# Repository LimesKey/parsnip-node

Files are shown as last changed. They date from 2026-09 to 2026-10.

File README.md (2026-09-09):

# parsnip-node
A battery-powered, portable Meshtastic/Meshcore node built around the ESP32-S3, an Ebyte E22P-915M30S LoRa front end, and a u-blox NEO-M9N GNSS receiver. Designed in KiCad, it targets 915 MHz operation in Canada under ISED RSS-247.

## Overview

The goal is a self-contained LoRa node that pairs one of the longest range, best value LoRa modules, with an accurate GNSS reciever, running off two 21700 cells in series, to connect to other people on the LoRa mesh network community.

### Schematic - v2

<table>
  <tr>
    <td align="center" width="33%">
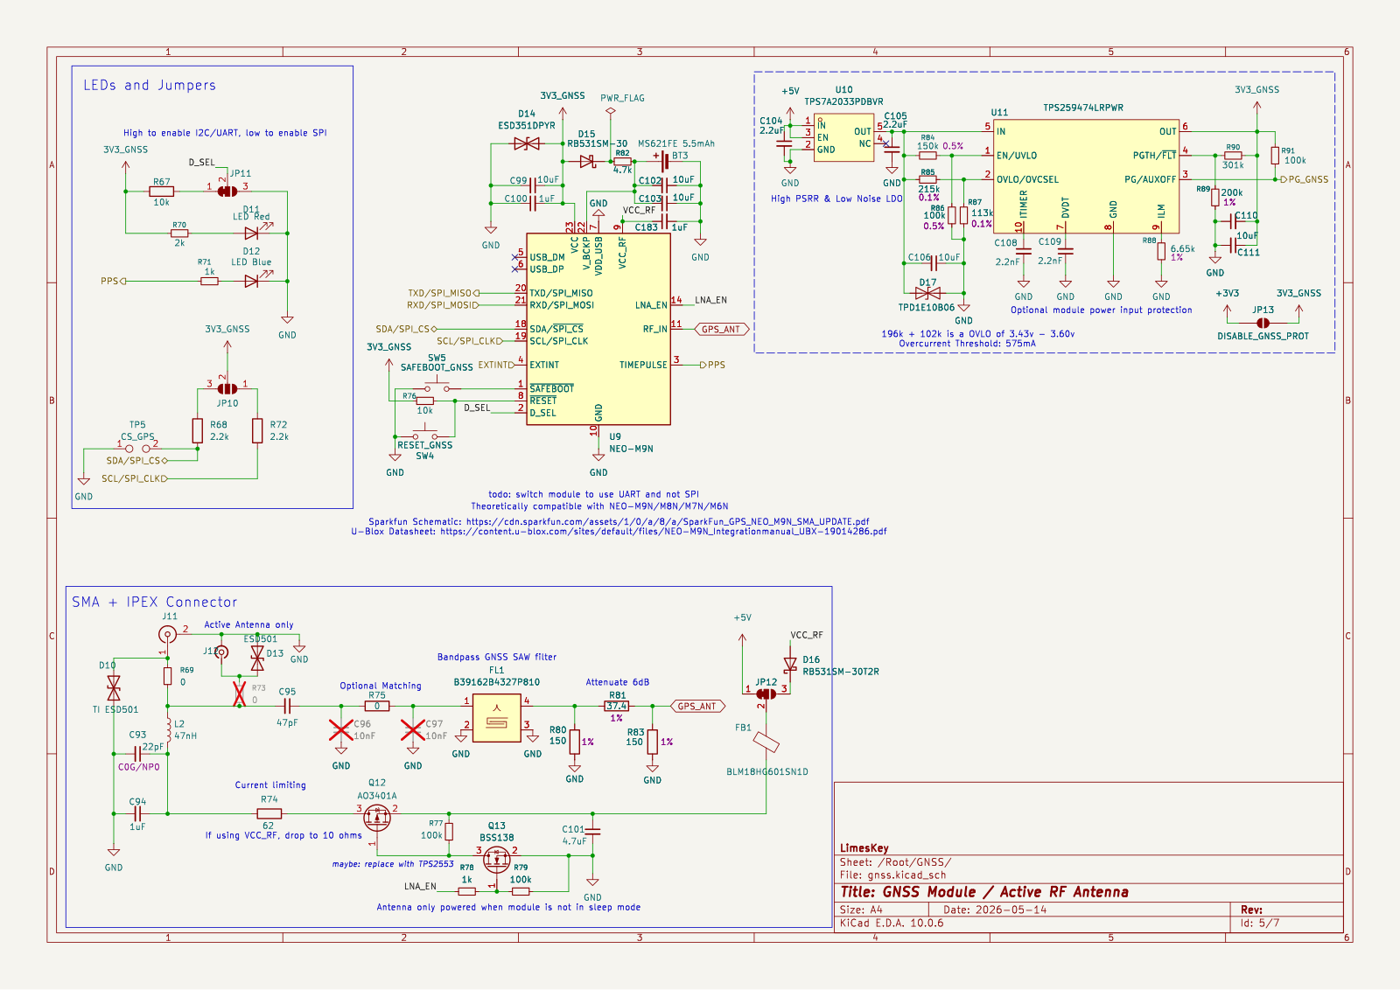
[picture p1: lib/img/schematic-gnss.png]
GNSS / active antenna schematic
      
      <br><sub><b>GNSS / active antenna</b></sub>
    </td>
    <td align="center" width="33%">
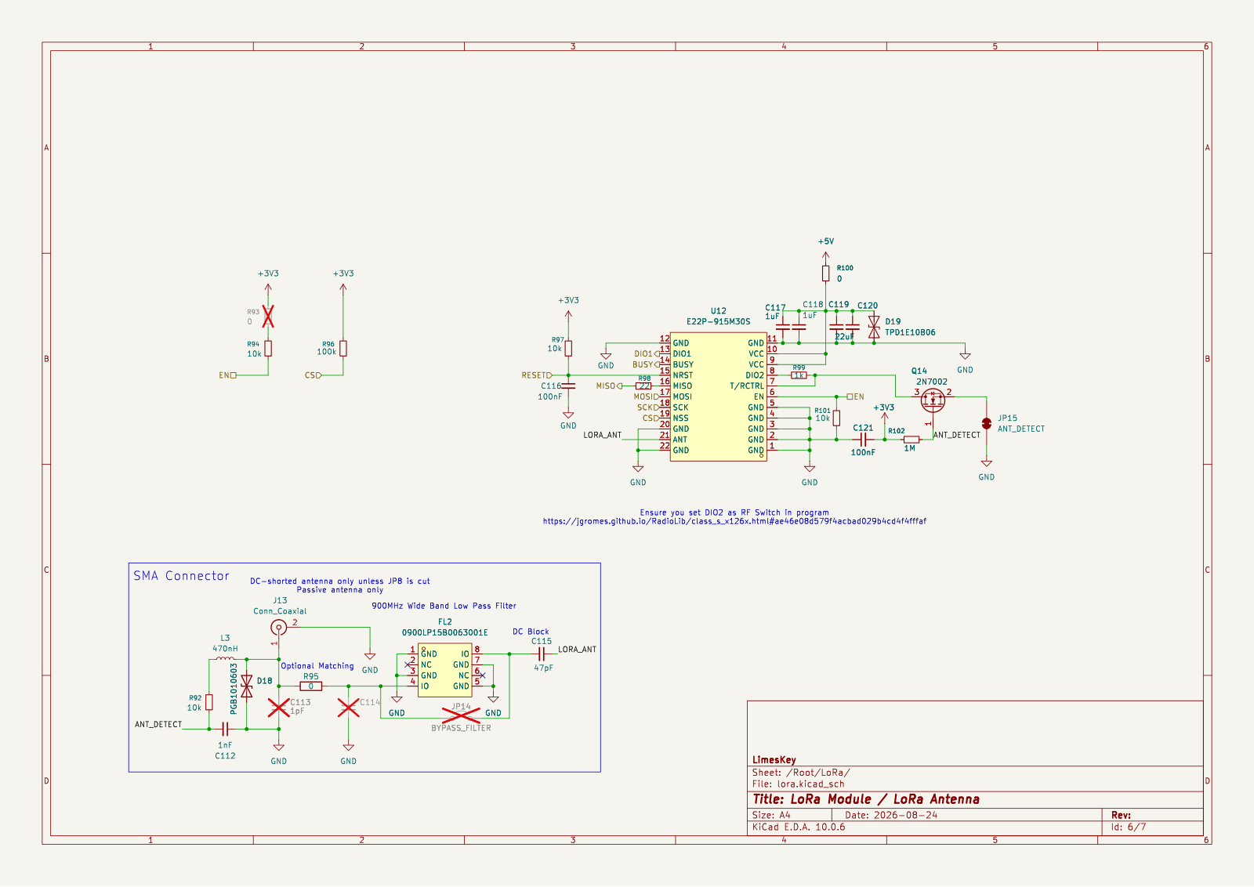
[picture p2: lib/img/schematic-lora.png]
LoRa front end schematic
      
      <br><sub><b>LoRa front end</b></sub>
    </td>
    <td align="center" width="33%">
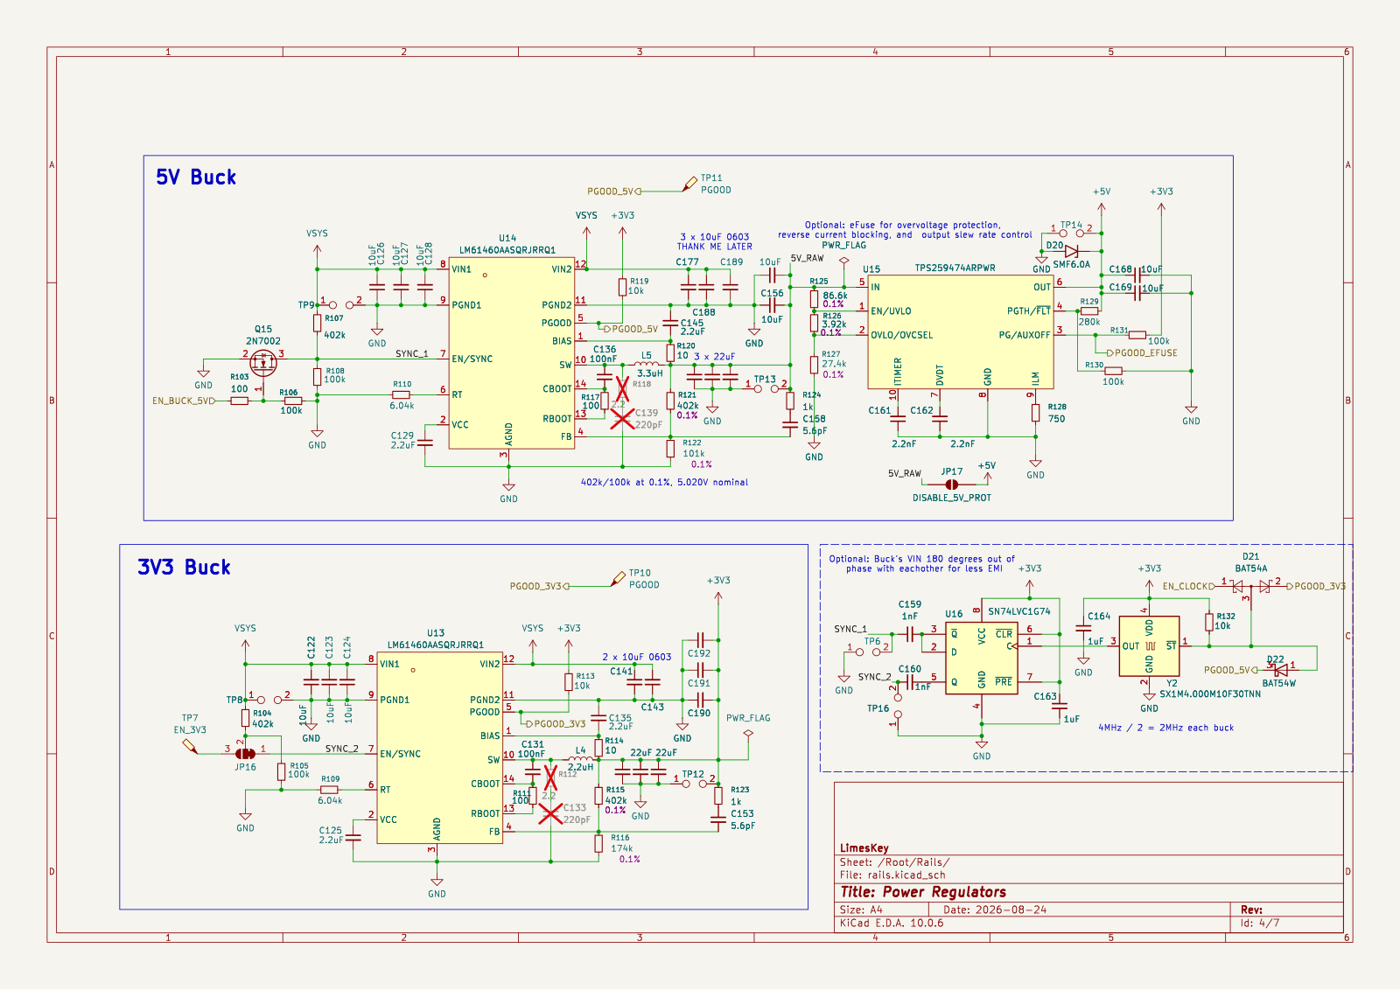
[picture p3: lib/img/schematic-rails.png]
Power rails schematic
      
      <br><sub><b>Power rails</b></sub>
    </td>
  </tr>
  <tr>
    <td align="center" width="33%">
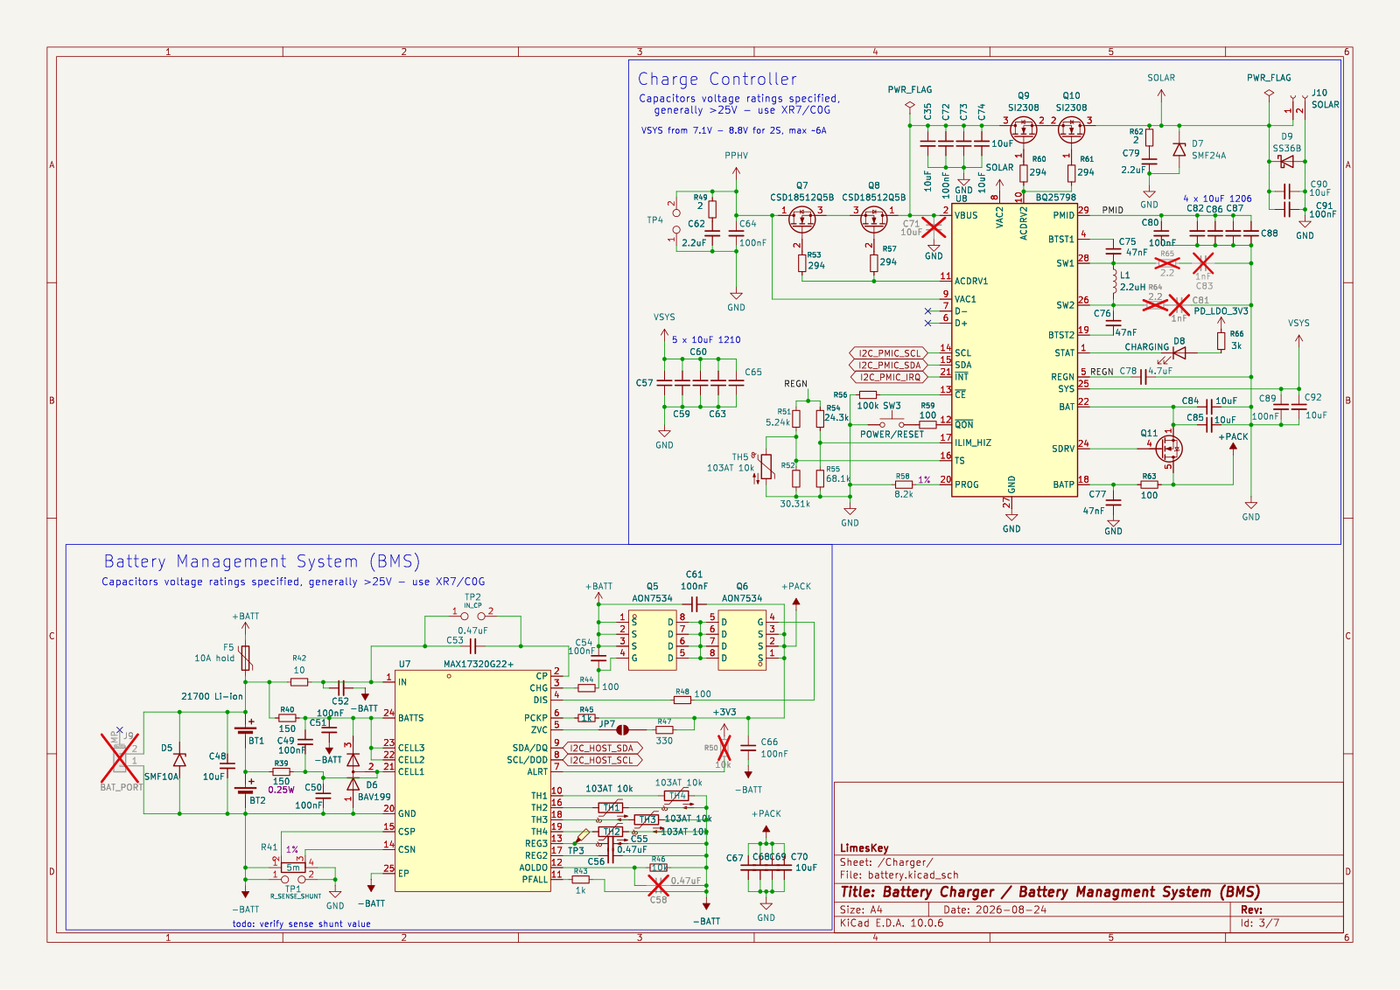
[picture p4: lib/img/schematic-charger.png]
Charger and BMS schematic
      
      <br><sub><b>Charger / BMS</b></sub>
    </td>
    <td align="center" width="33%">
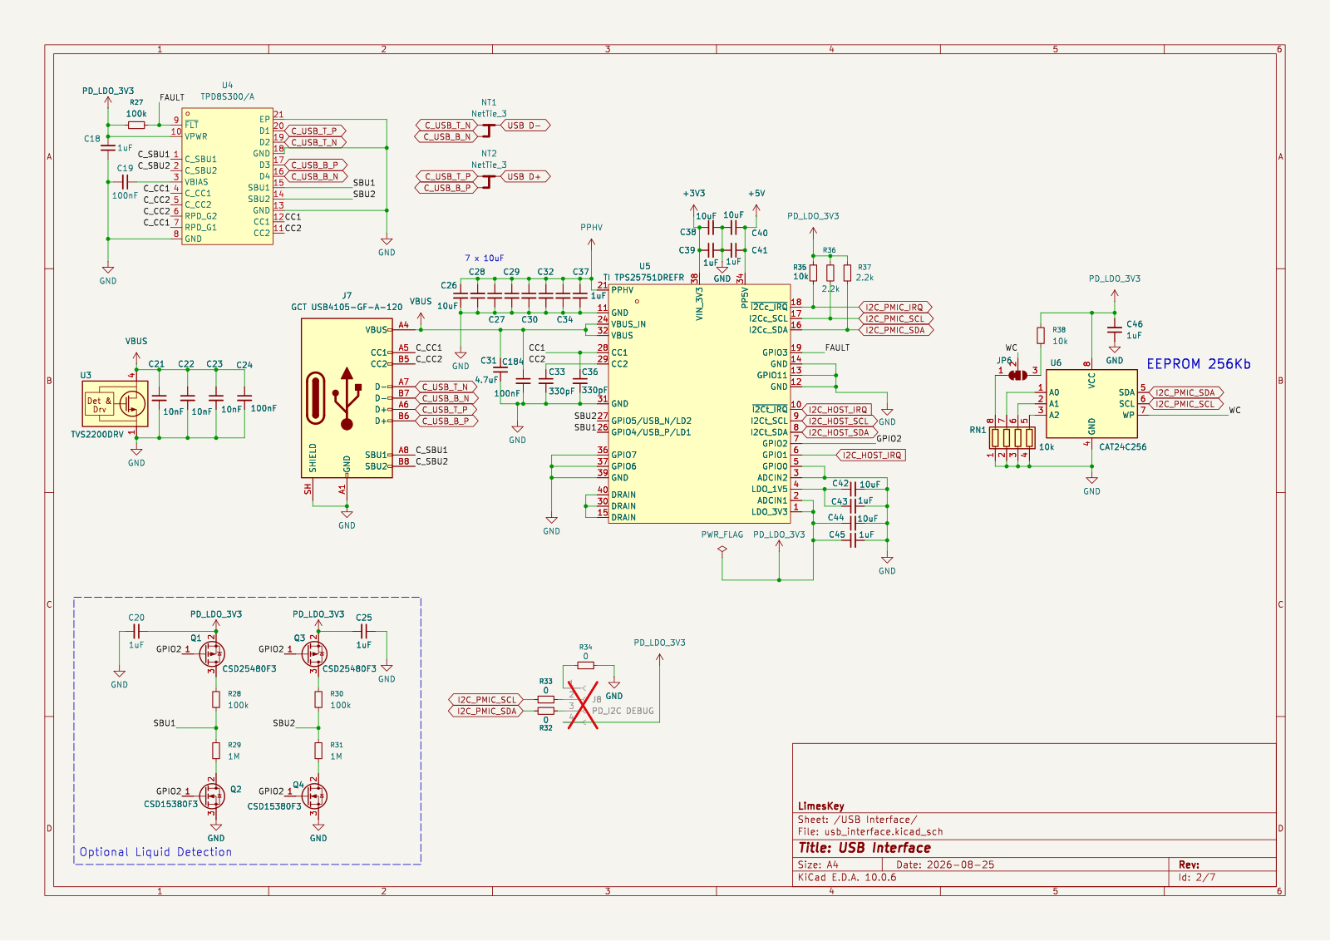
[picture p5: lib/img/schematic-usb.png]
USB-C / PD schematic
      
      <br><sub><b>USB-C / PD</b></sub>
    </td>
    <td align="center" width="33%">
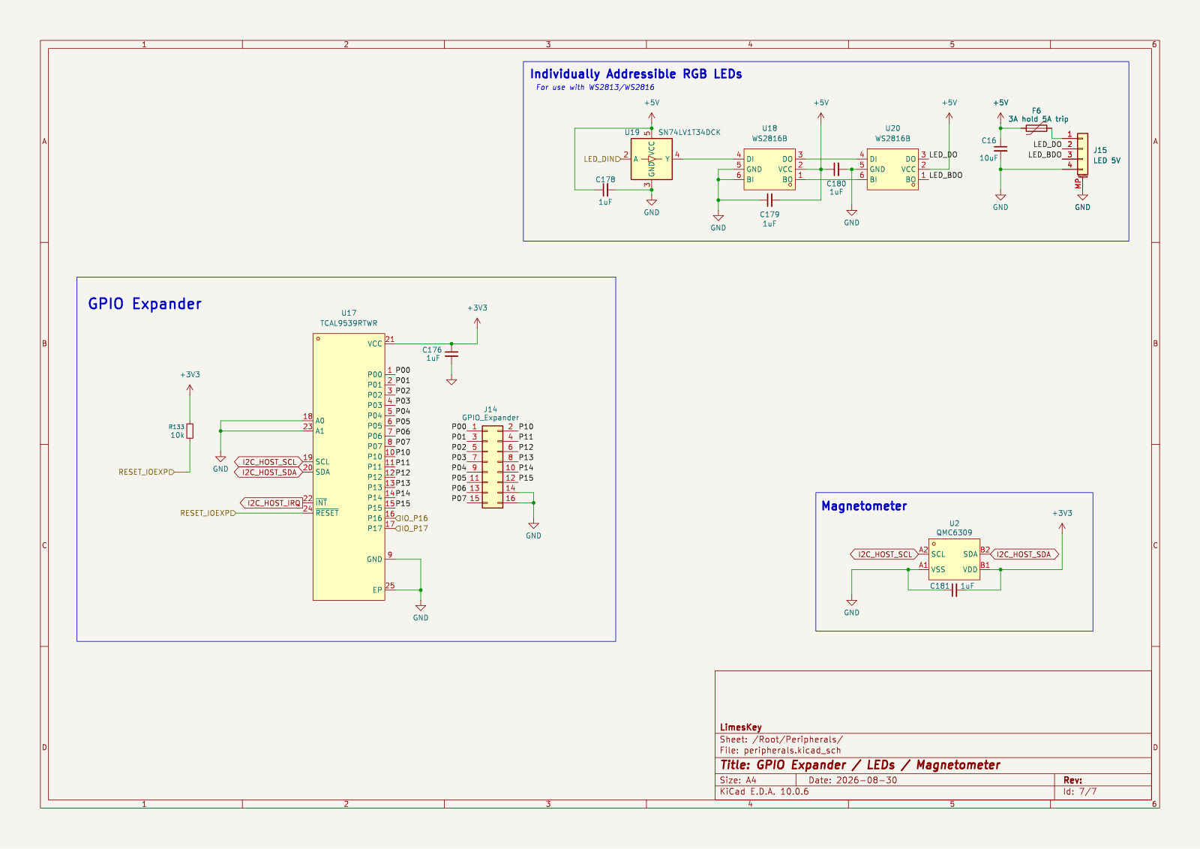
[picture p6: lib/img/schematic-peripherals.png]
Peripherals schematic
      
      <br><sub><b>Peripherals</b></sub>
    </td>
  </tr>
</table>

### PCB - v2

<p align="center">
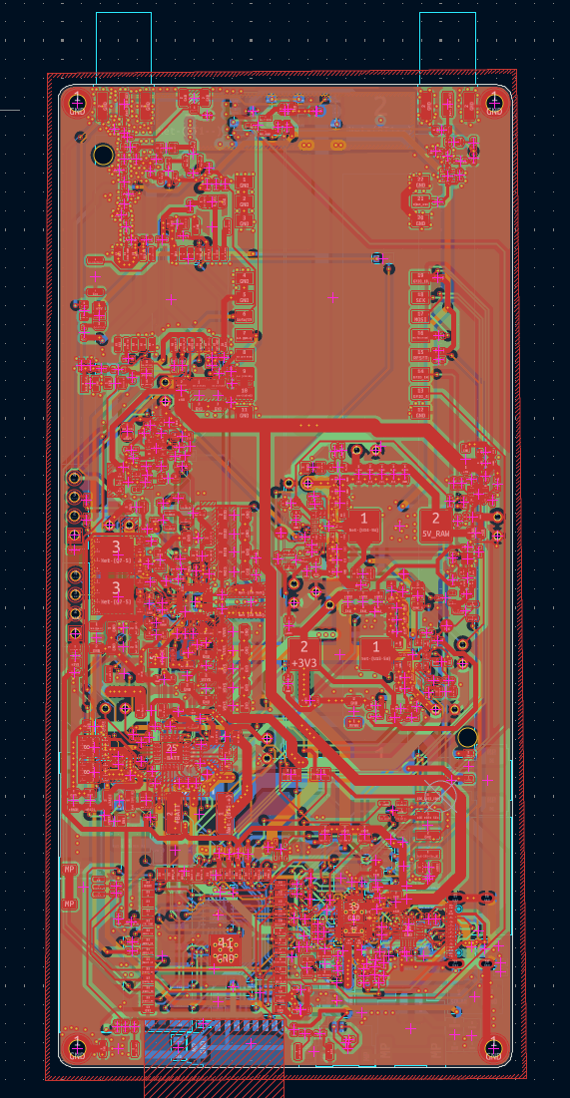
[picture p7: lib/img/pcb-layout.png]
parsnip-node PCB layout, all layers
  
</p>

### 3D Render - v2

<p align="center">
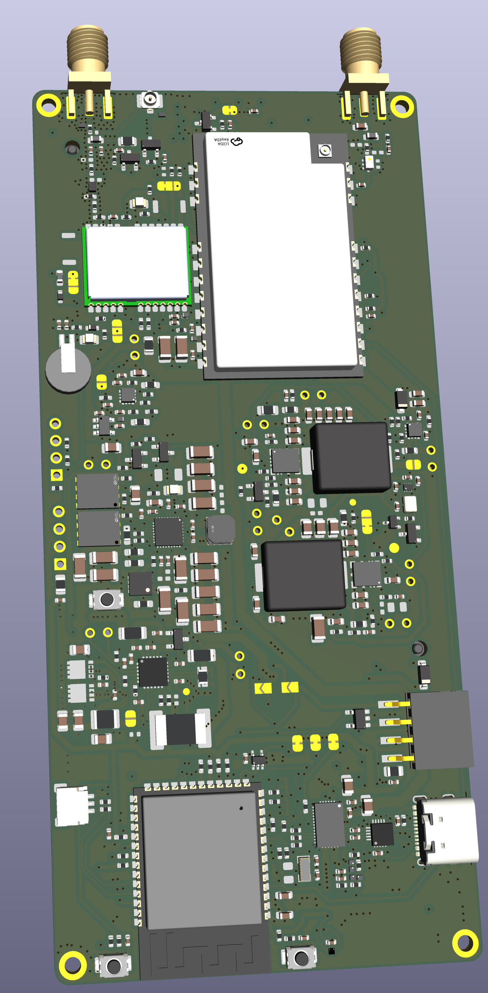
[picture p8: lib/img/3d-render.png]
parsnip-node board 3D render, front
  
</p>

### In the field - v1

<table>
  <tr>
    <td align="center" width="33%">
      Assembled parsnip-node board on the bench
      <br><sub><b>Assembled board</b></sub>
    </td>
    <td align="center" width="33%">
      parsnip-node during outdoor testing, front
      <br><sub><b>Outdoor testing</b></sub>
    </td>
    <td align="center" width="33%">
      parsnip-node during outdoor testing, back
      <br><sub><b>Outdoor testing, back</b></sub>
    </td>
  </tr>
</table>

## Hardware
 
| Part | Price |
| --- | --- |
| JLCPCB PCB w/ Assembly (to-be changed [BOM](production/bom.csv)) | $1098.04 CAD (est) |
| 21700 Cells [18650batterystore.com](https://www.18650batterystore.com/products/samsung-58e-21700-battery)| $40 CAD  |
| 3.7" E-Ink [AliExpress](https://www.aliexpress.com/item/1005009712001279.html?mp=1)| 24$ CAD |
 
### Board
 
- 4-layer with ENIG, 60 x 130 mm
- JLCPCB `JLC04161H-7628` stackup, 2 oz copper outer, 2 oz copper inner
- L1-L2 prepreg 0.2104 mm, Dk 4.4
- RF: 0.36mm trace width for ~50 Ω CPWG on this stackup, ground rails stitched with 0.3 mm / 0.6 mm vias at roughly 1.5 to 2 mm pitch
  
### ESP32-S3 GPIO pin map

Host: ESP32-S3-WROOM-1-N16R8 (U1). GPIO numbers are ESP32-S3 GPIO, not module pins.

#### LoRa - E22P-915M30S (U12)

| Signal | GPIO |
| --- | --- |
| NSS | 10 |
| SCK | 12 |
| MOSI | 11 |
| MISO | 13 |
| BUSY | 14 |
| DIO1 | 4 |
| NRST | 40 |
| EN | 41 |

#### GNSS - NEO-M9N (U9)

| Signal | GPIO |
| --- | --- |
| TXD | 1 |
| RXD | 2 |
| TIMEPULSE | 3 |
| EXTINT | 48 |
| SDA | 8 |
| SCL | 9 |

#### Other peripherals

| Function | GPIO |
| --- | --- |
| I2C SDA | 8 |
| I2C SCL | 9 |
| I2C IRQ | 7 |
| E-Ink BUSY | 5 |
| E-Ink RESET | 6 |
| E-Ink D/C | 18 |
| E-Ink CS | 17 |
| Bus CS | 38 |
| USB D- / D+ | 19 / 20 |
| UART0 TX / RX | 43 / 44 |
| RTC 32 kHz xtal | 15 / 16 |
| BOOT | 0 |
| eFuse PG | 39 / 42 |
| EMI osc gate | 47 |
| Level shifter | 46 |
| Load switch | 21 |
| PSRAM (reserved) | 35 / 36 / 37 |
| VDD_SPI (reserved) | 45 |
 
## Firmware
 
Firmware is a Meshtastic fork tracked as the `firmware` submodule ([LimesKey/firmware](https://github.com/LimesKey/firmware)). Development uses VS Code with the pioarduino extension, which Meshtastic pins for ESP32-C6 / Arduino-ESP32 3.x support. A device variant declares the pin map above and the PA control lines so TX actually keys up. Unfortunately there are some extensive changes to the Meshtastic firmware in order to incorporate a SPI GNSS module, as this is not natively supported by Meshtastic.
 
```bash
git clone --recurse-submodules https://github.com/LimesKey/parsnip-node.git
```

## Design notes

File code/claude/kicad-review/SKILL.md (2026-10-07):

---
name: kicad-review
description: >-
  Query and review KiCad netlists (.net), schematics (.kicad_sch), board placement (.kicad_pcb) and datasheets, and draw schematics: knet.py, kpcb.py, ksheet.py, ksch.py, kdoc.py. Use for any question touching a KiCad schematic, netlist, ERC, BOM, footprint, pin, net, connectivity, decoupling or power rail ("what does U2 pin 9 connect to"), and for board layout, placement, floorplan, footprint position, courtyard, edge clearance, mounting hole or keepout ("is U8 too close to the antenna"), and schematic-sheet geometry or readability ("where is U7 on the sheet", "is this drawing misleading", "show me that part of the schematic"). `kpcb.py FILE ic U13` also RECOMMENDS where a regulator's caps, inductor and feedback divider go, with a diagram: use it for "where do these go", "lay out this buck/LDO", "minimise the switching loop". Never answer connectivity or geometry from memory or by eyeballing a schematic or board image; exports go stale within a session. Use it too for ANY request to draw or show a circuit, even one not on the board yet: ksch.py draws real symbols from a text spec and hand-written SVG is never right.
---

# KiCad netlist review, placement review and schematic drawing

Stdlib-only tools in this skill's `scripts/`. Nothing to install (`view` uses
`rsvg-convert` when present).

```bash
K=<skill>/scripts/knet.py   P=<skill>/scripts/kpcb.py   H=<skill>/scripts/ksheet.py
D=<skill>/scripts/kdoc.py   S=<skill>/scripts/ksch.py
```

| question | file | tool | reference |
| --- | --- | --- | --- |
| what is wired to what, values, BOM | `.net` | `knet.py` | [knet](references/knet.md) |
| where is it, does it fit, does it clash, where do the passives go | `.kicad_pcb` | `kpcb.py` | [kpcb](references/kpcb.md) |
| does it pass DRC/ERC, real clearance/rule violations | `.kicad_pcb` + roots | `kdrc.py` | [kdrc](references/kdrc.md) |
| what does the part's datasheet say | PDFs | `kdoc.py` | [kdoc](references/kdoc.md) |
| where is it on the schematic sheet, is the drawing readable, show me that region | `.kicad_sch` + `.net` | `ksheet.py` | [ksheet](references/ksheet.md) |
| show me the circuit | - | `ksch.py` | [ksch](references/ksch.md) |
| rename / reorder / renumber / add a sheet, prove nothing else changed, keep the cover / block diagram / power tree true | `.kicad_pro` + sheets | `kproj.py`, `kverify.py`, `kfront.py` | [kproj](references/kproj.md) |

`knet check` and `kpcb check` are heuristics on the netlist and placement;
`kdrc.py` runs **KiCad's own** DRC (honouring `parsnip.kicad_dru`) and ERC, the
authoritative rules check. `kpcb.py FILE zones` reports pour-fill coverage.

All the tools share `kcommon.py` (the S-expr parser, the value/ref helpers, the
footprint-library resolver, the `Netlist` + `SchInfo` model and the finding
formatter). It has no CLI of its own - edit it once and every tool sees it; the
dependency only points tools -> kcommon. Parsed files over 100 kB are cached in
`~/.cache/kicad-review` (marshal, keyed on path + size + mtime; one snapshot per
file; the oldest entries go once it passes 512 MB), and zone fills are parsed only
by the commands that read them, so most kpcb calls on the 12 MB board take ~0.3 s. `kzo.py`
(trace impedance, the CPWG field solver) is kpcb's only other import.
`kpcb.py` needs `kcommon.py` beside it but does **not** need the
`.net` - pads carry their own net names and pin functions. Find the `.net` first:
usually beside the board, else `/mnt/project/*.net` or `/mnt/user-data/uploads/*.net`.
If `*.kicad_sch` files sit beside the `.net`, knet parses them as a sidecar
(no_connect flags, text notes, symbol positions). A sheet saved after the `.net`
makes every loader re-run kmerge first (~3 s, `KREVIEW_NO_REGEN=1` opts out), and a
`.net` lacking a top-level sheet the `.kicad_pro` lists is warned about.

**KiCad stable and nightly both work.** kpcb reads 10.0 `(at X Y R)` and 10.99
`(transform (translate) (rotate))` placement. Tools that shell out (`kdrc`, `kmerge`,
`kpcb height`) pick `kicad-cli-nightly` for a file saved by 10.99 (`generator_version
"10.99"`), else `kicad-cli`; `$KICAD_CLI` overrides. For a multi-root project,
`kmerge.py OUT.net ROOT.kicad_sch` builds the whole-board netlist (other top-level
sheets come from the `.kicad_pro`; a nightly export that already has them passes
through verbatim).

## Order of operations

1. **Connectivity, values, footprints, part numbers -> `knet.py`.** The netlist is
   the only authoritative record of what is wired to what.
2. **Position, clearance, floorplan -> `kpcb.py`.** The board file is the only
   record of where anything actually is. Never infer geometry from a screenshot.
3. **Design rules, absolute maximums, recommended values -> `kdoc.py grep`.**
4. **Page image -> only when the drawing itself must be read.** `kdoc.py page DOC N`
   prints a path, then `view` it.

Never derive connectivity from a schematic plot: extracted text is spatially
scrambled. The plot only tells you which sheet a symbol lives on.

## Start here - the highest-value call per tool

| you want | one call |
| --- | --- |
| fresh session on a board | `kpcb.py FILE review` - sync + summary + check + span, then names the next calls to make |
| is the board the circuit I drew | `kpcb.py FILE sync` - **run before quoting any placement finding**; two lines when clean |
| where does X connect / is X right | `knet.py FILE around X` - pins, types, nets, position, every part one hop away |
| where is X, is there room | `kpcb.py FILE where REF` or `where 130,60 -r 10` (`--origin grid` = the numbers KiCad's Properties dialog shows) |
| where do these caps/inductor go | `kpcb.py FILE ic U13` - positions, rotations, the rule behind each, and a picture |
| does the board pass real DRC + ERC | `kdrc.py FILE.kicad_pcb` - KiCad's own checks, every root, folded like `check`; flags a STALE saved zone fill (what gerbers export) |
| which PWR_FLAGs are needed / redundant | `kdrc.py FILE.kicad_pcb flags` - each flag's net, and whether ERC fails without it |
| does the SMA/USB-C sit on the edge its footprint expects / how far is a side-entry housing set back | `kpcb.py FILE check --only EDGEREF` |
| is the ground pour filled / covering | `kpcb.py FILE zones` - fill coverage per copper layer |
| can a net carry its current / is the trace too thin | `kpcb.py FILE ampacity NET --amps X` - IPC-2221 vs the routed copper + vias |
| does the power path between two pads carry X A | `kpcb.py FILE ampacity --from Q16.1 --to R41.1 --amps 6` - current split by conductance, pours as conductors, hottest tracks/vias |
| is the net's copper one piece | `kpcb.py FILE net NET` - ends with `copper one piece` or the pads cut off |
| pour islands KiCad removed / where a stitching via rescues one | `kpcb.py FILE zones --voids` |
| where is U7 on its sheet, what is near it, with nets | `ksheet.py FILE.net sch U7` |
| is the schematic drawing misleading (wire through a body, bypass-looking gaps) | `ksheet.py FILE.net lint [--around REF]` |
| picture of a schematic region | `ksheet.py FILE.net view REF` -> PNG path |
| can I nudge X here / where along this line is clear / can this via move | `kpcb.py FILE movecheck REF X Y [ROT]`, `REF --scan x=X y=A..B`, `via X,Y NX,NY` - new hits only, read-only |
| what is almost-but-not-quite aligned (tidy placement pass) | `kpcb.py FILE tidy` - REF now -> new, each pre-checked with movecheck; the whole pass is a recipe in [recipes](references/recipes.md) |
| where does a W x H logo/label fit on the silk | `kpcb.py FILE freebox f 8 4` - best centre per free region |
| are the logos visible / what hides them / do they run over pads | `kpcb.py FILE silk` |
| picture of a board region (chosen layers) | `kpcb.py FILE view REF [-r 5] [--layers B.Cu,B.SilkS]` -> PNG path |
| where is this PAD / how far apart are two pads | `kpcb.py FILE where F5.1 BT1.1` |
| everything on one net, with coordinates | `kpcb.py FILE net NET` - pads (absolute xy), copper per layer, vias, zones |
| is this 50-ohm trace right | `kpcb.py FILE rf [NET]` - width necks, microstrip Zo, GND gap + field-solved CPWG Zo, reference plane, via fence |
| what width/gap gives 50 ohm (not routed yet) | `kzo.py W S H ER [T] --mask TM ERM` - the same 2D field solver, one number |
| how thick is the assembled board / what sticks up | `kpcb.py FILE height` - 3D-model heights + the Z stack at each cell |
| vias in pads worth a fab note | `kpcb.py FILE viapad --signal` (or `--min 4` for thermal arrays) |
| what does a backwards cell or pack do | `knet.py FILE revpol` - junctions that conduct (fused?), FETs the cells switch, ICs that lose ground, IC pins pushed below GND with their ESD current |
| what voltage does this divider set | `knet.py FILE divider U5.OVLO` - nominal + worst case from real resistor values |
| what feeds what, every rail, each buck's Vout and eFuse ILIM | `knet.py FILE powertree` - sources -> FETs/regulators -> rails -> loads |
| which I2C address is each part, any duplicates | `knet.py FILE i2c` - per bus: controller, targets, addresses resolved from strap pins |
| via sizes, drills, aspect ratio | `kpcb.py FILE vias` |
| rename/reorder/renumber sheets, then prove the circuit did not change | `kproj.py DIR ...`, then `kverify.py DIR` - one PASS/FAIL line per check |
| do the cover, block diagram, power tree still match the board | `kfront.py FILE.net check` and `pages` |
| why won't the file open / which KiCad opens it / is KiCad holding the project | `kdrc.py FILE.kicad_pcb doctor` |
| unfamiliar board, what is on it | `knet.py FILE summary` then `check` |
| draw a circuit that exists | `knet.py FILE draw U8 -d 2 -o out.svg` |
| draw a circuit that does not exist yet | write a ksch spec, `ksch.py render` - see [ksch](references/ksch.md) |
| what does the datasheet say | `kdoc.py grep 'Y' --count` to pick the page, then grep with context |

More in [references/recipes.md](references/recipes.md), including the self-test to
run after editing any tool, and the 5-line import for an ad-hoc query (Board,
Netlist, load_sexp) - never re-implement paren matching in an inline script.

## Hard rules

- **Re-run the tool every time.** The `.net` and the board are re-exported
  constantly. Never trust a value, ref, net name or coordinate quoted earlier in
  the conversation, in a summary, or in a CLAUDE.md.
- **Never hand-regex a netlist or board file.** It bleeds nodes across net
  boundaries and produces confidently wrong counts.
- **Never hand-write SVG for a circuit.** `ksch.py` draws real symbols.
- **`check` findings are heuristics.** Confirm against the datasheet
  (`kdoc.py grep`) before calling anything a bug.
- **Output is capped on purpose.** Findings fold into `tail [N]: refs` lines and
  each rule stops after `--max`. The counts in the tails stay accurate even when
  not every item is printed: `+90 more OVERLAP line(s) (102 total)` means 102 real
  findings. Widen deliberately with `--only RULE` or `--max`, never by default.
- **Mid-placement, most of the BOM is parked beside the board.** Every kpcb check
  ignores anything outside the outline. `placed 135 of 439` is progress, not an
  error, and a part "not found" by `where` may not exist on the board yet.

Common traps that produce wrong answers - DNP as open circuit, ref-prefix
matching, rails being terminal, `unconnected-*` pseudo-nets, KiCad's `{slash}`
escaping, board y growing downward - are in
[references/gotchas.md](references/gotchas.md). Read it once per session before
any traversal or coordinate work.

Exit codes (both tools): 0 clean, 1 not found, 2 a check found an ERROR, 3 bad file.

Project config: `knet.json` / `kpcb.json` beside the file persist board defaults
and a `suppress` list for confirmed non-bugs. Precedence: defaults < json < CLI.
See the per-tool references.

# Related

Part sourcing (LCSC/DigiKey pricing, stock, verified datasheet URLs) is the
separate `part-search` skill. `part.py bom board.net` reuses this skill's parser.
Capacitor questions mid-review - "higher voltage rating or higher nominal
capacitance", DC-bias derating, effective uF in a footprint, voltage-stress life -
go to that skill's `kcap.py`, not to hand-computed derating curves.

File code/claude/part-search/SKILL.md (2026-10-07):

---
name: part-search
description: Look up and choose electronic components on LCSC, JLCPCB and DigiKey with part.py. Does parametric selection (e.g. a ceramic cap 4.7uF-100uF rated >=25V, cheapest first), finds cheaper drop-in alternates for a part on the board, reports JLCPCB Basic vs Extended and $3/line assembly fees, runs one-shot board sourcing triage, and returns pricing ladders, stock, MOQ and a verified datasheet URL. Use this whenever the user asks about a specific component, an LCSC C-number, an MPN, a distributor price, whether something is in stock, what a part costs at some quantity, what the datasheet link is, asks to compare two parts, asks to pick or find a part meeting electrical constraints, asks for the best or best-value part for an application (lowest Iq, RDS(on), noise), asks whether a part is JLC Basic, or asks to price or source a whole board. Use it instead of web search for anything part-shaped, and never hand-write a scraping script for LCSC - the working endpoints are already recorded here and the obvious ones are blocked.
---

# Distributor part search and selection

`scripts/part.py` is stdlib-only Python 3. No install, no API key needed for LCSC or JLC.

Code map (to patch one command, open only its module): `part.py` is the CLI plus
`search`/`show`/`ds`/`compare`/`selftest`; HTTP, cache, FX and the LCSC/DigiKey/JLC/
Mouser clients are `part_core.py`; value parsing and the constraint grammar `part_value.py`;
`pick`/`alt` `part_pick.py`; `bom`/`jlc`/`check` `part_bom.py`; `fpcheck` `part_fpcheck.py`.

```bash
P=<this-skill>/scripts/part.py
python3 $P selftest
python3 $P pick MLCC --cap 4.7u..100u --volt '>=25' --pkg 0805 --diel X7R,X5R
```

## Pick the command by what is being asked

| the question | command |
| --- | --- |
| "find me a cap 4.7-100 uF, >=25 V, cheapest" | `pick` - see [pick](references/pick.md) |
| "the BEST LDO / FET / TVS for <application>", "lowest Iq", "best value" | read [best](references/best.md): limits from the board, `pick --sort ATTR` / `--pareto ATTR` `--xcheck`, verify the top 3 in the datasheet. The tool gathers specs; you judge |
| "something like TPS2553 but lower RDS(on)" | `pick --like C55266 --rdson '<=50m'` (category + package from the part, limits from you) |
| "find a TVS / LDO / I/O expander / test point that ..." | `pick TVS --pkg ... --vrwm ...` (the part-type word selects the JLC category; `--cat` to force one) |
| "is there something cheaper than C45783" / "C45783 is out of stock" | `alt C45783` (nothing? it lists near misses that fail one limit) |
| "is brand X (CCTC, Chinocera, ...) any good" | read [brands](references/brands.md) - no search needed |
| "what does C18164413 cost / is it stocked" | `show` |
| "is this part JLC Basic", "what are my assembly fees" | `jlc` - see [endpoints](references/endpoints.md) |
| "datasheet link for X" | `ds` |
| "get the datasheet so I can grep it" | `ds C... --save` |
| "X vs Y" | `compare` (LCSC, JLC and DigiKey rows in one table: `compare C.. MPN --provider digikey`) |
| "what does this whole board cost" | `bom` |
| "source this board" / "what's blocking assembly" | `check` - `bom` + `jlc` + missing-code triage in one call |
| "do my footprints/values match the parts" / "any wrong packages or values" | `fpcheck` - KiCad footprint + value vs the LCSC part, per part |
| bare MPN, no constraints, just find it | `search` |
| "higher voltage rating or more nominal uF?" / DC-bias derating | `kcap.py` - see [kcap](references/kcap.md) |

`search` is keyword-only: LCSC rows rank on MPN text, so `search '22uF 25V X7R 1206'`
returns electrolytics and tantalums, and category words ('test point') return junk;
the JLC rows it adds match category words better. **For anything with electrical
constraints, use `pick`, not `search`.**

## Choosing a part, end to end

1. `pick <part type> --pkg ... --<limits>` - the cheapest in-stock (>=100, not EOL)
   parts that meet every limit; with a category the limits filter JLC server-side,
   so the pool is exact. Unsure what the attributes are called? `--fields`. A name
   the category lacks gets a `did you mean` line, and a `coverage:` line says when an
   attribute is listed on only part of the category. `clone? of` marks a row whose
   MPN copies an earlier maker's.
2. `compare C.. C.. C..` on the shortlist - only the parameters that differ
   (`--attrs` for all). Rows merge across catalog spellings, values in SI units.
3. `ds C.. --save`, then `kdoc.py grep 'Absolute Maximum' -d <MPN>` (kicad-review) for
   what LCSC's parameters do not carry: abs max, recommended operating range,
   derating, pinout, land pattern. A dimension off a drawing: `kdoc.py page`.
4. MLCC at a real DC bias: `kcap.py compare` (effective uF, not nominal).

## Commands

| command | use |
| --- | --- |
| `pick 'MLCC' --cap 4.7u..100u --volt '>=25'` | parametric selection, sorted, filtered |
| `alt C45783` | drop-ins for a part already on the board: same JLC category and package, equal-or-better on every rated parameter (voltage/current up, RDS(on)/Vf/leakage/clamp down, type/polarity equal); prints the holds as `--w` flags to loosen |
| `jlc board.net` | Basic vs Extended per part + total $3/line assembly fees |
| `show C18164413` | ladder, stock, MOQ, multiple, params, category, verified datasheet |
| `ds C42409135` | datasheet URL only, with pass/fail per candidate |
| `ds C42409135 --save [--dir D] [--name N]` | ...then download the verified PDF to `docs/datasheets/<PART>.pdf` (the base part number, uppercase: a ti.com link names it, `BQ25798RQMR` -> `BQ25798`; else the MPN cut at `,` `(` `+` `#`; vendor variant codes like `NEO-F10N-00B` need `--name NEO-F10N`; companion docs `--name <PART>_<DocType>`), or `docs/datasheets/<sheet>/` when that folder is split per sheet (sheet from the netlist; refuses and asks for `--dir` when it can't tell) (checks the `%PDF` header, keeps an existing file unless `--fresh`) and `kdoc.py index` it (with `--ocr` when any page is image-only, like Sunlord's catalogs), so `kdoc.py grep -d <MPN>` works next |
| `compare C1525 C60474` | side-by-side, differing parameters only |
| `search 'TPS61033'` | keyword search, LCSC rows then JLC rows (JLC catalog price, spec string as desc). Add `--instock`. |
| `bom board.net --qty 5` | prices a whole KiCad netlist by its LCSC Part property |
| `check board.net --qty 5` | one-shot sourcing triage: `bom` pricing + `jlc` Basic/Extended, one table, one pass over the netlist |
| `fpcheck board.net` | each symbol's KiCad footprint AND value vs the assigned LCSC part. Footprint: flags size/family mismatches and one LCSC code reused across different bodies (chip sizes and MPN-named footprints auto-clear; divergent nomenclature -> a small REVIEW bucket). Value: R/C/L symbol value vs LCSC's resistance/capacitance/inductance param (catches a right-footprint, wrong-value part, e.g. a 36R part on a 37.4R symbol). MPN: the symbol's `MPN` field vs the code's part (a swapped `LCSC Part` or a stale MPN) is a MISMATCH. The header counts rows: a code on two footprints or values is two. Body sizes stated in both names (`DFN-8(3x3)` vs `_2x2mm`) must agree. Leadless parts (DFN/QFN/SON/LGA/PicoStar) also get a **land check**: the board footprint's copper extent and largest pad vs the EasyEDA footprint LCSC links to the code (the one JLC assembles on); a >25% pad / >20% extent difference goes to REVIEW even if `fpcheck.json` confirmed the names (only a `--datasheet` land confirmation clears it); a custom pad counts its primitives, not just its anchor. Board = the one `.kicad_pcb` beside the netlist or `--pcb`; `--no-land` skips it (EasyEDA 403s after ~150 quick calls; results cache 30 days). Also lists any assigned part LCSC marks EOL/NRND. `--show-ok`, `--json`; no `.net` runs the offline self-test. |
| `selftest` | which providers and the FX rate source work right now |

`show`, `ds`, `compare` and `alt` accept a C-code, a bare MPN, or a pasted LCSC URL.
A JLC-assembly-only code (not sold retail on LCSC, e.g. C408408, C51912672) falls back
to JLC's record, labelled `[JLC ...]` with JLC catalog prices; `bom`/`check` list those
separately and never add them to the LCSC total, and `fpcheck` checks them.
`show` with several SKUs prints one verbose block per part by default; `--table`
switches to one compact row per part, `--json` for machine-readable output.
Exit codes: 0 ok, 1 nothing found.

## fpcheck: the REVIEW bucket and confirming equivalences

`fpcheck` sorts every part into MISMATCH (footprint size/family or value
disagrees - real, fix it), REVIEW (the LCSC package string and the KiCad
footprint name read differently and the matcher can't tell if the body is the
same), and OK. REVIEW is a "look at these", not a bug list. Work it once:

- **Same body, different wording** -> record it so it never comes back.
  `part.py fpcheck board.net --confirm C22445413 C233771 --note "why"` writes the
  (package, footprint) pair to `fpcheck.json` beside the board; future runs
  auto-clear it as "confirmed equivalent". The objective test for "same body" is
  **dimensions + pin count**: LCSC `WQFN-24-EP(4x4)` vs KiCad `TQFN-24_L4.0-W4.0...EP`
  is the same land, just different names. easyeda2kicad-generated footprints
  (`..._L#-W#-P#`, `Texas_*`, vendor-named) are the part's own land pattern, so a
  name-only difference there is safe to confirm.
- **Genuinely a different part** -> do NOT confirm. This is a footprint borrowed
  from another vendor's similarly sized part, or the pad count differs from the
  part's lead count (e.g. a 4-pin switch on a 2-pad footprint). Verify the land
  pattern against the datasheet and fix the footprint if wrong. A false confirm
  hides a real footprint bug, so when unsure, leave it in REVIEW.

`fpcheck.json` is board data like `knet.json`/`kpcb.json` - **commit it** so the
confirmations persist across sessions. `--confirm` never clears a MISMATCH or the
"same code on two bodies" flag. A confirmation is keyed on the package WORDING, so
it covers every part LCSC files under that string; the land check is what catches a
same-wording part of another size (CSD25480F3 -> CSD25481F4 both read `PicoStar-3`).

A **"land differs"** row needs the datasheet: EasyEDA's land is sometimes the
wrong one (D17/D19: TI's DPY0002A is 2x 0.3x0.5, EasyEDA has 0.6x0.6). Compare
the board pads with the datasheet's recommended land (`kdoc.py grep 'EXAMPLE BOARD
LAYOUT' -d DOC`), and if the board matches, `--confirm C48260 --datasheet
'TPD1E10B06 p20' --note ...`. Without `--datasheet` it refuses (exit 1). The entry
stores the diff text, so it re-flags as soon as the board pads or EasyEDA's land
change.

## Run selftest first in a new session

(`selftest --offline` is the no-network logic check to run after editing part.py;
`selftest --golden DIR board.net` records 18 real outputs on its first run and diffs
them after, with every cached reply frozen - a refactor must leave them unchanged.)

LCSC has no public API. `part.py` uses undocumented endpoints that can start
returning 403/404 without notice. `selftest` reports in one line which providers are
alive, so you never debug endpoints by hand or rebuild a scraper.

If a provider shows DEAD, the endpoint moved. **The constants are at the top of
`part_core.py`. Do not write a replacement script; fix the constant.** The full probed
endpoint table, and the exhaustive list of LCSC filter/sort parameters that were
tested and do not work, are in [references/endpoints.md](references/endpoints.md).
That file exists so nobody re-probes them. Read it before touching the HTTP layer,
not before a normal query.

## Hard rules

- **Two catalogs, never add them together.** `show`, `compare`, `bom`, `pick` and
  `alt` report **LCSC retail** prices (`pick` pools from JLC's index, then re-prices
  the shown rows from LCSC; a row it could not is labelled `JLC price`). `jlc`,
  `pick --basic` and the JLC rows of `search` report **JLCPCB assembly-catalog**
  prices. They agree within ~1% but are different numbers. Say which one you quote.
- **A trailing `!` on a price means FX was unreachable** and the native currency is
  shown unconverted. Never add a `!` price to a converted one. Default currency is
  CAD; LCSC arrives in USD, converted at a daily cached rate with the native figure
  in parentheses. `--currency USD` switches everything.
- **`bom` totals exclude shipping, tax, PCB fabrication and assembly.** Say so when
  quoting a per-board cost. Extended line fees are `jlc`'s job, not `bom`'s.
- **Never regex a netlist for `C\d+`** to find LCSC codes - that matches capacitor
  refdes like `C108`. `jlc`/`bom` parse the `LCSC Part` property via kicad-review's
  `knet.py`.
- **Do not infer Basic/Extended from a JLC keyword search** - its relevance ranking
  drops parts that do exist in the library, showing as a false `-`. Use `--basic` or
  the `jlc` command.
- **Check the `resolved:` line** that `pick` prints when a shorthand mapped to a
  differently-named LCSC attribute. If it resolved wrong, use `--w` with the verbatim
  name.
- **Datasheet links are verified, not returned on faith** (HTTP status, content type,
  `%PDF` magic). A BROKEN report is real - do not paste the URL anyway.

## What the tool does that a hand-rolled script will not

- Verified datasheet links, falling through to the next candidate then the product
  page. Manufacturer links with expiring `?ts=` tokens are exactly what this catches.
- Quantity pricing respects MOQ and order multiple, and says when it rounded up.
- Numeric comparison is numeric - value normalisation drops the decimal point, so a
  text match would treat `2.2uF` and `22uF` as identical.
- Disk cache, 24 h TTL, `~/.cache/partsearch`. A warm `pick` is ~1 s against a ~10-30 s
  cold one. `--fresh` when stock matters.
- `bom` honours DNP and `exclude_from_bom`, and separately lists placed parts with no
  LCSC number at all - the ones actually blocking assembly.

- `pick`/`alt` drop parts under `--minstock` (default 100, LCSC stock) and parts LCSC
  marks EOL/NRND, and say how many in the header.

Stock is authoritative from the detail endpoint; a 0 in search results is a real 0.
`pick` shows `unit@N` and `ext` (= unit x the actual buy quantity after MOQ rounding).

DigiKey is optional: `search`/`show`/`compare`, and `pick --source digikey` (its own
parametric search, DigiKey prices) or `pick --xcheck` (both catalogs, one spec
table). Mouser (`--provider mouser`, needs a free key) serves `search`/`show` only: no
parametric filter. Setup in [references/endpoints.md](references/endpoints.md).

## Related

`kicad-review` provides `knet.py`, whose netlist parser `bom` and `jlc` import when
both skills are installed. Without it, `bom` falls back to regex and `jlc` refuses
`.net` input rather than risk matching refdes.

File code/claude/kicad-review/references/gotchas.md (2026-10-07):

# Facts that are easy to get wrong

Read this once per session before any traversal or coordinate work.

## Netlist

- **The `.net` is re-exported constantly.** Re-run the tool. Do not trust a value,
  ref or net name quoted earlier in the conversation or in a summary.
- **DNP parts are open circuits by default.** A DNP 0 R in series means the path
  does not exist on the built board; `walk`/`path`/`draw` stop there. `--as-drawn`
  restores schematic-as-drawn traversal; DNP parts still render, dashed.
- **Ref prefix matching must use the full alphabetic prefix.** `JP` is not `J`.
- **Rails are terminal in traversal.** A path through GND or +3V3 is not a path.
  Treat nets over ~8 nodes as rails.
- **Floating pins rarely show as "absent from all nets".** KiCad emits pseudo-nets
  named `unconnected-(REF-PIN-PadN)`. A **named** single-node net is usually a real
  bug (a label going nowhere); `unconnected-*` is an intentional NC or a forgotten
  pin - the sidecar NC annotation tells you which.
- **A part is pass-through if it has exactly two connected pins**, rails included.
  Series resistors bridge two nets: trace both ends.
- **KiCad escapes text**: `{slash}` is `/`, `~{FLT}` is an overbar. Drawings decode
  both; netlist queries use the raw escaped name.
- **Label *shape* is cosmetic; only the *name* connects.**
- **Pin NAMES on stock diode symbols lie.** `Diode:BAV99` K/A/K contradicts its own
  graphics, `Diode:BAT54A` has none, and unidirectional `Diode:SMF*A` names its
  pins A1/A2 (pin 1 is the cathode). Use the generic symbol's name suffix or the
  datasheet, never the pin name. `check`'s PINOUT rule encodes this.
- **Stable vs nightly exports differ.** Stable `kicad-cli` (10.0.x) exports ONE root
  and names it `/`; nightly (10.99) exports every top-level sheet and names the
  root after the `.kicad_pro` (`/Root/`). Stable cannot open a file nightly saved.
  kmerge and kdrc pick the CLI per file; a netlist without a `.kicad_pro` top-level
  sheet gets a WARNING on load.
- **An open eeschema writes `_autosave-*.kicad_sch` files.** Every tool ignores them.

## Multi-top-level projects (KiCad 10.99)

- **The project manager tree lists only the .kicad_sch named after the project.**
  Other top-level sheets show up there only when KiCad's git integration attaches
  (`project_tree_pane.cpp` `showAllSchematics`). Membership is the `.kicad_pro`
  `schematic.top_level_sheets` list plus sheet symbols, not that tree.
- **Navigator order = `top_level_sheets` order** (loaded verbatim); **plot/PDF order
  = page numbers.** A top-level page number lives in its own file's
  `(sheet_instances (path "/" (page N)))`, a subsheet's in the parent's sheet symbol
  `(instances ... (page N))`. `ksheet lint` flags PAGEORDER/NAVORDER.
- **"Root" is KiCad's placeholder name** for a converted single-root project.
  Renaming a top-level sheet renames every local net under it (`/Root/Rails/5V_RAW`)
  and any netclass pattern that uses the path.
- **Stable 10.0 cannot open 10.99 files**, and a double-click may launch stable.
  `kdrc.py FILE doctor` shows which app opens each type.

## Board

- **Mid-placement, most of the BOM is parked in a pile beside the board.** Every
  kpcb check ignores anything whose centre is outside the outline, or the pile would
  drown the findings. `placed 135 of 439` in a header is progress, not an error. A
  part "not found" by `where` may simply not exist on the board yet.
- **`.kicad_pcb` y grows downward** and rotation is counter-clockwise on screen, so
  a footprint's child geometry transforms as `x + lx*cos - ...`, not the textbook
  rotation. `where` already prints board coordinates; do not re-derive them from
  `(at ...)` by hand.
- **A `.kicad_pcb` pad carries its own net name and pin function**, so kpcb needs no
  `.net` export. That also means the board can be out of date with the schematic: if
  kpcb and knet disagree about a net, the board has not been re-synced. Run
  `kpcb.py FILE sync` before quoting any placement finding.
- **Ref designators move during layout.** Do not cache them across sessions.
- **Nightly writes placement as `(transform (translate X Y) (rotate R) (scale 1 1))`**,
  not `(at X Y R)`. Pad `(at)` is unchanged and its angle is still ABSOLUTE. A
  reader that only knows `(at)` parks every footprint at 0,0.
- **Teardrops are zones** (`(attr (teardrop ...))`). Leave them out of any pour sum.
- **The zone fill on disk can be stale** (teardrops or tracks moved after the last
  fill). kicad-cli's DRC with `--refill-zones` hides that; `export gerbers` does
  not refill. `kdrc.py` reports it as DRC:STALE_FILL.

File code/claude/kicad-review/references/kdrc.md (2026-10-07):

# kdrc.py - real DRC + ERC via kicad-cli

The authoritative rules check. `kpcb.py check` and `knet.py check` are heuristics
on geometry and the netlist; `kdrc.py` runs KiCad's **own** Design Rules Check
(which applies `parsnip.kicad_dru` automatically) and Electrical Rules Check, and
folds the results into the same finding format as the other tools.

```bash
D=<skill>/scripts/kdrc.py
python3 $D parsnip.kicad_pcb            # DRC + ERC
python3 $D parsnip.kicad_pcb drc        # DRC only
python3 $D parsnip.kicad_pcb erc        # ERC only, every root schematic
python3 $D parsnip.kicad_pcb flags      # PWR_FLAG audit (~9 s)
python3 $D parsnip.kicad_pcb doctor     # install + project sanity, exit 2 on a WARN
```

`doctor` prints each kicad-cli's version, the project's newest file format, what
a double-click opens for .kicad_sch/.kicad_pcb/.kicad_pro (`xdg-mime`; WARN when a
stable app would get a 10.99 file, with the `xdg-mime default` fix) and whether
KiCad holds the project (`kcommon.kicad_running`: exact process names, `~*.lck`
locks, `_autosave-*`). Any tool that writes project files refuses while that list
is non-empty.

## What it does

- **The CLI is picked per file**: a board/sheet saved by 10.99 nightly gets
  `kicad-cli-nightly` (stable `kicad-cli` fails "Failed to load" on it), else
  `kicad-cli`; `$KICAD_CLI` overrides.
- **DRC** runs on the board with `--refill-zones` so results reflect current
  pours. It never passes `--save-board`: the refill is in memory, the on-disk
  `.kicad_pcb` is not modified.
- **Stale-fill check**: a second DRC pass runs on the fill AS SAVED, which is what
  `export gerbers` writes. Any violation only that pass finds is reported as
  `DRC:STALE_FILL` (ERROR if the underlying one is) with a `!! SAVED ZONE FILL IS
  STALE` banner: refill (B) and save before exporting. Found on parsnip 2026-09-22:
  two teardrop-vs-track clearance violations that exist only in the saved fill.
  `--no-stale-check` skips the pass (~5 s).
- **ERC** runs per **root**: the `.kicad_pro`'s `top_level_sheets` (primary first),
  else every `*.kicad_sch` that no other schematic pulls in as a sub-sheet. A root
  already covered by an earlier report is skipped. kicad-cli-nightly's ERC of the
  primary root covers every top-level sheet (parsnip: all 7 sheets in one report,
  header says `one report covers every top-level sheet`); stable kicad-cli covers
  only the root it is given.
- `DRC:SHORTING_ITEMS` and a `DRC:CLEARANCE` at actual 0.0 mm are never suppressed.
  Clearance/width messages lead with the number: `actual 0.1 < 0.127 mm (rule)`.
- Output: findings grouped by rule, capped per rule with a `+N more` tail,
  suppressible via `kdrc.json`, exit 0/2/3 like `kpcb`.

## `flags` - which PWR_FLAGs ERC actually needs

The netlist drops `#FLG` symbols, so knet cannot say where a flag sits. `flags`
copies the sheets to a temp dir with every PWR_FLAG made an ordinary part with a
passive pin (`#FLG` -> `FLG`), kmerges that copy to read each flag's net, and runs
whole-project ERC on the original and on the copy. A `power_pin_not_driven` only
the copy has marks a net that needs its flag:

- `LOAD-BEARING` - that net goes undriven without it (names the pin, usually a `#PWR`).
- `DUPLICATE` - a second flag on a net that needs one.
- `REDUNDANT` - ERC passes without it (names a `power_out` driver if the net has one),
  or it is connected to nothing.

Parsnip 2026-09-24: 13 flags, all load-bearing. Sheets must sit in the project
dir (a sub-sheet in a subfolder is not copied). `--json` for rows.

## The one caveat that matters

**Per-root (stable) ERC cannot see cross-root nets.** A pin powered or driven
through a global label whose driver is on another root (`I2C_HOST_*`, `USB D+/-`,
the shared rails) reads as `power_pin_not_driven` or `pin_to_pin` there. Those are
multi-root false positives. When the header does NOT say one report covers every
top-level sheet, confirm each against the merged netlist before believing it:

```bash
python3 <skill>/scripts/knet.py parsnip-merged.net around REF
```

DRC has no such blind spot - it is one board file.

## Demoted rules

The header lists what the `.kicad_pro` demoted, since kicad-cli leaves an
`ignore` rule out of its report entirely: `DRC demoted in parsnip.kicad_pro:
IGNORED pth_inside_courtyard, silk_over_copper, silk_overlap; warning-only fab
limits connection_width, copper_sliver, holes_co_located, starved_thermal`, and the
same for ERC. "Fab limits" are the manufacturability rules (clearance, drill,
annular ring, courtyard, hole-to-hole...) where a warning still means a board the
fab may reject. `--all` checks them at full severity.

## Flags

| flag | effect |
| --- | --- |
| `--max N` | cap lines per rule (default 25, or `max` in kdrc.json) |
| `--only R1,R2` / `--skip R` | keep or drop rules by name (e.g. `DRC:CLEARANCE`) |
| `--unconnected` | include the DRC `unconnected_items` (unrouted nets; hidden by default because mid-layout there are hundreds) |
| `--parity` | add DRC schematic-parity. Noisy: it uses the single project root, so it will flag all of /Charger/ and /USB Interface/. |
| `--all` | pass `--severity-all` to kicad-cli: every rule at full severity. kicad-cli HONOURS the `.kicad_pro` severities (an `ignore` rule is absent from its report), so without this a demoted rule is silent; the header names them. |
| `--no-suppress` | ignore kdrc.json |
| `--rules` | print the rule legend |
| `--json` | machine-readable findings |
| `--selftest` | run the offline suppression-logic self-test and exit (no board or kicad-cli needed) |
| `--no-stale-check` | skip the saved-fill DRC pass |

## kdrc.json (beside the board)

Same shape and precedence as `kpcb.json`. A bare `PREFIX:RULE` mutes the whole
rule; `PREFIX:RULE:TOKEN` mutes only findings whose refs or message contain
TOKEN. Rule names are the kicad-cli `type`, upper-cased, prefixed `DRC:`/`ERC:`.

```json
{"max": 25,
 "suppress": ["ERC:LIB_SYMBOL_MISMATCH", "ERC:FOUR_WAY_JUNCTION"]}
```

Pre-muted classes and why: `LIB_SYMBOL_MISMATCH` = the 16 deliberately edited
symbols (CLAUDE.md); `FOUR_WAY_JUNCTION` = drawing style. `SINGLE_GLOBAL_LABEL` /
`ISOLATED_PIN_LABEL` were muted while ERC ran per root (labels joining across roots
looked single-use); removed 2026-09-22 because the whole-project nightly report has
zero of them, so a new one is a real dangling label. Re-add only if you go back to
per-root stable ERC. `pin_to_pin`, `power_pin_not_driven` and
`footprint_filter` are left visible on purpose - triage them, then add the
confirmed-benign ones here.

A `DRC:CLEARANCE` finding at an actual **0.0 mm** (copper touching, a real
short) is never suppressed no matter what matches it here - it always shows,
tagged `0.0mm ACTUAL!` at the front of the line so 70-char truncation can't
hide the number. If a suppress rule would otherwise have caught it, the run
prints how many were forced visible this way.

## Notes

- ERC item positions are sheet-local coordinates, not board mm; the ref is the
  locator. DRC item positions are board mm and are kept in the message.
- kdrc shells `kicad-cli` / `kicad-cli-nightly` (KiCad 8-10.99). If it is not on
  PATH, kdrc exits 3.
- Mid-layout, DRC `unconnected_items` (unrouted) dominate. Route first, then care
  about them; until then `--unconnected` is opt-in.

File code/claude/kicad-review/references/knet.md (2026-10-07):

# knet.py - netlist connectivity, values, ERC, BOM

`knet.py FILE <cmd>` - file first, then subcommand.

| command | use |
| --- | --- |
| `summary` | comps, sheets, rails, DNP list, largest nets. Run first on an unfamiliar board. |
| `around REF...` | **highest value per call.** Pins, types, nets, position, every part one hop away. Use instead of `comp` + several `pin` calls. |
| `check` | 17 rule-based findings, grouped ERROR/WARN/INFO. Exit 2 if any ERROR. Three or more findings sharing a message fold into one line, `tail [N]: refs` - `[49]` means 49 separate findings, not one. |
| `check --since old.net` | only findings NEW vs an older export, plus a fixed/unchanged tally. |
| `draw REF\|NET [-d N] [-o x.svg] [--spec]` | KiCad-style schematic from the netlist; `--spec` gives the editable ksch source. The focal part keeps its real pin sides and order (from the sheet's lib symbol), GND/rail pins get their glyph where they sit (`gnd PIN -BATT` for a non-GND return), a big or global net ends in a `glabel`, and a global net's other ICs are named on a note line of their own above the net name (`+ U1 U5`), not drawn as stubs. A part already drawn is a stub on its row ending in `to R1.2
(drawn above)`, and a net drawn twice (a pin back on a net an earlier branch drew) is
one such row naming every part, not a row each. A left-side net note ends at its
pin, so a long name never runs into the IC's pin number. Dual diodes (BAT54S/A/C, BAV99/70, BAW56) and `Device:R_Shunt` draw as ksch's `d2s/d2a/d2c`/`rsense`, over as many rows as their side pins and labels need; every part is oriented by where ksch puts its pins (a `Device:D` is 1=K, so pin 1 is not the symbol's start). |
| `notes` | schematic text notes and text boxes by sheet, each with its font size (`SMALL` under 1.27 mm, totals per sheet) - designer intent that exists nowhere in the netlist. |
| `rails` | each power net: what feeds it (from `powertree`), total decoupling, loads. Power nets = name-derived rails + power netclasses (`PWR_HIGH`) + nets a `power_out` pin drives (switch nodes excluded); `? V` when no name or knet.json gives a voltage. |
| `i2c` | each bus (SDA net + what 0 R links and closed jumpers join, paired with its SCL): pull-ups and their rail, the controller (an MCU GPIO or an `I2Cc` pin), each target's 7-bit address resolved from its strap pins (GND / rail / R to X / divider ratio), connectors. Two targets on one address = ERROR, exit 2. Built-in table: BQ25798, MAX17320, QMC6309, TCAL9539, LSM6DSV16X, M24512, TPS25751 (ADCIN1/2 per its tables 8-2/8-6); others via knet.json `"i2c": {"PART": {"base": "0x48", "straps": ["A0", "A1"]}}` or `{"addr": ["0x42"]}`. |
| `powertree` | sources (top of each cell stack, then connector pins named VBUS/SOLAR/VIN/BAT) -> links (L, FB, F, R <= 10 R, closed jumpers), FET channels and regulators -> rails -> loads, as an indented tree. Each buck's Vout from its FB divider, an eFuse ILIM from a table (knet.json `vref`/`ilim`); a second way in prints as `also fed from`. The input a power-tree page needs. |
| `divider REF.PIN\|NET` | resistor-divider trip voltage from netlist resistor values, worst case from tolerance if stated. See below. |
| `diff old.net` | what changed vs an earlier export (rename-safe: compares neighbour sets). |
| `comp REF...` | pin table with net, node count, supply rail. |
| `net PATTERN` | exact name, then sheet-local name, then regex. |
| `pin U2.9` | net at a pin plus everything else on it. |
| `find PATTERN` | searches refs, values, footprints, properties, pin functions, net names. |
| `walk REF[.PIN] -d N` | expand outward through 2-pin passives. |
| `path A B` | shortest electrical path between two parts. |
| `bom [--sheet PATH]` | grouped, DNP separated, flags parts with no LCSC number. `--sheet /Root/Rails/` scopes to one hierarchical sheet and everything nested under it. |
| `unconnected` | floating pins, `[NC flag]` vs `[NO NC flag]` with the sidecar, plus single-node nets. |
| `sheets` | components per hierarchical sheet. |
| `revpol [--stack BT1,BT2 \| --pair P,N --volts V]` | reverse-polarity what-if. See below. |

**A stale netlist regenerates itself.** When a `.kicad_sch` beside the `.net` was
saved after it (KiCad `_autosave-*` ignored), every loader (knet, `kpcb sync`,
ksheet, part.py) re-runs `kmerge.py` first (~3 s, then quiet until the next save)
and says so on stderr. `KREVIEW_NO_REGEN=1` opts out; the selftest sets it. If the
regeneration fails, or is off, a `WARNING:` names the lag and the exact `kmerge.py`
command, as it does when the `.kicad_pro` lists a top-level sheet the netlist lacks
(a single-root export).

## Reading `around`

The header names the symbol (`sym Device:D_Dual_Series_ACK`): a generic
variant symbol carrying a specific part number is where pinout bugs hide.
One line per pin, then its peers indented under it. An `unconnected-*` pin reads
`NC (flagged)` when the schematic has a no_connect marker on it (directly, or at
the end of a wire stub from the pin), else `floating  <-- no NC flag`. The pin-type column is omitted
when the symbol types every pin `unspecified` (easyeda2kicad does), so a missing
type means unknown, never `passive`. A net already shown on an earlier pin of the
same part prints bare, or `(peers listed at pin N)` - that is two pins on one net,
not a different net.

## `divider`

`REF.PIN` accepts the pin's declared NAME (`U5.OVLO`, or the raw KiCad-escaped
`U14.EN{slash}UVLO`) as well as its number. Handles a plain 2-resistor divider
automatically. For TI's 3-resistor UVLO/OVLO string
(`IN->R1->EN/UVLO->R2->OVLO->R3->GND`, every TPS2594x/hot-swap part) it auto-detects
the shape and reports VIN_UV/VIN_OV once given `--vth <threshold from the
datasheet>`; add `--vth-tol <%>`, since the IC's own threshold accuracy usually
dominates the resistor tolerance. Use it for any FB/OVLO/UVLO/ADC-sense divider
instead of tracing it by hand across several `pin`/`net` calls.

Legs to the same top net combine in parallel, and a top net with no known voltage
still gives the tap as a fraction of it (`58.94% of /Charger/REGN`; `--rail
REGN=5` for volts). Thermistors (`TH*`/`RT*`/`NTC*` or a Thermistor symbol) are
legs at their 25 C value, flagged as such, and when Value/Description carries a B
constant (`B25/50 3380K`) it prints the tap from -20 to 60 C - a TS pin reads
straight against the charger's TS thresholds (`divider U8.TS`: 73.6% of REGN at
0 C).

## Flags

`--through R,L,FB,F,FL,JP` (pass-through prefixes; add `C`/`D` to trace through caps
or diodes), `--fanout N` (nets above N nodes are rails, default 8), `--as-drawn`
(traverse DNP parts too; **default treats DNP as open circuits**),
`--rail '+5V=5,VCC_RF=3.3'`, `--peer-max N`, `-o FILE`, `--spec`, `--theme`,
`--json`, `--only`/`--skip RULE,RULE`, `--rules` for the rule legend,
`--no-suppress` (for `check`), `--sheet PATH` (for `bom`), `--vth V` /
`--vth-tol PCT` (for a 3-resistor `divider`).

`walk` caps a rail's load list at 10 with a `+N more (rail net, N total)` tail once
a net is a named rail or above `--fanout`. The count in the tail stays accurate even
when not every load is printed.

## Project config

`knet.json` next to the netlist persists board defaults:

```json
{"rails": {"+BATT": 8.4}, "fanout": 8, "suppress": ["RFSTUB:GPS_ANT", "OCNOPULL:U9"],
 "vref": {"LM61460": 1.0},
 "ilim": {"TPS25947": {"549": "5.400/6.068/6.600 A", "6.65k": "0.425/0.500/0.575 A"}}}
```

`vref` (feedback reference, V) and `ilim` (resistor value -> the datasheet's
min/typ/max row) are keyed by a substring of the part value, read from the
datasheet, never guessed; `powertree` prints `Vout = 3.310 x VFB` without them.

Precedence: defaults < knet.json < CLI.

`suppress` mutes `check` findings already confirmed not to be bugs, so they stop
costing tokens on every future review instead of restating "don't re-flag this"
each session. An entry is `"RULE"` (mute the whole rule) or `"RULE:TOKEN"` (mute
only findings naming that ref or net - a confirmed false positive on one net must
not hide a real one elsewhere). `check` reports how many it muted; verify the count
looks right, and use `--no-suppress` after a big rewire to see everything again.

## check rules

`FLOATPWR NCDRIVEN SOLO CONTEND DOMAIN DECOUPLE OCNOPULL I2CPULL PASSONLY RFSTUB
DNPPATH CAPRATING NOVALUE GNDISLAND CLAMPRATING PARPIN PINOUT FPPAD`. `--rules` for one-line
descriptions. With the sidecar, FLOATPWR downgrades to WARN when the schematic
carries an explicit NC flag.

- **`DOMAIN`** is the useful one: it infers each net's pulled-to voltage from series
  resistors and ferrites to named rails and compares against each IC's supply rail,
  catching pull-ups to 5 V on 3.3 V logic.
- **`SOLO`** (a named net with one node) names the other half when the same short
  name lives on another sheet (`/Root/CS_DISPLAY` alone, `/Root/Connectors/CS_DISPLAY`
  with J5.4 ...): a local label on a parent and on its subsheet never connect; fix with
  a hierarchical label + sheet pin, or a global label.
- **`PARPIN`** catches a paralleled pad left floating: two or more pins on the same
  part sharing the same declared pin NAME (e.g. multiple BAT pins on a charger IC)
  where one is wired to a real net and a sibling is not. Matches on pin name rather
  than pin type, so it still fires when the symbol types the dangling pin `passive`
  rather than `power_in` - the case that let a real floating BAT pin slip past
  FLOATPWR. A dangling pin whose number the footprint has NO pad for is fused into
  a sibling's pad (TPS25751 `REF0038A`: pad 20 spans pins 20-22) and reads INFO
  `fused into pad N - the copper is right`, not ERROR.
- **`FPPAD`** diffs each part's symbol pin numbers against its footprint's pad
  numbers, read from the `.kicad_mod` the footprint field names (resolved through
  the project `fp-lib-table`, then the user's global one, with `${VARS}` from the
  environment and `kicad_common.json`). A pad with no pin imports with NO net
  (WARN: an exposed pad or FET tab left floating, e.g. a DFN EEPROM's EP on a
  generic 8-pin symbol); a wired pin with no pad loses that connection on the board
  (ERROR). `MP` mounting pads are exempt. Works before the part is on the board,
  which KiCad's own parity check cannot. No reachable library = one INFO line.
- **`RFSTUB`** counts the parts in series on an RF-netclass net. Not counted: DNP
  parts, a 2-pin R/C/L/D/FB whose other end is GND (a shunt at the node: pad shunt,
  ESD diode, matching element), and an RF choke (an L whose far end is bypassed by
  a capacitor, or only feeds resistors >= 1k: a bias tee, an antenna-detect line).
  Net names (`ANT`, `_RF`) count as RF only in a project with no RF netclass.
- **Rails** come from names: a whole-name voltage (`+3V3`, `12V`), `KNOWN_RAILS`,
  one voltage token inside a longer name (`PD_LDO_3V3`, `3V3_GNSS`, `5V_RAW`) unless
  another token is a signal word (`5V_EN`, `PG_3V3`), and `--rail`/knet.json.
  OCNOPULL also accepts an LED + resistor to a rail (a status pin sinking an LED);
  I2CPULL reads a dual I2C/SPI name (`SCL/SPI_CLK`) with no pull-up as INFO.
- **`CLAMPRATING`** parses a TVS's standoff voltage from a recognised part-number
  series (SMF/SMAJ/SMBJ/SMCJ/SM6T/SM8S/P6KE/1.5KE/P4KE) and flags it against the
  named rail it sits on between rail and GND - narrow by design (only those series,
  no margin math beyond "not below") to avoid a confidently wrong number. The rail
  figure is name-derived or `--rail`/knet.json, not the regulator's true analog
  output, so a finding here can understate the real gap; it will not overstate it.
- **`PINOUT`** compares a 3-pin SOT-23/323 part's real pinout (a small curated
  table in knet.py: BAV99/BAV199/BAT54S series `AKC`, BAT54A `KKA`, BAT54C `AAK`,
  2N7002/SI2308/AO3400/AO3401/BSS138/BSS84 `GSD`) against the symbol's pin order,
  read from a generic symbol's name suffix (`D_Dual_Series_ACK`, `Q_NMOS_GSD`) or
  from G/S/D pin names. Stock DIODE pin names are never used: `Diode:BAV99`'s hidden
  names K/A/K contradict its graphics and `Diode:BAT54A` has none. Found D6 (BAV199
  on `D_Dual_Series_ACK`, should be `_AKC`). Extend the table for a new part; do not
  loosen the match. Power FETs: a generic `Q_[NP]MOS_xyz` symbol on a footprint that
  numbers its pads by function (KiCad's VSONP/TDSON/VSON NexFET family: pad 1 = 3
  copper pieces, pins 1-3, S; pad 2 = the gate; pad 3 = >= 4 pieces with the EP, D,
  read from the `.kicad_mod`) must read `SGD`; anything else is an ERROR naming the
  right symbol. FPPAD cannot see it because the pad numbers match. Found Q7/Q8
  (CSD18512Q5B on `Q_NMOS_DGS`, D and S swapped).
- **`GNDISLAND`** catches a different shape of bug than FLOATPWR: pins named like
  ground (GND, AGND, VSS, ...) that ARE wired to each other but never reach the
  board's real GND net - a merge that silently didn't happen. `is_gnd()` recognises
  these by pin name even on an auto-generated net (`Net-(U7-GND-Pad1)`), so DECOUPLE
  no longer misfires on them as "missing a bypass cap".

**These are heuristics. Confirm against the datasheet before calling anything a
bug.** Worked example: `U7.5 (FB)` on a TPS61033 sat on the same net as `VIN` -
looks like a broken feedback loop, but the datasheet says that is the documented
fixed-5.0 V configuration. The correct move was `kdoc.py grep 'FB' -d tps` first.

## `revpol` - what a backwards cell or pack does

Cells come from `--stack` (default: every `BT*`, chained by their `+`/`-` nets) or a
`--pair P,N --volts V`. Cases: whole pack reversed, then each single cell reversed,
each compared against normal operation so only CHANGES print:

- **conducting between two cell-driven nodes** - a loop only the cells limit, with
  `fuse in loop: F5` or `NO FUSE in this loop`;
- **conducting through a series resistor** - limited, names the R;
- **conducting into another node** - a junction now feeding an undriven node;
- **IC pins pushed outside their normal range** - volts vs that IC's own GND pin,
  the series R back to the cell, the current that R lets into the pin's ESD diode
  (`~350mA into its ESD diode` - injection limits are ~10 mA), a pin driven above
  its own supply pin (back-powering it), and the `kdoc.py grep` for its abs-max;
- **FET channels vs normal** - a FET whose gate the cells drive past 2 V conducts
  (source-drain joined), re-solved until stable: a low-side reverse-polarity NMOS
  (Q16) is ON in normal operation and OFF reversed;
- **ICs that lose their ground** - isolated (no two pins cell-driven > 0.7 V apart),
  or ground floating while pins still sit on cell taps at different voltages (the
  IC's internal/ESD network conducts between them: the BMS on its cell-sense pins).

A normal-operation section first lists junctions ALREADY conducting between two
driven nodes (LEDs excluded) - how a wrong-pinout diode shows up (D6).

Model: cells ideal; F/FB/L, R <= 1 ohm (incl. 4-pin Kelvin shunts), `Bridged`
solder jumpers and ON FET channels are wires; other resistors pass their node's
voltage one hop (a sense line at open circuit); every forward junction is 0.7 V.
Diode orientation follows the REAL part (PINOUT table by pad number), then the
symbol suffix, then A/K pin names, then KiCad's pad-1-is-cathode convention for a
2-pin diode (true for `Diode:SMF*A` despite its pin NAMES being A1/A2). A zener
(voltage from `BZX..-C15` / `5V1`) or unidirectional TVS (~1.1x the standoff in its
part number) also conducts backwards at breakdown; a bidirectional TVS (`CA`
suffix, `bidirectional` in its description, or A1/A2 pins without `unidirectional`)
both ways at breakdown, or is listed not-modelled when the part number gives no
standoff. An ESD array with a GND pin gets GND->I/O diodes (and I/O->supply when it
has a supply pin); a BJT (NPN/PNP in its symbol or description) both base
junctions; FET polarity comes from any text field (`N-CH`, `PMOS`, symbol name)
before the small value tables. Only forward junctions whose anode is not ground
DRIVE an undriven node: breakdown paths and GND-to-signal clamps conduct but power
nothing. ICs are open circuits whose ESD diodes only clamp. A what-if to aim
datasheet checks, not a simulation.

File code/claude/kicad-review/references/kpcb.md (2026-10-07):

# kpcb.py - placement review

Placement review from the `.kicad_pcb` alone. No DRC (that is `kdrc.py`) - the
placement checks work the moment a footprint is dropped; `ampacity`, `rf` and
`zones` read the routed copper once it exists, and `height` reads the 3D models.
Reads KiCad 10.0 `(at X Y R)` and 10.99 nightly `(transform (translate) (rotate))`
footprint placement (validated against `pcb export pos` 443/443 and IPC-2581 pad
centres 1329/1329).

Code map (to patch one command, open only its module): `kpcb.py` is the CLI plus
summary/where/map/sheet/unplaced/span/net/sync/review; the Board model, part
classification regexes and geometry are `kpcb_board.py`; `check` rules are
`kpcb_check.py`; `ic`, `zones`, `ampacity`, `viapad`, `rf`, `height` are
`kpcb_<ic|zones|amp|viapad|rf|height>.py`. `kpcb_copper.py` is one net's copper as
a graph (pads, tracks split at tees, via barrels, fill fragments as conductors):
`net` counts its pieces and `ampacity --from/--to` solves current through it.

Every `(footprint` block is one Board entry. KiCad allows a repeated ref (logos are
all `REF**`): the second and later copies read `REF**~dup2`, `REF**~dup3`, ... A
padless footprint's side is where its art is, not its `(layer)` (a B.Cu logo can
carry F.SilkS art), so `summary`, `map` and `where` count it on the art's side.

| command | use |
| --- | --- |
| `summary` | outline size, stackup, zones, how much of each sheet is placed, biggest parts. Run first. |
| `check` | 10 rule-based findings, grouped ERROR/WARN/INFO. Exit 2 if any ERROR. |
| `where REF...` | **highest value per call.** Position, rotation, courtyard, Fab-only body (the housing a connector setback is measured from), edge distance, class, nets, and every neighbour within `-r`. Footprint `(scale)` is applied. `--origin grid\|aux` quotes KiCad's dialog coordinates. Use instead of eyeballing coordinates. |
| `where X,Y -r N` | same, around a bare coordinate - "is there room here". |
| `map [--side f\|b] [--cols N]` | ASCII occupancy map, one letter per schematic sheet. Shows the floorplan and the free space in ~50 lines. |
| `sheet [PATH]` | per-sheet placed/left counts, bounding box, spread, and parts that drifted from their block. |
| `unplaced` | what is still parked off the outline, ref-ranged by sheet, biggest first. |
| `ic REF` | **where the passives should go**, not just what is wrong. See below. `ic` alone lists the parts worth asking about. |
| `span` | nets ranked by how far apart their placed pads sit. The one routing-quality number that exists before routing does. |
| `sync [board.net]` | **run this first.** Board vs netlist: same parts, footprints, values, DNP flags and net on every pad. Finds a `.net` beside the board automatically. |
| `review [board.net]` | one call for a fresh session: sync, summary, check, longest nets, then the specific next calls worth making. |
| `ampacity [NET...]` | current a routed net can carry (IPC-2221): narrowest segment per layer, via bound, length -> R/Vdrop. With `--amps X` or a kpcb.json budget it warns TRACE-THIN / VIA-FEW / LONG-DROP. See below. |
| `ampacity --from U8.1 --to C5.2 --amps X` | **the real power path**: a nodal solve between two pads (tracks + via barrels resistive, pours ideal), so current splits by conductance; lists the hottest tracks/vias at their share. Use it on a plane net, or when the budget runs between known pads. |
| `zones` | pour coverage per layer from the last saved fill: area%, island count, edge margins. |
| `zones REF...` | does a net's fill actually cover THIS footprint's courtyard - point-sampled, not just the fill's bounding box - and which foreign tracks SLOT that plane under it. Closes "is GND continuous under U9" without a KiCad render. See below. |
| `zones --voids [--area 2]` | copper-free regions in the plane pour (removed islands) and, for each, a via spot that clears everything and lands in the plane on another layer. See below. |
| `vias` | every via by size / drill / layer span (through or blind), the top nets on each, and the worst drill aspect ratio against the stackup thickness. |
| `viapad [--signal] [--min N]` | every component with a via centred inside one of its SMD pads (via-in-pad), each pad tagged GND/PWR/SIG. See below. |
| `where REF.PAD ...` | a pad's absolute centre, size, layer, net and nearest same-net pads. Two specs (pads, refs or x,y) also print the distance between them. |
| `net NET` | every pad on a net with absolute xy, copper per layer (segments, length, width range), vias, zones, extent, and whether the copper is **one piece** (else the pads in each cut-off piece) plus padless islands. Accepts the short name (`LORA_ANT`). |
| `rf [NET...]` | 50-ohm trace review. No net = every net whose netclass names RF/50. See below. |
| `height [REF...]` | 3D-model height of each part and the board's Z stack. Shells out to KiCad's GLB export (~15 s, then cached until the board, a `${KIPRJMOD}` model or kicad-cli changes). See below. |
| `movecheck REF X Y [ROT]` | what moving REF there would **newly** break: foreign pads/tracks/vias inside the clearance, copper to the edge, a same-side courtyard overlap. `REF --scan x=X y=A..B [--step 0.05]` slides it and prints the clear stretches; `via X,Y NX,NY` moves one via and says whether tracks are tied to it. Read-only. See below. |
| `tidy` | near-miss alignment, each fix pre-checked with `movecheck`: a row/column with one part 0.005-0.15 mm off, a row of >= 3 with an uneven pitch, mounting-hole insets that nearly agree, rotations off a multiple of 90, a small part a little off a big same-side part's long centre line (a thermistor under a cell holder). Prints `REF now -> new`; writes nothing. See below. |
| `freebox SIDE W H` | where a W x H mm silk box (a logo, a label) fits on side `f`/`b`: clear of that side's courtyards, every through-hole pad and that side's silk (logos, board art, refdes and other footprint text), >= 1 mm inside the edge. Best centre per free region, by margin. See below. |
| `silk` | every padless graphic footprint (logo, pasted art): the layers its art is really on (per item, not the footprint's `(layer)`), scaled extent, rotation, the same-side part body hiding it (HIDDEN >= 50% of its box), and the pads its art crosses. See below. |
| `view REF... [-r 5] [--layers L,L] [-o x.png]` | PNG of the board around parts (their courtyards + `-r`), an `X,Y`, or `--box X0,Y0,X1,Y1`, on the part's side layers (Cu, SilkS, Fab, CrtYd + Edge.Cuts) unless `--layers`. Use it to check by eye what a number says (a void, a logo under a module, a setback). See below. |

## Flags

`-r N` (neighbour radius, 5), `--max N` (cap per rule / per neighbour list, 12),
`--cols N` / `--side f|b` (for `map`), `--only`/`--skip RULE,RULE`, `--rules`,
`--json`, `--no-suppress`, and one threshold per rule: `--edge 0.5` `--hole 1.5`
`--conn 10` `--rf 8` `--therm 8` `--bypass 3` `--clear 0` `--fb 4` `--gap 0.25`
`--tol 1` `--span 0` (all mm; `--span 0` means half the board diagonal), plus
`--fanout 8`. For `ic`: `--anchor REF`, `--cin REF,REF`, `--cout REF,REF`,
`--ncin 3`, `--ncout 3`, `--assoc 6`. For `ampacity`: `--amps X` (required
current on the named net), `--net NAME` (repeatable), `--dt 10` (allowed temp rise, C), `--plating 20` (via barrel copper,
um), `--vdrop 0.25` (V-drop flag threshold), `--from REF.PIN --to REF.PIN` (path
solve). For `zones`: `--voids`, `--area 2` (smallest void core, mm2), `--net=NAME`
(the plane net, default the biggest pour). For `viapad`: `--signal`, `--min N`.
For `rf`: `--freq MHz`, `--fence 1.5` (mm from the trace edge that counts as fence).
For `where`: `--origin page|grid|aux` reads x,y arguments and prints coordinates
relative to the board's grid origin or aux (drill/place) origin, which is what KiCad's
Properties dialog shows when Display origin is set that way (Y still grows down;
an inverted-Y display is not modelled). `summary` prints both origins.

## Project config

`kpcb.json` next to the board, same shape and precedence as `knet.json`:

```json
{"edge": 0.3, "bypass": 4.0, "suppress": ["OVERLAP:BT1", "UNPLACED"],
 "current": {"VSYS": 2.7, "+5V": 3.0, "-BATT": 2.7},
 "height": {"BT1": 23.1, "BT2": 23.1}}
```

`height{}` is a measured part height (mm above its board face) that replaces the
3D model's figure in `height` - for a model known to be incomplete.

`current` is the per-net amp budget `ampacity` checks against when no `--amps`
is given (and in a bare `ampacity` scan). Fill it once with the real worst-case
current each power net carries; signal nets can be left out.

Use `suppress` for placements already confirmed deliberate (thermistors under a
cell, a module antenna overhanging the edge) so they stop costing tokens on every
review.

## `sync` - is the board even the circuit you drew

`kpcb.py board.kicad_pcb sync` (the `.net` beside the board is found on its own).
**Nothing else here means anything if this fails.** A board that was never
re-synced after a schematic change carries pad net names that look perfectly valid,
so neither the board file nor any check on it can tell you it is stale - only the
netlist can. Rules: `SYNCPART SYNCFP SYNCVAL SYNCDNP SYNCNET SYNCART`.

Clean output is two lines (`IN SYNC`), so it is cheap to run every time. A `SYNCNET`
error means re-run KiCad's *Update PCB from Schematic* before reading any other
finding. `SYNCVAL`/`SYNCDNP` alone are annotation drift: worth fixing, but the
connectivity is still right and placement findings still hold.

A footprint on the board only that has no pads and no sheet path (a logo, pasted
silk art, `REF**`) is `INFO SYNCART`, not a missing part: it never came from the
schematic, so it cannot make the board stale and the output stays `IN SYNC`.

`unconnected-*` pseudo-nets get a `_1` suffix on the board and not in the netlist;
that is normalised away rather than reported as 439 differences.

## `review` - the whole placement picture in one call

Runs sync, `summary`, `check` and the top of `span`, then prints a **next** block
naming the exact calls worth making on *this* board - `ic` on the unplaced
regulators, `where` on whichever refs appear in the most ERROR findings, `map` if
much is still unplaced. That last block is the point: it is the reasoning a session
would otherwise have to do itself from a summary it has not read yet. If the board
is out of sync it says STOP and explains that everything below is about a different
circuit.

## `ampacity` - can the copper carry the current

Works off the ROUTED tracks and vias, so it means nothing before routing and it
re-reads on every save. Three ways to call it:

- `ampacity VSYS --amps 2.7` - judge one net against a required current.
- `ampacity VSYS` - same, current taken from kpcb.json `current{}` if set there.
- `ampacity` - scan: verdict every budgeted net, then list the heaviest routed
  nets (most copper length) with their capacity so the power nets surface without
  a budget file.

A net name that starts with `-` works as typed: `ampacity -BATT --amps 2.7` and
`--net -BATT` (every tool reads a dash + uppercase token that is not one of its
options as a value; kcommon `parse_args`).

To make a finding fixable it prints, per net: a **`find it:`** line listing the
components on the net (ICs/connectors first) - click any in KiCad to highlight the
whole net - and, for the bottleneck, the **nearest pin** (`near U5.23 (2.8 mm
away)`, Ctrl+F the ref) plus the raw `cursor to X,Y` (KiCad shows the cursor in mm,
bottom-right). Highlight the net, go to that ref, scan for the skinny segment. It
also prints the **required width**; when that is impractically large (7-8 mm) the
bottleneck is a thin inner layer (0.0152 mm / ~0.43 oz here) and the real fix is to
route the net on an outer layer or a plane, not to draw an 8 mm inner trace.

**Pours are conductors, not a verdict.** A net with fill reads like any other: the
pours are ideal nodes in the copper graph, so a track a pour parallels is never a
bridge, and a `pours:` line lists each layer's fill area and fragment count with a
reminder that a pour's own neck is not measured. On a plane net (GND) every pad's
stub into the plane is a pendant bridge, so the bottleneck names the thinnest pad
stub, which only matters if that pad carries the budget: `--from PAD --to PAD`
answers the real source-to-load path. The R/Vdrop line still sums tracks only.
`--json` carries the `pour` block.

### How it reads the copper (the important part)

It does **not** just take the smallest `(width)` on the net. It builds the net's
**copper graph** with `kpcb_copper.Copper`, the same one `net` and `--from/--to`
use: a node is one piece of metal (a pad, a pour fragment, track ends joined at a
tee, a crossing, a via on a track's body), an edge is a track piece between those
joins or a via barrel half. The **bottleneck** is then the narrowest **bridge**
track piece - one whose removal would split the net, so all the current must
cross it. A segment sitting in a parallel loop is *not* a bridge, so a trace that
splits and reconverges is no longer mis-read as one thin strand. Each segment is
rated with IPC-2221 `I = k*dT^0.44*A^0.725` (k=0.048 outer copper, 0.024 inner).
Inner layers here are 0.0152 mm (~0.43 oz), so a 1 mm inner trace rates below a
0.2 mm outer one. Vias are a plated barrel (`width = pi*drill`, `--plating` thick),
summed as a parallel bound. Length feeds resistance and voltage drop. The output
prints the graph state (`N pad(s)`, island count) and, when they differ, both the
mandatory-bridge ampacity and the `narrowest single seg` value. `N pieces, not one
conductor` is a real split (the same pieces `net` lists), not a graph artefact.

A bridge whose only far-side pads are sense taps (a thermistor `TH*`, a test point
`TP*`, or a resistor >= 1k ohm - never a real power path) is never the bottleneck nor
the narrowest single seg; the graph line names them (`sense-tap legs skipped: TH1`).
When taps are the only bridges the net reads `meshed, no series bottleneck`.
A bridge with at most one part that can source or sink DC on one side (caps, test
points and taps don't count) and two or more on the other is a **pad stub**: it
carries only that part's current, so it is neither the bottleneck nor the narrowest
single seg. On a plane net every pad's stub is one, which used to name a 2-pin
connector's 0.2 mm stub as the GND bottleneck. A three-way tee makes every arm a
stub: without `--from/--to` the tool can't tell which part is the source.

Warnings (each fires only with a known current; exit 2 on TRACE-THIN or VIA-FEW):

- **TRACE-THIN** - narrowest-bridge ampacity below the required current. It names
  the bridge segment and the nearest pin. Widen it, or move it to an outer layer -
  when the bottleneck is an inner layer and the needed width exceeds 2 mm
  (impractical), the message also gives the width an outer layer would need instead.
- **VIA-FEW** - the net's vias can't carry the current even in parallel.
- **LONG-DROP** - series-bound voltage drop over `--vdrop` (0.25 V). Advisory.
- **PARALLEL-CHECK** (advisory) - a thinner segment exists but is paralleled, so
  it is not mandatory; fine only if its parallel group's widths sum to the current.
- **MESH-CHECK** (advisory) - the net is a full mesh with no single mandatory
  segment; confirm the parallel copper sums to the current. Not on a poured net
  (its loops close through the pour, which is not measured).
- **STUB-CHECK** (advisory) - pad stubs under the current, narrowest first, as
  `REF.PIN width amps` (narrowest per part). Only a part that sources or sinks the
  budget carries it: `--from` that pad `--to` the load to solve the real path.
- **PAD-NECK** (advisory) - the picked bottleneck is a short (< 2x its width), wide
  stub landing right on a pad. IPC-2221's long-trace formula overstates the risk
  here because the pad copper sinks heat locally; not a real limiter unless the
  copper stays that narrow past the pad.
- **SHORT-NECK** (advisory, not a failure) - IPC-2221 says the bottleneck is thin,
  but it is a short piece with both ends in big copper (a pad, a pour, or a
  junction with >= 3x its width of other track). A rod heated along its length
  with its ends held at ambient rises `dT = P*L/(8*k*A)`; when that is under
  `--dt` the long-trace fit is the wrong model. A TRACE-THIN on a sunk piece also
  prints this bound. (5V_RAW's 1.5 x 0.3 mm stub into U15.5 at 3 A: ~1.1 C.)

What it still can't see: a parallel group that individually passes but **sums
short** is left to you (PARALLEL-CHECK), a pour neck is ideal, and IPC-2221 internal
ampacity is conservative for a planed board (see the footer). `--from/--to`
answers the first and the last, below.

### `--from PAD --to PAD` - current along the real path

`ampacity --from Q16.1 --to R41.1 --amps 6` solves the copper between two pads of
one net as a resistor network (Jacobi-preconditioned CG, ~0.02 s): tracks and via
barrels are resistors (`rho*L/A`, barrel = two halves of the board thickness),
pads and zone fills are ideal nodes. The copper graph (`kpcb_copper.py`) joins
what KiCad joins: track ends on pads/vias, a track teeing into another's body, two
tracks crossing mid-span, a via or pad sitting on a track mid-span, overlapping
pads (fused leads), fills to
the pads/vias/tracks they touch and to other fills of the net on the same layer.
On parsnip it finds 0 split nets and 0 islands, matching KiCad's 0 unconnected / 0
isolated_copper. Output: R, Vdrop, P between the pads, the pours crossed, and the
hottest elements at THEIR share of the current (rise from IPC-2221, or the
end-sunk bound for a short piece between big copper, whichever is lower; vias
IPC-2221 barrel only). A sense tap (thermistor leg) carries nothing, so it can
never be named. Pours are ideal: a pour neck is invisible here, so check it in
KiCad. Exit 2 when an element exceeds `--dt`; not joined at all also exits 2.

## `zones REF...` - does the plane actually reach under this part

Teardrops are zones in KiCad (1410 of 1434 on parsnip); every pour figure here
and in `summary`/`ampacity` leaves them out, `summary` just counts them.

`zones` alone reports per-layer coverage for the WHOLE board (area%, islands,
edge margins) - useful for "is the pour fragmented", useless for "is GND solid
under this one RF part", since a dominant island and all-edges-reached can both
be true while the fill still has a hole right where it matters. `zones REF...`
answers that directly: an 11x11 grid of sample points inside the footprint's
courtyard, each tested against every net's fill that could plausibly reach
there (a bbox prefilter, then discarded if the net scores zero real hits - a
net's overall pour can be substantial elsewhere and still never actually touch
this courtyard, which the prefilter alone can't tell apart from touching).

Coverage is reported per (layer, net): **continuous** (100%), **has gaps**
(>=50% - normal, since every non-plane pad or via under the part carries its
own clearance moat, so this is not itself a finding), or **MOSTLY MISSING**
(<50%, or no net reaches the courtyard on that layer at all) - the last is the
one worth exit code 2 and a look, listing a few uncovered sample coordinates so
you know where to click. Only trust a MOSTLY MISSING verdict, or a large
contiguous run of misses inside a "has gaps" layer, as a real broken reference;
a handful of scattered misses next to signal pads is expected and not a defect.

**SLOT**: the samples can miss a thin cut that runs between grid columns, so for
each plane (GND/rail net) it also measures foreign-net tracks on that layer inside
the courtyard and prints `!! SLOT: +5V track(s) (1.80 mm) run 52.2 mm through the
GND plane under U12 (...)` for runs across >= half the courtyard's shorter side
(two per layer, then a count). The part's own nets on its own side are its fan-out,
not a slot. The coverage tag then reads `has gaps, and a SLOT cuts it`.

Edge-mount parts (SMA, USB-C) are judged on the ON-BOARD part of the courtyard only:
the grid covers the courtyard clipped to the outline, inset 0.5 mm on clipped sides
for the pour's edge pullback, and the header says what % hangs off. A net that is
neither GND-named nor a rail (a small signal pour) is listed without a verdict,
`local signal pour, not a reference plane`, and never fails the exit code.

## `zones --voids` - removed islands, and where one via rescues each

Rasterises every plane layer at 0.25 mm (layers where the plane net covers > 30%)
from the last saved fill, marks ALL copper (fills, tracks, pads, vias), and keeps
only board cells >= 0.5 mm from any copper and from the edge - a clearance moat
never reads as a void. Connected regions over `--area` mm2 are reported with their
extent; one mostly inside a no-pour keepout (U1's antenna) says `intended`.

For every other void it looks for a **rescue via** (the plane netclass's via,
0.6/0.3 here): a cell in the void where, on every layer, no foreign track, pad or
via is within via radius + clearance (netclass clearances raised by any
`.kicad_dru` rule naming the net pair with `A.NetName`/`B.NetName`, so the 0.4 mm
unfused-pack rule counts), no drill is within 0.25 mm hole-to-hole, no via keepout
covers it, and the plane net's fill is there on another layer. A spot clear of
foreign pours too is preferred; else it names the pours the via would punch (they
refill around it). No spot prints how many cells each constraint blocked.
Validated: on the board before 573c130 it proposes 113.72,155.13 and 108.97,150.38;
the two GND stitching vias placed by hand landed at 113.45,155.16 and 109.05,150.36.

## check rules

`OVERLAP EDGECLR EDGEREF HOLECLR CONNACC RFNOISE THERMAL BYPASS NETSPAN NOCRTYD UNPLACED`.
`--rules` for the legend.

- **`OVERLAP`** screens on courtyard bounding boxes, then confirms against the real
  CrtYd outlines (lines/arcs/rects/polys chained into rings): a cross- or L-shaped
  courtyard whose box overlaps but whose outline does not is dropped, as KiCad's
  DRC drops it (L4's 0603 neighbours clear by 0.02-0.06 mm). A part with no
  chainable CrtYd falls back to its box. `where`'s neighbour distances and OVERLAP
  flags use the same outline distance. Parts on opposite sides only collide where a
  drilled barrel actually lands in the other's area; a back-side battery holder
  sitting over front-side 0402s is not a finding.
- **`EDGECLR`** is an ERROR when the courtyard crosses the outline, a WARN when it
  is merely inside `--edge`. An edge-mount part (SMA, U.FL, USB-C, `EdgeMount` in
  the footprint name) crossing the edge downgrades to INFO - that is what it is for.
- **`EDGEREF`** reads the footprint's own idea of the edge. An edge-launch part (SMA,
  USB-C) whose footprint carries a Dwgs.User line plus a "PCB Edge" text: the line
  more than 0.05 mm off the outline is a WARN, with the move that puts it on the edge
  and where the nearest pad then lands vs the copper-to-edge clearance (the larger
  of `.kicad_pro` `min_copper_edge_clearance` and any `.kicad_dru` `edge_clearance`).
  A side-entry connector (`Horizontal` in the footprint name, MP pads, which sit on
  the mating side) within `--conn` of an edge is an INFO giving its Fab housing
  front's setback and how far it can come forward before a pad is inside that
  clearance; a WARN when a pad already is.
- **`HOLECLR`** keepout radius is the hole's own pad/drill radius plus `--hole`. It
  also catches a mounting hole placed outside the board entirely.
- **`CONNACC`** has two halves: a connector further than `--conn` from any edge, and
  a connector whose cable-exit corridor (its courtyard swept straight out to the
  nearest edge) is blocked by another part. The corridor is axis-aligned only - a
  diagonal exit is not modelled, and neither is component height.
- **`RFNOISE`** needs a switching node. Those are found by pin NAME (`SW`, `LX`,
  `PH`, ...) plus, as a fallback for a switcher whose pin is unnamed, the nets of a
  power inductor (>=1uH **and** >=6 mm2 of courtyard, which is what separates a buck
  inductor from a 470nH 0603 antenna match). Named power rails are excluded, or
  every load on +3V3 would look noisy.
- **`THERMAL`** pairs heat sources (power inductors, switching/charger/eFuse/LDO
  parts, RF PA modules >= 27 dBm such as the E22P) against heat-sensitive ones
  (crystals, oscillators, battery cells, the GPS module). A thermistor (TH/NTC/RT)
  near a heat source is reported separately as a **measurement bias**: it reads
  that part instead of what it is wired to watch (e.g. a charger TS thermistor
  meant for the cells). Suppress the intentional ones in kpcb.json
  (`"THERMAL:TH5"`). Cross-side pairs are reported and labelled: heat couples
  through the board.
- **`BYPASS`** measures each supply pin to the nearest **placed** cap on the same
  net. It stays quiet when no cap on that net is placed yet. Matched on pin NAME,
  never on `pintype`: easyeda2kicad types nearly every pin `passive`, so a
  type-based test would silently check nothing - the same trap `PARPIN` documents
  in knet.
- **`NETSPAN`** is the only rule that looks at wiring: a **fully placed** non-rail
  net whose pads sit further apart than `--span` (default half the board diagonal).
  Fully placed only, because a net still waiting on parts will move. Rails are
  excluded by node count **and** by name. `span` is the detailed view of the same
  data, ranked and capped.
- **`UNPLACED`** prints **one folded line per sheet**, never one per part.
- Two things that used to fire on a half-placed board and no longer do: a mounting
  hole sitting in the parked pile is INFO, not an ERROR about being off the board
  (an error still, if it is out there on its own); and an RF module whose antenna
  end overhangs the outline is INFO with a note to check the keepout, because that
  is how a WROOM or an E22 is meant to be placed.

**These are geometric heuristics.** They know nothing about component height, the
enclosure, keep-out zones you have not drawn, or your assembler's rules. Confirm
anything that matters against KiCad's own DRC and the mechanical drawing.

## `ic REF` - where the passives go

The only command here that answers "where should this go" instead of "what is
wrong". One call per regulator, ~35 lines, no reasoning required from the caller.
Run `ic` with no ref first to see which parts it can advise on.

Nothing is templated per part number: pins are classified by NAME (`VIN` `PGND`
`SW` `FB` `BOOT` `VCC/BIAS` `OUT`, with a blank pin sitting on GND counted as a
ground pin), and every position comes out of the real pad coordinates in the board
file. So a part it has never seen works, and a part whose pins are unnamed degrades
to "nothing positionable found" rather than to a confident wrong answer.

| role | where it is put | why |
| --- | --- | --- |
| input caps | straddling the **tightest VIN/PGND pad pair**, on the outside face of the package, smallest value innermost, extra caps stacked outward | that pad pair carries the high-di/dt loop; a cap across it *is* the small loop |
| inductor | hard against the SW pad(s), body pointing away from the package. Two switch nodes (a 4-switch buck-boost like the BQ25798) -> it bridges them instead | SW-pad-to-inductor is the other edge of the same loop, and the SW node is the antenna |
| output caps | a bank across the output node at the inductor's far pad, largest first | load current flows through them; a line of caps end to end would put the last one 25 mm downstream |
| feedback divider | out the far side of the package from SW, FB pad facing the IC | FB is the high-impedance node; it must not run past the SW pad or under the inductor |
| boot / bias caps | against the pins they serve | small loops of their own |
| a linear reg or load switch | no inductor, so the output cap straddles OUT/GND the same way the input cap straddles IN/GND | same rule, no switching node |
| a plain IC (no VIN pin) | supply pins found via the same name table `BYPASS` uses, caps straddling supply/GND | bypass placement is the loop rule at a smaller scale |

Rotations are snapped to 90 degrees. A pin pair on a diagonal would otherwise ask
for a 165.3-degree part, and the few degrees of loop cost nothing.

**`--anchor` is what makes it usable mid-placement.** The big parts land first, so
the inductor is usually down while the regulator is still in the parked pile. Given
that, "L4 is 90 mm from its slot" is true and useless - the inductor is not what
should move. So when the IC is unplaced and one of its passives is not, `ic` hangs
the whole layout off that part and reports **where the IC itself goes**.
`--anchor REF` picks a different one, `--anchor none` turns it off. Translation
only: if the anchor also needs turning, it says so and asks you to rotate the IC in
KiCad and re-run, because rotating it moves every pad.

The `now` column compares against what is already placed: `OK` (within `--tol`),
`4.8 mm / 90 deg off`, or `unplaced`. It also reports parts standing in a suggested
slot, feedback parts within `--fb` of a switching node, and the current input-loop
length against the suggested one.

**The honest limit is which caps belong to which regulator.** On a rail like `VSYS`
(20+ caps here) nothing in a `.kicad_pcb` says which cap the schematic drew next to
which pin. `ic` ranks by schematic sheet and by refdes proximity to the IC's own
private-net parts, prefers one cap of each distinct value so "smallest innermost"
means something, takes `--ncin`/`--ncout` of them, and **says in the output that it
guessed**. Two regulators on one rail can be offered the same cap. Check it against
the schematic and pass `--cin`/`--cout` once - that is the one number worth a
second call.

## `viapad` - which components have a via inside an SMD pad

`kpcb.py board.kicad_pcb viapad` lists every component where a via's centre lands
inside one of its SMD pads (via-in-pad). One line per pad, grouped by component:

```
via-in-pad: 106 via(s) in 58 SMD pad(s) across 49 component(s).
Same-net via-in-pad needs filled+capped (or type-VII) vias - flag it in the fab quote.

  U8     BQ25798                F.Cu
       pad EP   9 via(s)   OK same net (GND)
```

- **Same-net** (`OK same net (...)`) is intentional via-in-pad: the fab must fill
  and cap (or plate over) those via holes so the part still solders flat. It is a
  cost/process line item, not an error - exit 0.
- **Different-net** (`!! via net X != pad net Y - possible short`) means a via of a
  foreign net sits inside a pad. That is a short, not via-in-pad - exit 2. Confirm
  with `kdrc.py` (KiCad's own DRC is the authority on shorts).
- Only numbered SMD pads count; numberless paste/mechanical slivers are skipped.
- Only free board vias count. KiCad 10 cannot store a via inside a footprint (the
  grammar has no `via` under `footprint`), so every via is a board object anyway;
  the reader takes only top-level `(via)` and never a footprint child. There is no
  "manually placed vs auto" flag on a via in the file - a via is a via.
- The test is centre-in-pad, layer-aware (a blind/buried via that never reaches the
  pad's outer layer is not counted). Rect/roundrect/oval pads use the pad rectangle;
  a `custom`-shape pad is its anchor rectangle PLUS its `(primitives ...)` (gr_poly,
  gr_rect, gr_circle as a circumscribed 16-gon, gr_line as its stroke box). The
  anchor alone can be far smaller than the copper: BQ25798's pads are a 0.15 mm
  anchor with a 0.65 mm polygon.
- Roles: GND by name; PWR if a named rail, a net over `--fanout` nodes, a switching
  node, or a netclass matching PWR/POWER in the `.kicad_pro` (catches `Net-(BT1-+)`);
  else SIG. `--signal` shows only SIG pads, `--min N` only pads holding >= N vias.
  A different-net (possible short) row always prints, whatever the filter.

Back-side parts work without a mirror step: a `.kicad_pcb` stores each pad's `at`
**angle** as absolute (footprint rotation already baked in, unlike a `.kicad_mod`),
so the pad orientation is used directly. Validated against pcbnew's own `HitTest`
on the real board: 54/54 via-pad hits (5 on custom pads), zero false positives or
negatives, re-run 2026-09-22 after primitives parsing (validate with the pad's REAL
copper layer: `GetPrincipalLayer()` returns F.Cu for a back-side pad).

## `rf [NET...]` - a 50-ohm trace in one call

Per net: the routed widths by length (dominant width, and every NECK narrower than
95% of it, with location); microstrip Zo of the dominant width from the stackup
(Hammerstad + Wheeler thickness correction, uncoated, +/-1-2 ohm; solder mask pulls
it down ~1-2 ohm); the same-layer GND gap each side and, when it is close, the
field-solved CPWG Zo (below); what fills the reference layer
under the trace (`GND 100%`, else `BROKEN/NON-GND RETURN PATH`, exit 2); and the GND
via fence within `--fence` mm (1.5) of the trace edge: count per side and the widest
nearest-neighbour gap against lambda/20 in the medium (frequency from `--freq` MHz,
else inferred GNSS 1575.42 / LoRa 915 from the net or sheet name).

When a same-layer GND pour sits within 5h of the trace (median gap per side), the
line is **CPWG** and `rf` field-solves it: `Zo 51.6 ohm CPWG, field-solved with
F.Mask 15 um er 3.8 (52.8 uncoated)`, the mask read from the stackup. The closed
forms (Wadell/Ghione) are not used: they assume the backing plane is far vs the
slot, and on a 4-layer stackup (h 0.2 mm, w+2s ~1 mm) they read ABOVE microstrip,
which is physically backwards.

The solver is `scripts/kzo.py` (stdlib, also a CLI: `kzo.py W S H ER [T] [--mask TM
ERM]`): quasi-static finite-volume Laplace on a graded grid over half the cross-
section, solved directly (skyline Cholesky), capacitance from the field energy,
Zo = eta0 / sqrt(C C0). Unequal gaps solve each half with its own gap (within 0.1%
of a full solve). `kzo.py --selftest` holds it to exact stripline and CPW and to
Hammerstad microstrip, each within 2%; on a real 35 um trace it reads ~1% low.
Against JLC's own calculator (Polar SI9000, 2026-09-23, JLC04161H-7628 uncoated,
50 ohm widths for gaps 5/8/10 mil and microstrip) it reads 0.7-1.6% low, i.e.
JLC would put an `rf` line ~0.5-0.8 ohm higher. At a 16 mil gap JLC returns the
bare microstrip width (ignores the side ground); kzo does not, and reads 2.6% low there.
It models rectangular copper and the board file's stackup - the fab's trapezoid and
its own stackup numbers (check h and er in the `Zo ... microstrip` line against the
fab's) are the arbiter. ~0.1-0.2 s per solve, one call's solves in parallel, memoised
on disk (a re-run is instant until a gap, width or the stackup changes); gaps round to 0.01 mm.

## `movecheck` - try a nudge before making it

Read-only: it prints what a move would do and never writes the board. REF's pads
are re-placed at X,Y (and ROT, when given, turning them about the footprint origin)
as boxes, then measured against every foreign pad, track and via that shares a copper
layer (a through pad is on all of them), at the net-pair clearance `zones --voids`
uses (netclasses + `.kicad_dru` `NetName` pairs; same-net copper is never a hit),
plus copper to the edge (`Board.edge_clearance`) and a same-side courtyard overlap.
The same test runs at the current spot and only hits the new one adds print as
`NEW`, so a pre-existing violation is not blamed on the nudge. REF's own tracks
(ending on its pads) are left out: KiCad's Drag (D) brings them along, so re-check
those after the move. Zones are left out too: a refill flows around the part. Pads
are boxes, conservative for round pads on a diagonal. Exit 2 when something new hits.

`--scan x=113.3 y=81..87` slides REF's centre along a line (one axis fixed, one a
range, `--step` mm) and prints contiguous clear and blocked stretches with what
blocks each, so a centring move can pick its spot. `via X,Y NX,NY` takes the via
nearest X,Y (within 0.15 mm): `tied: nothing` means a bare stitching via that is free
to move (the pour reconnects it on refill); otherwise the tracks ending on it drag.

## `tidy` - near misses, with the fix already checked

Five passes over the placed parts (mounting holes only in the third):
- **near-miss**: same-side parts of one footprint within 6 mm (or siblings of a
  small family anywhere - <= 4 parts of that prefix and footprint, so SW1/SW2,
  J4/J8, BT1/BT2, never every 0402 cap) whose x or y agree within 0.15 mm; a part
  0.005-0.15 mm off the value most of the group shares (a tie: the lowest ref's)
  is moved onto it.
- **pitch**: a line of >= 3 same-footprint parts (one y, or one x) chained <= 6 mm
  apart whose pitches differ by 0.02 mm to 25% of the mean: the middle parts move
  to an even pitch between the two ends.
- **hole inset**: each mounting hole's x and y inset from the outline bbox; a hole
  0.005-0.5 mm off the common inset moves to it.
- **rotation**: a part whose rotation is not a multiple of 90 goes to the nearest.
- **centring**: a part whose centre sits inside a same-side part with >= 20x its
  courtyard area, 0.005-2 mm off that part's long centre line (Fab body, else
  courtyard), moves onto the line; the offset along the line is printed too.

Every suggestion runs through `movecheck` at its new spot (`clear`, or the first new
hit), so a fix that would break clearance says so before anyone drags the part.

## `freebox` - room for a silk box

A 0.25 mm raster of the side: blocked where outside the outline or within 1 mm of
it, under a placed same-side courtyard, under any through-hole pad (pad box, both
sides), or under that side's silk: padless art items, board-level `gr_*` silk, and
each footprint's visible silk text. Text boxes are estimated (0.9 x font width per
character, line height from the font, placed by `(justify)`, footprint text `(at)`
local with an absolute angle). Every centre whose W x H box is empty is a candidate;
4-connected candidates form a region, and each region reports the centre with the
largest margin (how far the box could grow on every side and stay clear; ties go to
the region's middle). Blocked cells are any cell an obstacle touches, so margins
err low by up to one cell. Tracks and pours are not obstacles: silk over masked
copper is fine. ~0.5 s.

## `silk` - where the logos really are

A footprint with no pads is art. Its side is where its items are (a B.Cu logo can
carry F.SilkS art), its extent is the union of its items' boxes with the footprint
`(scale)` applied (strokes not added), and it is HIDDEN when a placed same-side part's
body (Fab outline, else courtyard) covers >= 50% of that box: a module (U1, U12) or a
cell holder sits on it after assembly. `pads` counts same-side pads (and through
pads) whose copper box an art item's box touches; silk there is clipped at the mask
opening. Board-level silk (`gr_poly`/`gr_text` on *.SilkS) is not listed here; `freebox`
treats it as an obstacle.

## `view` - a picture of the board

`kicad-cli pcb export svg --layers .. --mode-single --exclude-drawing-sheet` (the right
CLI per file), cached under `~/.cache/kicad-review/pcbsvg/` per board save and layer
list. That SVG's viewBox is the page in mm with the board at its own coordinates, so
the crop is a viewBox rewrite (the ksheet `view` recipe), rasterised by `rsvg-convert`
at `--px 20` per mm on white; `-o x.svg` keeps the cropped SVG. Always seen from the
top: a B.* layer is not mirrored, so coordinates stay the board's. Zones show their
saved fill.

## `height [REF...]` - the Z budget

Runs `kicad-cli pcb export glb --no-board-body --no-dnp` (the right CLI per file),
so OCCT meshes the real STEP/WRL models as placed, then reads each part's node
bounds from the glTF (Y-up, metres; each node origin sits on its own board face).
Prints the tallest parts per side, then the Z stack at the tallest back-side parts:
`back part + board (between the model faces) + tallest front part whose courtyard
overlaps it`.

What it will not do is guess:
- a part with no loadable model is **UNKNOWN**, never 0 mm; one with several models
  where one file is missing is flagged PARTIAL;
- jumpers, net ties and test pads/holes with no model are "assumed flat copper",
  listed, with the note that a header pin in a TH test point adds height;
- a padless footprint with no model (a logo, pasted silk art) is not a part and is
  left out entirely, never UNKNOWN;
- a battery holder's model is flagged: it may omit the cell (the parsnip BT1/BT2
  model reads 15.8 mm; a 21700 is 21.7 mm across). Put the measured figure in
  kpcb.json `"height": {"BT1": 23.1}` - an override wins over the model and prints
  with `*`.
Enclosure, gasket, display and standoffs are not on the board and not counted.

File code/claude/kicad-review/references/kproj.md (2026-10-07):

# kproj / kverify / kfront - project structure, equivalence, front matter

Three tools for the edits that are not circuit edits: renaming or reordering
sheets, renumbering pages, adding a top-level sheet, then proving nothing about
the circuit moved, and keeping the cover / block diagram / power tree true.

## kproj.py - structure edits

```bash
kproj.py DIR rename OLD.kicad_sch NEW.kicad_sch
kproj.py DIR order NAME [NAME ...]          # navigator order of the top-level sheets
kproj.py DIR renumber                       # pages 1..N depth-first
kproj.py DIR add-sheet FILE NAME [--after NAME]
```

- `rename`: `git mv`; the `.kicad_pro` `top_level_sheets[].filename`, or each parent
  sheet symbol's `Sheetfile`; every `(sheetfile "OLD")` in the `.kicad_pcb` (metadata,
  so no Update PCB is needed, which would drag in unrelated pending edits); then
  lists every file in the repo that still names OLD (docs, CLAUDE.md, scripts).
- `order`: rewrites `schematic.top_level_sheets`, which the hierarchy navigator
  loads verbatim. Names not given keep their relative order after the named ones.
- `renumber`: top-level sheets in navigator order, each followed by its children in
  their current page order. A top-level page is its own file's
  `(sheet_instances (path "/" (page N)))`; a subsheet's is the parent's sheet symbol
  `(instances (project (path PARENT (page N))))`, edited inside that symbol only.
- `add-sheet`: creates FILE minimal (header copied from the first top-level sheet)
  if it does not exist, adds a fresh uuid to `top_level_sheets` and `sheets`, then
  renumbers.

Every command builds all edits in memory and asserts each replacement's exact
count; a mismatch writes nothing. The `.kicad_pro` must survive a JSON round trip
byte-for-byte (KiCad's own format does). It refuses while KiCad holds the project
(`kcommon.kicad_running`: a KiCad process, a `~*.lck` lock, an `_autosave-*` file);
`--force` overrides, `--dry-run` prints the edits. UUIDs and sheet names are never
touched, so instance paths and footprint links survive.

Tested on a copy of parsnip (2026-10-04): order Root first, renumber, rename
rails -> power_rails (1 Sheetfile + 96 board sheetfile entries), add a Notes sheet:
kicad-cli-nightly loads it, the PDF has 13 pages in order, `knet diff` is empty.

## kverify.py - did anything but the structure change?

```bash
kverify.py [DIR] [--ref HEAD] [--pages 6,7] [--no-erc] [--keep]
```

One PASS/FAIL line each, both trees frozen into a temp dir (KiCad may be saving):

| check | PASS means |
| --- | --- |
| netlist | `knet diff` of the two kmerge netlists: no part, field, connection or net name changed |
| ERC | violations keyed by type + item descriptions (no coordinates, no sheet names): none added or removed |
| sync | `kpcb sync` output identical, paths and dates stripped |
| pages | the working tree's PDF title-block Ids run 1..N in print order |
| sheets (INFO) | per changed sheet: `page 4 -> 6; 1119 coordinates moved, all by (-2.54,+0)` or `structure changed (N diff lines)` |
| render (`--pages`) | those pages vs the ref page with the same sheet path at 50 dpi, pixels differing > 40/255, bbox in mm |

~13 s with ERC. Exit 0 all PASS, 2 a FAIL, 3 a tool failed. Run it after any
`kproj` edit and after a GUI save that should only have moved things.
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

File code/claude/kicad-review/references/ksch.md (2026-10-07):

# ksch.py - drawing circuits

**Never hand-write SVG for a circuit, and never build one in the visualizer.**
Write a short spec, pipe it to `ksch.py`, `present_files` the `.svg`. A spec is ~20
short lines where hand-drawn SVG is hundreds, and the result looks like KiCad
instead of like boxes with text in them.

| situation | do this |
| --- | --- |
| the circuit is on the board | `knet.py FILE draw U8 -d 2 -o out.svg` - laid out from the netlist |
| ...and needs tidying | `knet.py FILE draw U8 --spec > x.ksch`, edit, `ksch.py render x.ksch -o out.svg` |
| the circuit is proposed / from a datasheet | write the spec by hand (below) |
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

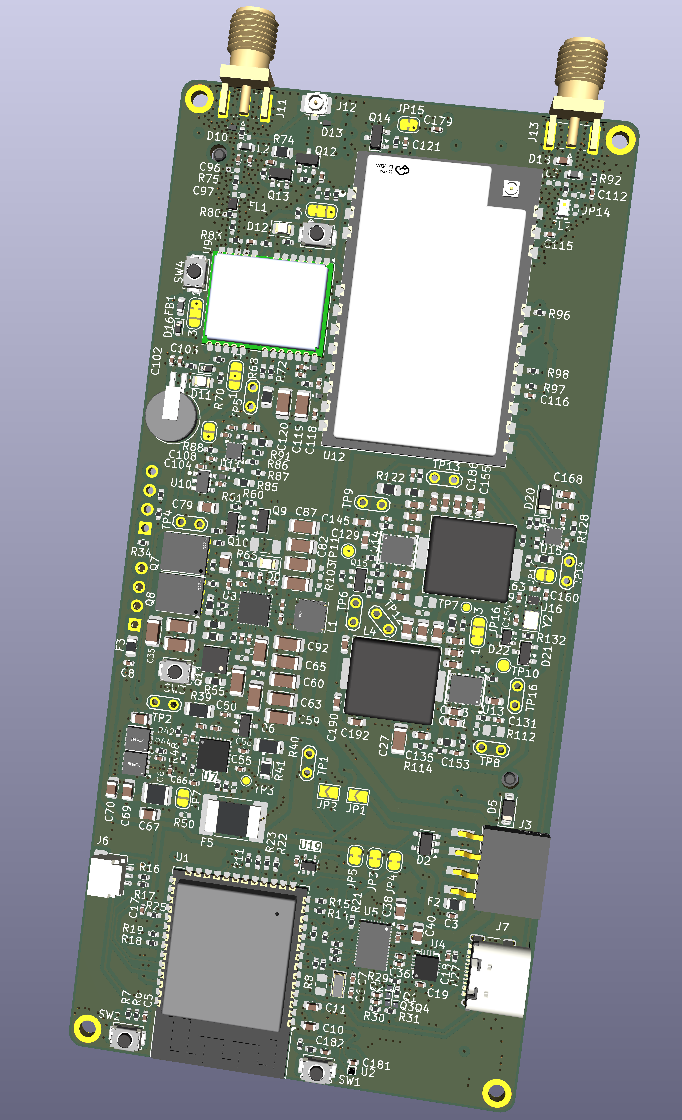
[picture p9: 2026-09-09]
parsnip.png

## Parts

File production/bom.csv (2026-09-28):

Reference | Qty | Value | Description | Manufacturer | MPN | LCSC Part | Footprint | DNP | Datasheet
R5,R6,R12,R13,R14,R15,R18,R19,R32,R33,R34,R69,R134 | 13 | 0 | RES 0Ω jumper 0402 | Vishay | CRCW04020000Z0EDHP | C844711 | Resistor_SMD:R_0402_1005Metric |  | https://datasheet.lcsc.com/datasheet/pdf/26cdfc55b8426b7658fe52a27bb4d16c.pdf?productCode=C844711
R75,R95 | 2 | 0 | RES 0Ω jumper 0402 | Vishay | CRCW04020000Z0EDHP | C844711 | Resistor_SMD:R_0402_1005Metric_Pad0.72x0.64mm_HandSolder |  | https://datasheet.lcsc.com/datasheet/pdf/26cdfc55b8426b7658fe52a27bb4d16c.pdf?productCode=C844711
R93 | 1 | 0 | RES 0Ω jumper 0402 | Vishay | CRCW04020000Z0EDHP | C844711 | Resistor_SMD:R_0402_1005Metric | DNP | https://datasheet.lcsc.com/datasheet/pdf/26cdfc55b8426b7658fe52a27bb4d16c.pdf?productCode=C844711
R100 | 1 | 0 | RES 0Ω jumper 0805 | UNI-ROYAL | 0805W8F0000T5E | C17477 | Resistor_SMD:R_0805_2012Metric |  | https://datasheet.lcsc.com/datasheet/pdf/0a975aaa49b7c97f38a963127be4a823.pdf?productCode=C17477
C153,C158 | 2 | 5.6pF | CAP MLCC 5.6pF 50V C0G 0402 | PSA (Prosperity Dielectrics) | FN15N5R6D500PNG | C525219 | Capacitor_SMD:C_0402_1005Metric_Pad0.74x0.62mm_HandSolder |  | https://datasheet.lcsc.com/datasheet/pdf/3d771c0c586676719f80e96a0f8d9dcd.pdf?productCode=C525219
C6,C7 | 2 | 7pF | CAP MLCC 7pF 50V C0G 0402 | PSA (Prosperity Dielectrics) | FN15N7R0D500PNG | C2929131 | Capacitor_SMD:C_0402_1005Metric |  | https://datasheet.lcsc.com/datasheet/pdf/2861834283c8f3616836bf6bb4d4e255.pdf?productCode=C2929131
C93 | 1 | 22pF | CAP MLCC 22pF ±5% 50V C0G 0402 | CCTC | TCC0402COG220J500AT | C696857 | Capacitor_SMD:C_0402_1005Metric |  | https://datasheet.lcsc.com/datasheet/pdf/960fc76f20dcdbc93ff4d1e2164767dc.pdf?productCode=C696857
C95,C115 | 2 | 47pF | CAP MLCC 47pF ±5% 50V C0G 0402 | HRE | CGA0402C0G470J500GT | C20069324 | Capacitor_SMD:C_0402_1005Metric |  | https://datasheet.lcsc.com/datasheet/pdf/dc7c513e4a82d65cc376cc0e5be62e16.pdf?productCode=C20069324
C33,C36 | 2 | 330pF | CAP MLCC 330pF ±1% 50V C0G 0402 | CCTC | TCC0402COG331F500AT | C53426851 | Capacitor_SMD:C_0402_1005Metric |  | https://datasheet.lcsc.com/datasheet/pdf/71a9f8eccc4da164324d4a716182c5e3.pdf?productCode=C53426851
C112,C159,C160 | 3 | 1nF | CAP MLCC 1nF ±5% 50V C0G 0402 | TORCH | CC0402CG50V102JN | C54916656 | Capacitor_SMD:C_0402_1005Metric |  | https://datasheet.lcsc.com/datasheet/pdf/49b70b003dccd16cc3fa313c34a02bab.pdf?productCode=C54916656
C108,C109,C161,C162 | 4 | 2.2nF | CAP MLCC 2.2nF ±2% 50V C0G 0402 | Murata | GRM1555C1H222GA01D | C2987940 | Capacitor_SMD:C_0402_1005Metric |  | https://datasheet.lcsc.com/datasheet/pdf/ae687d21155af07a1c72ad1115e7421f.pdf?productCode=C2987940
L6,L7 | 2 | 5.1nH | IND RF 5.1nH, 600mA, 130mΩ, multilayer, 0402 | TDK | MLG1005S5N1CTD25 | C404625 | Inductor_SMD:L_0402_1005Metric |  | https://datasheet.lcsc.com/datasheet/pdf/fe4699cfe0567e4501e6fca39e0f92ff.pdf?productCode=C404625
C21,C22,C23,C47,C98,C105,C132,C134 | 8 | 10nF | CAP MLCC 10nF ±20% 50V X7R 0402 | CCTC | TCC0402X7R103M500AT | C696856 | Capacitor_SMD:C_0402_1005Metric |  | https://datasheet.lcsc.com/datasheet/pdf/960fc76f20dcdbc93ff4d1e2164767dc.pdf?productCode=C696856
C96,C97 | 2 | 10nF | CAP MLCC 10nF ±20% 50V X7R 0402 | CCTC | TCC0402X7R103M500AT | C696856 | Capacitor_SMD:C_0402_1005Metric_Pad0.74x0.62mm_HandSolder | DNP | https://datasheet.lcsc.com/datasheet/pdf/960fc76f20dcdbc93ff4d1e2164767dc.pdf?productCode=C696856
C75,C76,C77 | 3 | 47nF | CAP MLCC 47nF ±10% 50V X7R 0402 | CCTC | TCC0402X7R473K500AT | C880605 | Capacitor_SMD:C_0402_1005Metric |  | https://datasheet.lcsc.com/datasheet/pdf/960fc76f20dcdbc93ff4d1e2164767dc.pdf?productCode=C880605
L2 | 1 | 47nH | IND RF 47nH ±2%, 380mA, 290mΩ, wirewound, 0603 | Murata | LQW18AN47NG00D | C98076 | Inductor_SMD:L_0603_1608Metric |  | https://datasheet.lcsc.com/datasheet/pdf/d18d069bcb310402631d9011b9a41597.pdf?productCode=C98076
C5,C19,C24,C49,C50,C51,C54,C61,C64,C66,C72,C80,C89,C91,C116,C121,C131,C136,C184 | 19 | 100nF | CAP MLCC 100nF ±5% 50V X7R 0402 | FH (Fenghua) | 0402B104J500NT | C5272680 | Capacitor_SMD:C_0402_1005Metric |  | https://datasheet.lcsc.com/datasheet/pdf/09fe2daf22580a99fa7fea93ccb20fb7.pdf?productCode=C5272680
C53,C55,C56 | 3 | 0.47uF | CAP MLCC 470nF ±10% 25V X5R 0402 | Chinocera | HGC0402R5474K250NTEJ | C49333230 | Capacitor_SMD:C_0402_1005Metric |  | https://datasheet.lcsc.com/datasheet/pdf/61633b63ed3f06bbdb19946a342cc748.pdf?productCode=C49333230
C58 | 1 | 0.47uF | CAP MLCC 470nF ±10% 25V X5R 0402 | Chinocera | HGC0402R5474K250NTEJ | C49333230 | Capacitor_SMD:C_0402_1005Metric | DNP | https://datasheet.lcsc.com/datasheet/pdf/61633b63ed3f06bbdb19946a342cc748.pdf?productCode=C49333230
L3 | 1 | 470nH | IND RF 470nH ±2%, 75mA, 7Ω, wirewound, 0603 | Murata | LQW18ANR47G00D | C113132 | Inductor_SMD:L_0603_1608Metric |  | https://datasheet.lcsc.com/datasheet/pdf/d18d069bcb310402631d9011b9a41597.pdf?productCode=C113132
C17,C18,C20,C25,C39,C41,C43,C45,C46,C94,C163,C164,C176,C178,C179,C180,C182 | 17 | 1uF | CAP MLCC 1uF ±10% 25V X7R 0402 | CCTC | TCC0402X7R105K250AT | C53426846 | Capacitor_SMD:C_0402_1005Metric |  | https://datasheet.lcsc.com/datasheet/pdf/71a9f8eccc4da164324d4a716182c5e3.pdf?productCode=C53426846
C37 | 1 | 1uF | CAP MLCC 1uF ±10% 50V X7R 0603 | Chinocera | HGC0603R7105K500NTHJ | C7432774 | Capacitor_SMD:C_0603_1608Metric |  | https://datasheet.lcsc.com/datasheet/pdf/3025399970486160f9625970e5fd5973.pdf?productCode=C7432774
C52,C117,C118 | 3 | 1uF | CAP MLCC 1uF ±10% 50V X5R 0402 | Chinocera | HGC0402R5105K500NTEJ | C7472948 | Capacitor_SMD:C_0402_1005Metric |  | https://datasheet.lcsc.com/datasheet/pdf/3025399970486160f9625970e5fd5973.pdf?productCode=C7472948
L1 | 1 | 2.2uH | IND POWER 2.2uH ±20%, Isat 5.6A, Irms 6.4A, 29mΩ, molded, 5.4x5.2mm | Sunlord | MWSA0503S-2R2MT | C408408 | Inductor_SMD:L_Sunlord_MWSA0503S |  | https://media.digikey.com/pdf/Data%20Sheets/Shenzhen%20Sunlord/MWSA-S_Series_DS.pdf
L4 | 1 | 2.2uH | IND POWER 2.2uH ±20%, Isat 18A, Irms 12A, 5.8mΩ, shielded, 10.8x10mm | Cybermax | CMLO1040H2R2MTT | C439019 | Inductor_SMD:L_APV_APH1040 |  | https://datasheet.lcsc.com/datasheet/pdf/7029bbea28904fe50f59ffe7f6ef38a1.pdf?productCode=C439019
C1,C2,C3,C8,C13,C104,C181 | 7 | 2.2uF | CAP MLCC 2.2uF ±10% 35V X5R 0402 | Chinocera | HGC0402R5225K350NTEJ | C33546001 | Capacitor_SMD:C_0402_1005Metric |  | https://datasheet.lcsc.com/datasheet/pdf/f608324e16dc58a8d3bf770f2f4184bc.pdf?productCode=C33546001
C62,C79 | 2 | 2.2uF | CAP MLCC 2.2uF ±10% 50V X7R 0805 | Samwha | CS2012X7R225K500NRE | C17702473 | Capacitor_SMD:C_0805_2012Metric |  | https://datasheet.lcsc.com/datasheet/pdf/de3131a7974cb4c72332356e43dd8fb0.pdf?productCode=C17702473
C125,C129,C135,C145 | 4 | 2.2uF | CAP MLCC 2.2uF ±10% 50V X5R 0603 | Chinocera | HGC0603R5225K500NTHJ | C7432769 | Capacitor_SMD:C_0603_1608Metric |  | https://datasheet.lcsc.com/datasheet/pdf/3025399970486160f9625970e5fd5973.pdf?productCode=C7432769
L5 | 1 | 3.3uH | IND POWER 3.3uH ±20%, Isat 16A, Irms 10A, 10mΩ, shielded, 10.8x10mm | Cybermax | CMLO1040H3R3MTT | C439020 | Inductor_SMD:L_APV_APH1040 |  | https://datasheet.lcsc.com/datasheet/pdf/7029bbea28904fe50f59ffe7f6ef38a1.pdf?productCode=C439020
C31 | 1 | 4.7uF | CAP MLCC 4.7uF ±10% 50V X7R 0805 | Chinocera | HGC0805R7475K500NSLJ | C7472970 | Capacitor_SMD:C_0805_2012Metric |  | https://datasheet.lcsc.com/datasheet/pdf/3025399970486160f9625970e5fd5973.pdf?productCode=C7472970
C78 | 1 | 4.7uF | CAP MLCC 4.7uF ±10% 35V X5R 0603 | Chinocera | HGC0603R5475K350NTHJ | C22367829 | Capacitor_SMD:C_0603_1608Metric |  | https://datasheet.lcsc.com/datasheet/pdf/c406d44fbf95883b4a8cac9a09b271ce.pdf?productCode=C22367829
C101 | 1 | 4.7uF | CAP MLCC 4.7uF ±20% 25V X5R 0402 | HRE | CGA0402X5R475M250GT | C6119795 | Capacitor_SMD:C_0402_1005Metric |  | https://datasheet.lcsc.com/datasheet/pdf/b1266b0c87197fb3f02855f4cd0e28e3.pdf?productCode=C6119795
C10,C11,C12,C16,C110,C122,C123,C124,C126,C127,C128,C137,C141,C143,C156,C168,C169,C177,C187,C188,C189,C190,C191,C192 | 24 | 10uF | CAP MLCC 10uF ±20% 35V X5R 0603 | CCTC | TCC0603X5R106M350CT | C22392391 | Capacitor_SMD:C_0603_1608Metric |  | https://datasheet.lcsc.com/datasheet/pdf/71a9f8eccc4da164324d4a716182c5e3.pdf?productCode=C22392391
C14,C38,C40,C42,C44,C48,C67,C68,C69,C70 | 10 | 10uF | CAP MLCC 10uF ±20% 50V X5R 0805 | HRE | CGA0805X5R106M500MT | C6119892 | Capacitor_SMD:C_0805_2012Metric |  | https://datasheet.lcsc.com/datasheet/pdf/84e3a6fd29786b629e1e2892084b001d.pdf?productCode=C6119892
C26,C27,C28,C29,C30,C32,C34,C35,C57,C59,C60,C63,C65,C73,C74,C82,C84,C85,C86,C87,C88,C90,C92 | 23 | 10uF | CAP MLCC 10uF ±10% 50V X7R 1206 | Chinocera | HGC1206R7106K500NSPJ | C33546013 | Capacitor_SMD:C_1206_3216Metric |  | https://datasheet.lcsc.com/datasheet/pdf/f608324e16dc58a8d3bf770f2f4184bc.pdf?productCode=C33546013
C71 | 1 | 10uF | CAP MLCC 10uF ±10% 50V X7R 1206 | Chinocera | HGC1206R7106K500NSPJ | C33546013 | Capacitor_SMD:C_1206_3216Metric | DNP | https://datasheet.lcsc.com/datasheet/pdf/f608324e16dc58a8d3bf770f2f4184bc.pdf?productCode=C33546013
C99,C100,C102,C103,C106,C107,C111,C130 | 8 | 10uF | CAP MLCC 10uF ±20% 10V X5R 0402 | HRE | CGA0402X5R106M100GT | C6119763 | Capacitor_SMD:C_0402_1005Metric |  | https://datasheet.lcsc.com/datasheet/pdf/f38cc67c7d42c83cd043a2a714280f66.pdf?productCode=C6119763
C119,C120 | 2 | 22uF | CAP MLCC 22uF ±10% 25V X5R 1206 | Samsung Electro-Mechanics | CL31A226KAHNNNE | C12891 | Capacitor_SMD:C_1206_3216Metric |  | https://datasheet.lcsc.com/datasheet/pdf/02336ea48ea44ca18c72517dd3cb7b47.pdf?productCode=C12891
C144,C147,C185 | 3 | 22uF | CAP MLCC 22uF ±20% 25V X5R 0805 | Samsung Electro-Mechanics | CL21A226MAYNNNE | C602037 | Capacitor_SMD:C_0805_2012Metric |  | https://datasheet.lcsc.com/datasheet/pdf/b322e2c5418a720f91470a94c6dd8af9.pdf?productCode=C602037
C155,C157,C165,C166,C167,C170,C171,C186 | 8 | 22uF | CAP MLCC 22uF ±20% 16V X5R 0603 | Chinocera | HGC0603R5226M160NTHJ | C22367828 | Capacitor_SMD:C_0603_1608Metric |  | https://datasheet.lcsc.com/datasheet/pdf/5a5c1da7b8866d662b18403c954de811.pdf?productCode=C22367828
R41 | 1 | 5m | RES current sense 5mΩ ±1% 500mW 0805 metal alloy | Yohey | YHR0805SE1DR005F5 | C42454064 | footprints:R_Shunt_0805_2012Metric_Kelvin |  | https://datasheet.lcsc.com/datasheet/pdf/0b4e40e8836ae059409dd4c822a860ed.pdf?productCode=C42454064
F1,F3 | 2 | 1A hold | FUSE PTC resettable 1A hold, 1.95A trip, 6V, 0805 | JDT | ASMD0805-100 | C135331 | Fuse:Fuse_0805_2012Metric |  | https://datasheet.lcsc.com/datasheet/pdf/54e07b777b7db1523783c1e8fbc2ace4.pdf?productCode=C135331
R49,R62 | 2 | 2 | RES 2Ω ±1% 62.5mW 0402 thick film | FOJAN | FRC0402F2R00TS | C2998051 | Resistor_SMD:R_0402_1005Metric |  | https://datasheet.lcsc.com/datasheet/pdf/106fb934f95f063b695dad1b31b1eab8.pdf?productCode=C2998051
F2 | 1 | 2A hold | FUSE PTC resettable 2A hold, 4A trip, 12V, 0805 | TECHFUSE | SL0805200-12V | C6851467 | Fuse:Fuse_0805_2012Metric |  | https://datasheet.lcsc.com/datasheet/pdf/e6a378b8a37019759bb545a349a60ab8.pdf?productCode=C6851467
F6 | 1 | 3A hold | FUSE PTC resettable 3A hold, 5A trip, 6V, 1812 | JKSEMI | JSMD1812-300 | C2972730 | Fuse:Fuse_1812_4532Metric |  | https://datasheet.lcsc.com/datasheet/pdf/82552fc8944c2b3427e6cd651b8d9c76.pdf?productCode=C2972730
R42,R120 | 2 | 10 | RES 10Ω ±1% 62.5mW 0402 thick film | SAE | 1RC0402F1009 | C54530672 | Resistor_SMD:R_0402_1005Metric |  | https://datasheet.lcsc.com/datasheet/pdf/dd253c5a1bb01d93e2ee5935d91e0850.pdf?productCode=C54530672
R114 | 1 | 10 | RES 10Ω ±1% 62.5mW 0402 thick film | SAE | 1RC0402F1009 | C54530672 | Resistor_SMD:R_0402_1005Metric_Pad0.72x0.64mm_HandSolder |  | https://datasheet.lcsc.com/datasheet/pdf/dd253c5a1bb01d93e2ee5935d91e0850.pdf?productCode=C54530672
F5 | 1 | 10A hold | FUSE PTC resettable 10A hold, 20A trip, 21V, 2920 | BHFUSE | BSMD2920L-1000-21V | C50338483 | Fuse:Fuse_2920_7451Metric |  | https://datasheet.lcsc.com/datasheet/pdf/14d81d7958d374dbae10273735207212.pdf?productCode=C50338483
R10,R11 | 2 | 22 | RES 22Ω ±0.5% 25ppm 62.5mW 0402 thin film | Viking Tech | ARG02DTC0220 | C2686485 | Resistor_SMD:R_0402_1005Metric_Pad0.72x0.64mm_HandSolder |  | https://datasheet.lcsc.com/datasheet/pdf/ec3e308e963624b453a77b63220f4bbf.pdf?productCode=C2686485
R16,R17,R98 | 3 | 22 | RES 22Ω ±0.5% 25ppm 62.5mW 0402 thin film | Viking Tech | ARG02DTC0220 | C2686485 | Resistor_SMD:R_0402_1005Metric |  | https://datasheet.lcsc.com/datasheet/pdf/ec3e308e963624b453a77b63220f4bbf.pdf?productCode=C2686485
R1,R2,R3,R4 | 4 | 33 | RES 33Ω ±1% 62.5mW 0402 thick film | SAE | 1RC0402F3309 | C54530835 | Resistor_SMD:R_0402_1005Metric_Pad0.72x0.64mm_HandSolder |  | https://datasheet.lcsc.com/datasheet/pdf/dd253c5a1bb01d93e2ee5935d91e0850.pdf?productCode=C54530835
R81 | 1 | 37.4 | RES 37.4Ω ±1% 100mW 0402 thick film | KOA Speer | RK73H1ETTP37R4F | C316909 | Resistor_SMD:R_0402_1005Metric_Pad0.72x0.64mm_HandSolder |  | https://datasheet.lcsc.com/datasheet/pdf/cf3f6680026d0b4e24a67f9c0020b354.pdf?productCode=C316909
R74 | 1 | 62 | RES 62Ω ±5% 500mW 0805 thick film | UNI-ROYAL | AS05W2J0620T5E | C560547 | Resistor_SMD:R_0805_2012Metric |  | https://datasheet.lcsc.com/datasheet/pdf/268cae34e8e40050f3b235878c2547d6.pdf?productCode=C560547
R44,R48,R59,R63,R103 | 5 | 100 | RES 100Ω ±0.5% 62.5mW 0402 thick film | FOJAN | FRH0402D1000TS | C55174701 | Resistor_SMD:R_0402_1005Metric |  | https://datasheet.lcsc.com/datasheet/pdf/504f856b50af18efa1efde88b61a976e.pdf?productCode=C55174701
R111,R117 | 2 | 100 | RES 100Ω ±0.5% 62.5mW 0402 thick film | FOJAN | FRH0402D1000TS | C55174701 | Resistor_SMD:R_0402_1005Metric_Pad0.72x0.64mm_HandSolder |  | https://datasheet.lcsc.com/datasheet/pdf/504f856b50af18efa1efde88b61a976e.pdf?productCode=C55174701
R39,R40 | 2 | 150 | RES 150Ω ±0.1% 25ppm 250mW 1206 thin film | YAGEO | RT1206BRD07150RL | C870430 | Resistor_SMD:R_1206_3216Metric |  | https://datasheet.lcsc.com/datasheet/pdf/46d7760c582640714d605308a25a220a.pdf?productCode=C870430
R80,R83 | 2 | 150 | RES 150Ω ±0.5% 25ppm 62.5mW 0402 thin film | Viking Tech | AR02DTC1500 | C319853 | Resistor_SMD:R_0402_1005Metric_Pad0.72x0.64mm_HandSolder |  | https://datasheet.lcsc.com/datasheet/pdf/1a751e5cacd14ca30f43df4722fba38e.pdf?productCode=C319853
R53,R57,R60,R61 | 4 | 294 | RES 294Ω ±0.1% 25ppm 62.5mW 0402 thin film | YAGEO | RT0402BRD07294RL | C852689 | Resistor_SMD:R_0402_1005Metric |  | https://datasheet.lcsc.com/datasheet/pdf/46d7760c582640714d605308a25a220a.pdf?productCode=C852689
R47 | 1 | 330 | RES 330Ω ±1% 750mW 1210 thick film | FOJAN | FRP1210F3300TS | C51048356 | Resistor_SMD:R_1210_3225Metric |  | https://datasheet.lcsc.com/datasheet/pdf/489c198fa8a2dcb8e174d477e7ad4924.pdf?productCode=C51048356
F4 | 1 | 350mA hold | FUSE PTC resettable 350mA hold, 750mA trip, 6V, 0805 | Brightking | SMD0805B035TF | C269103 | Fuse:Fuse_0805_2012Metric |  | https://datasheet.lcsc.com/datasheet/pdf/1f9f1003a75effea10bcf8c5507d7438.pdf?productCode=C269103
R128 | 1 | 549 | RES 549Ω ±1% 62.5mW 0402 thick film | Walsin | WR04X5490FTL | C172092 | Resistor_SMD:R_0402_1005Metric_Pad0.72x0.64mm_HandSolder |  | https://datasheet.lcsc.com/datasheet/pdf/b7fd8449de4a882cd112db0d86c915bb.pdf?productCode=C172092
R43,R45,R71,R78,R99 | 5 | 1k | RES 1kΩ ±0.1% 62.5mW 0402 thick film | FOJAN | FRH0402B1001TS | C48533754 | Resistor_SMD:R_0402_1005Metric |  | https://datasheet.lcsc.com/datasheet/pdf/dcb62c832dd79d37c154ec20e16fb58d.pdf?productCode=C48533754
R123,R124 | 2 | 1k | RES 1kΩ ±0.1% 62.5mW 0402 thick film | FOJAN | FRH0402B1001TS | C48533754 | Resistor_SMD:R_0402_1005Metric_Pad0.72x0.64mm_HandSolder |  | https://datasheet.lcsc.com/datasheet/pdf/dcb62c832dd79d37c154ec20e16fb58d.pdf?productCode=C48533754
R70 | 1 | 2k | RES 2kΩ ±0.1% 25ppm 62.5mW 0402 thin film | UNI-ROYAL | TC0225B2001TCC | C23539935 | Resistor_SMD:R_0402_1005Metric |  | https://datasheet.lcsc.com/datasheet/pdf/d0d02de47642fe4f4639912f1a5cccad.pdf?productCode=C23539935
R21,R22,R68,R72 | 4 | 2.2k | RES 2.2kΩ ±0.1% 25ppm 62.5mW 0402 thin film | UNI-ROYAL | TC0225B2201TCC | C23901508 | Resistor_SMD:R_0402_1005Metric_Pad0.72x0.64mm_HandSolder |  | https://datasheet.lcsc.com/datasheet/pdf/d0d02de47642fe4f4639912f1a5cccad.pdf?productCode=C23901508
R36,R37 | 2 | 2.2k | RES 2.2kΩ ±0.1% 25ppm 62.5mW 0402 thin film | UNI-ROYAL | TC0225B2201TCC | C23901508 | Resistor_SMD:R_0402_1005Metric |  | https://datasheet.lcsc.com/datasheet/pdf/d0d02de47642fe4f4639912f1a5cccad.pdf?productCode=C23901508
R66 | 1 | 3k | RES 3kΩ ±0.1% 25ppm 62.5mW 0402 thin film | UNI-ROYAL | TC0225B3001TCC | C29269950 | Resistor_SMD:R_0402_1005Metric_Pad0.72x0.64mm_HandSolder |  | https://datasheet.lcsc.com/datasheet/pdf/d0d02de47642fe4f4639912f1a5cccad.pdf?productCode=C29269950
R126 | 1 | 3.92k | RES 3.92kΩ ±0.1% 25ppm 60mW 0402 thin film | RESI | PTFR0402B3K92P9 | C2692963 | Resistor_SMD:R_0402_1005Metric |  | https://datasheet.lcsc.com/datasheet/pdf/19fb9d121ec124c867093c26b2505da9.pdf?productCode=C2692963
R82 | 1 | 4.7k | RES 4.7kΩ ±0.1% 25ppm 62.5mW 0402 thin film | Viking Tech | AR02BTC4701 | C317921 | Resistor_SMD:R_0402_1005Metric |  | https://datasheet.lcsc.com/datasheet/pdf/1a751e5cacd14ca30f43df4722fba38e.pdf?productCode=C317921
R51 | 1 | 5.23k | RES 5.23kΩ ±0.1% 25ppm 100mW 0603 thin film | YAGEO | RT0603BRD075K23L | C861485 | Resistor_SMD:R_0603_1608Metric_Pad0.98x0.95mm_HandSolder |  | https://datasheet.lcsc.com/datasheet/pdf/46d7760c582640714d605308a25a220a.pdf?productCode=C861485
R109,R110 | 2 | 6.04k | RES 6.04kΩ ±0.1% 25ppm 62.5mW 0402 thin film | YAGEO | RT0402BRD076K04L | C852895 | Resistor_SMD:R_0402_1005Metric_Pad0.72x0.64mm_HandSolder |  | https://datasheet.lcsc.com/datasheet/pdf/46d7760c582640714d605308a25a220a.pdf?productCode=C852895
R88 | 1 | 6.65k | RES 6.65kΩ ±1% 62.5mW 0402 thick film | GiantOhm | GR0402F6K65TAG00 | C49655648 | Resistor_SMD:R_0402_1005Metric_Pad0.72x0.64mm_HandSolder |  | https://datasheet.lcsc.com/datasheet/pdf/c3fe41080cc311a09e2390c2e42d8ed5.pdf?productCode=C49655648
R58 | 1 | 8.2k | RES 8.2kΩ ±0.1% 25ppm 62.5mW 0402 thin film | Viking Tech | ARG02BTC8201 | C2984429 | Resistor_SMD:R_0402_1005Metric_Pad0.72x0.64mm_HandSolder |  | https://datasheet.lcsc.com/datasheet/pdf/f4da32bad2b63678770dda69cfcd538f.pdf?productCode=C2984429
R7,R9,R35,R38,R46,R67,R76,R92,R94,R97,R101,R113,R119,R132,R135 | 15 | 10k | RES 10kΩ ±0.5% 62.5mW 0402 thick film | FOJAN | FRH0402D1002TS | C54951138 | Resistor_SMD:R_0402_1005Metric |  | https://datasheet.lcsc.com/datasheet/pdf/68379ec060dbf46ca58f0ea52f41dfcd.pdf?productCode=C54951138
R20,R24,R25,R26,R133 | 5 | 10k | RES 10kΩ ±0.5% 62.5mW 0402 thick film | FOJAN | FRH0402D1002TS | C54951138 | Resistor_SMD:R_0402_1005Metric_Pad0.72x0.64mm_HandSolder |  | https://datasheet.lcsc.com/datasheet/pdf/68379ec060dbf46ca58f0ea52f41dfcd.pdf?productCode=C54951138
RN1 | 1 | 10k | RES ARRAY 4x 10kΩ ±1% 62.5mW, isolated, 0402x4 | UNI-ROYAL | 4D02WGF1002TCE | C414600 | Resistor_SMD:R_Array_Concave_4x0402 |  | https://datasheet.lcsc.com/datasheet/pdf/a787d81013d5a35f6592045f155fa14b.pdf?productCode=C414600
TH1,TH2,TH3,TH4,TH5 | 5 | 10k | THERMISTOR NTC 10kΩ ±0.5%, B25/50 3380K, B25/85 3434K, 0603 | Murata | NCU18XH103D60RB | C3154661 | Resistor_SMD:R_0603_1608Metric |  | https://datasheet.lcsc.com/datasheet/pdf/96521737ad0f9ef1479d185ba532c802.pdf?productCode=C3154661
BT1,BT2 | 2 | 21700 Li-ion | BATTERY HOLDER 1x 21700 cylindrical, SMD (cell not included) | MYOUNG | BH-21700-B1BJ001 | C20606791 | easyeda2kicad:BAT-SMD_L82.5.5-W25-BH-21700-B1BJ001 |  | https://datasheet.lcsc.com/datasheet/pdf/f19fdde684eed5e7f56342763817f937.pdf?productCode=C20606791
R54 | 1 | 24.3k | RES 24.3kΩ ±0.1% 25ppm 100mW 0603 thin film | Viking Tech | ARG03BTC2432 | C2681615 | Resistor_SMD:R_0603_1608Metric_Pad0.98x0.95mm_HandSolder |  | https://datasheet.lcsc.com/datasheet/pdf/ec3e308e963624b453a77b63220f4bbf.pdf?productCode=C2681615
R127 | 1 | 27.4k | RES 27.4kΩ ±0.1% 25ppm 62.5mW 0402 thin film | YAGEO | RT0402BRD0727K4L | C852679 | Resistor_SMD:R_0402_1005Metric |  | https://datasheet.lcsc.com/datasheet/pdf/46d7760c582640714d605308a25a220a.pdf?productCode=C852679
R52 | 1 | 30.1k | RES 30.1kΩ ±0.1% 25ppm 100mW 0603 thin film | UNI-ROYAL | TC0325B3012T5F | C2989442 | Resistor_SMD:R_0603_1608Metric_Pad0.98x0.95mm_HandSolder |  | https://datasheet.lcsc.com/datasheet/pdf/d0d02de47642fe4f4639912f1a5cccad.pdf?productCode=C2989442
Y1 | 1 | 32.768kHz | CRYSTAL 32.768kHz ±20ppm, 6pF load, 3.2x1.5mm SMD | HCI | 3131M-32.768DT06LL-R50L | C41349295 | Crystal:Crystal_SMD_3215-2Pin_3.2x1.5mm |  | https://datasheet.lcsc.com/datasheet/pdf/30cea5fb4d3c9bcf5a50b1cd00711031.pdf?productCode=C41349295
R55 | 1 | 68.1k | RES 68.1kΩ ±0.1% 50ppm 100mW 0603 thin film | FH (Fenghua) | THD03H6812BT | C5355251 | Resistor_SMD:R_0603_1608Metric_Pad0.98x0.95mm_HandSolder |  | https://datasheet.lcsc.com/datasheet/pdf/3bb2cb0c0e6d3f87f4eebcefd7c077b9.pdf?productCode=C5355251
R125 | 1 | 86.6k | RES 86.6kΩ ±0.1% 25ppm 62.5mW 0402 thin film | YAGEO | RT0402BRD0786K6L | C852935 | Resistor_SMD:R_0402_1005Metric |  | https://datasheet.lcsc.com/datasheet/pdf/46d7760c582640714d605308a25a220a.pdf?productCode=C852935
R23 | 1 | 100k | RES 100kΩ ±0.1% 25ppm 62.5mW 0402 thin film | Viking Tech | ARG02BTC1003 | C2984406 | Resistor_SMD:R_0402_1005Metric_Pad0.72x0.64mm_HandSolder |  | https://datasheet.lcsc.com/datasheet/pdf/f4da32bad2b63678770dda69cfcd538f.pdf?productCode=C2984406
R27,R28,R30,R56,R77,R79,R86,R91,R96,R105,R106,R108,R130,R131 | 14 | 100k | RES 100kΩ ±0.1% 25ppm 62.5mW 0402 thin film | Viking Tech | ARG02BTC1003 | C2984406 | Resistor_SMD:R_0402_1005Metric |  | https://datasheet.lcsc.com/datasheet/pdf/f4da32bad2b63678770dda69cfcd538f.pdf?productCode=C2984406
R122 | 1 | 101k | RES 101kΩ ±0.1% 25ppm 125mW 0805 thin film | YAGEO | RT0805BRD07101KL | C7302896 | Resistor_SMD:R_0805_2012Metric_Pad1.20x1.40mm_HandSolder |  | https://datasheet.lcsc.com/datasheet/pdf/46d7760c582640714d605308a25a220a.pdf?productCode=C7302896
R87 | 1 | 113k | RES 113kΩ ±0.1% 25ppm 62.5mW 0402 thin film | Viking Tech | ARG02BTC1133 | C1509597 | Resistor_SMD:R_0402_1005Metric_Pad0.72x0.64mm_HandSolder |  | https://datasheet.lcsc.com/datasheet/pdf/ec3e308e963624b453a77b63220f4bbf.pdf?productCode=C1509597
R84 | 1 | 150k | RES 150kΩ ±0.1% 25ppm 62.5mW 0402 thin film | Viking Tech | AR02BTC1503 | C319872 | Resistor_SMD:R_0402_1005Metric |  | https://datasheet.lcsc.com/datasheet/pdf/1a751e5cacd14ca30f43df4722fba38e.pdf?productCode=C319872
R116 | 1 | 174k | RES 174kΩ ±0.1% 25ppm 62.5mW 0402 thin film | YAGEO | RT0402BRD07174KL | C852565 | Resistor_SMD:R_0402_1005Metric_Pad0.72x0.64mm_HandSolder |  | https://datasheet.lcsc.com/datasheet/pdf/46d7760c582640714d605308a25a220a.pdf?productCode=C852565
R89 | 1 | 200k | RES 200kΩ ±0.1% 25ppm 100mW 0603 thin film | YAGEO | AT0603BRD07200KL | C723682 | Resistor_SMD:R_0603_1608Metric_Pad0.98x0.95mm_HandSolder |  | https://datasheet.lcsc.com/datasheet/pdf/837b5ba54f8063c3882b949c35751654.pdf?productCode=C723682
R85 | 1 | 215k | RES 215kΩ ±0.1% 25ppm 100mW 0603 thin film | YAGEO | RT0603BRD07215KL | C861226 | Resistor_SMD:R_0603_1608Metric_Pad0.98x0.95mm_HandSolder |  | https://datasheet.lcsc.com/datasheet/pdf/46d7760c582640714d605308a25a220a.pdf?productCode=C861226
R129 | 1 | 280k | RES 280kΩ ±0.1% 25ppm 100mW 0603 thin film | YAGEO | RT0603BRD07280KL | C705755 | Resistor_SMD:R_0603_1608Metric |  | https://datasheet.lcsc.com/datasheet/pdf/46d7760c582640714d605308a25a220a.pdf?productCode=C705755
R90 | 1 | 301k | RES 301kΩ ±0.1% 62.5mW 0402 thick film | YAGEO | RE0402BRE07301KL | C2936623 | Resistor_SMD:R_0402_1005Metric |  | https://datasheet.lcsc.com/datasheet/pdf/d90f79507c4f0181520be84507a3ee5e.pdf?productCode=C2936623
R104,R107,R115,R121 | 4 | 402k | RES 402kΩ ±0.1% 50ppm 100mW 0603 thin film | UNI-ROYAL | TC0350B4023T5F | C29269954 | Resistor_SMD:R_0603_1608Metric |  | https://datasheet.lcsc.com/datasheet/pdf/d0d02de47642fe4f4639912f1a5cccad.pdf?productCode=C29269954
R29,R31,R102 | 3 | 1M | RES 1MΩ ±0.1% 100mW 0402 | Walsin | WF04H1004BTL | C2918201 | Resistor_SMD:R_0402_1005Metric |  | https://datasheet.lcsc.com/datasheet/pdf/ab245271d0a5d84ab94e85543b99f406.pdf?productCode=C2918201
R8 | 1 | 10M | RES 10MΩ ±1% 125mW 0805 thick film | FH (Fenghua) | RS-05L1005FT | C273584 | Resistor_SMD:R_0805_2012Metric | DNP | https://datasheet.lcsc.com/datasheet/pdf/1fdbe8489cfdbe4917930f5e1bb150ed.pdf?productCode=C273584
FL2 | 1 | 0900LP15B0063001E | FILTER LPF 863-960MHz, 0.9dB IL max, 2fo/3fo 46/50dB min, 50Ω, 2.0x1.25mm | Johanson Technology | 0900LP15B0063001E | C17287560 | easyeda2kicad:FILTER-SMD_0805-8P-L2.0-W1.2-TL |  | https://www.johansontechnology.com/datasheets/0900LP15B0063/0900LP15B0063.pdf
D4 | 1 | 1N5819WS | DIODE Schottky 40V 1A, SOD-323 | Hottech | 1N5819WS | C191023 | Diode_SMD:D_SOD-323 |  | https://datasheet.lcsc.com/datasheet/pdf/c7a6590686b7be2f86b8eed4480e569c.pdf?productCode=C191023
Q14,Q15 | 2 | 2N7002 | MOSFET N-ch 60V 300mA, 2.2Ω @10V, SOT-23 | MSKSEMI | 2N7002 | C5331134 | Package_TO_SOT_SMD:SOT-23 |  | https://datasheet.lcsc.com/datasheet/pdf/57179c5c9aa646f2a378eacab3cf7b98.pdf?productCode=C5331134
Q12 | 1 | AO3401A | MOSFET P-ch 30V 4.2A, 50mΩ @10V, SOT-23 | UMW | AO3401A | C347476 | Package_TO_SOT_SMD:SOT-23 |  | https://datasheet.lcsc.com/datasheet/pdf/86cb8cf73c64cfcb0a49116b603c9133.pdf?productCode=C347476
Q5,Q6 | 2 | AON7544 | MOSFET N-ch 30V 30A, 5mΩ @10V, DFN-8 3x3 | Alpha & Omega Semiconductor | AON7544 | C315567 | easyeda2kicad:PQFN-8_L3.1-W3.1-P0.65-LS3.3-BL |  | https://datasheet.lcsc.com/datasheet/pdf/284fe12c8a629d82609bec3e8b59373e.pdf?productCode=C315567
FL1 | 1 | B39162B8389P810 | FILTER SAW GNSS L1/L5 dual-band (1575/1176MHz), 50Ω, 1.4x1.1mm | Qualcomm (RF360) | B39162B8389P810 | C5556161 | Filter:Filter_1411-5_1.4x1.1mm |  | https://datasheet.lcsc.com/datasheet/pdf/eab07ffddc7092a73be1e657f827b881.pdf?productCode=C5556161
D22 | 1 | BAT54W | DIODE Schottky 30V 200mA, SOT-323 | Slkor | BAT54W | C5186013 | Package_TO_SOT_SMD:SOT-323_SC-70 |  | https://datasheet.lcsc.com/datasheet/pdf/e786df3ccf901f03b0e2fe0250c12d5b.pdf?productCode=C5186013
D21 | 1 | BAT54A | DIODE Schottky dual common-anode 30V 200mA, SOT-23 | ALJ | BAT54A | C55258619 | Package_TO_SOT_SMD:SOT-23 |  | https://datasheet.lcsc.com/datasheet/pdf/fb870cce115bf1969f0248e0c049347e.pdf?productCode=C55258619
D23 | 1 | BAT54S | DIODE Schottky dual series 30V 200mA, SOT-23 | onsemi | BAT54SLT1G | C19726 | Package_TO_SOT_SMD:SOT-23 |  | https://www.onsemi.com/pdf/datasheet/bat54slt1-d.pdf
J9 | 1 | BAT_PORT | CONN HEADER 2-pos 1.25mm (PicoBlade-compatible), R/A SMD | DEALON | 1.25-2PWB | C2905009 | Connector_Molex:Molex_PicoBlade_53261-0271_1x02-1MP_P1.25mm_Horizontal | DNP | https://datasheet.lcsc.com/datasheet/pdf/06ca0829dd2139bfdbe6671a038f533c.pdf?productCode=C2905009
FB1 | 1 | BLM18HG601SN1D | FERRITE BEAD 600Ω @100MHz, 200mA, 1Ω DCR, 0603 | Murata | BLM18HG601SN1D | C85830 | Inductor_SMD:L_0603_1608Metric |  | https://datasheet.lcsc.com/datasheet/pdf/2f82b35c4cf051a1d6cd28b95b66d0d6.pdf?productCode=C85830
SW2 | 1 | BOOT | SWITCH TACTILE SPST-NO 1N, 12V 50mA, 3.9x2.9mm SMD | Alps Alpine | SKRKAHE020 | C202388 | Button_Switch_SMD:SW_Push_SPST_NO_Alps_SKRK |  | https://datasheet.lcsc.com/datasheet/pdf/fc71c00d1492142d2947c53c2600ec92.pdf?productCode=C202388
U8 | 1 | BQ25798 | IC CHARGER 1-4S Li-ion buck-boost NVDC, 5A, dual input, MPPT, I2C, QFN-29 4x4 | Texas Instruments | BQ25798RQMR | C2876593 | Package_DFN_QFN:Texas_RQM0029A_VQFN-29_4x4mm_P0.4mm |  | https://www.ti.com/lit/ds/symlink/bq25798.pdf
Q13 | 1 | BSS138 | MOSFET N-ch 50V 220mA, SOT-23 | KUU | BSS138 | C3015220 | Package_TO_SOT_SMD:SOT-23 |  | https://datasheet.lcsc.com/datasheet/pdf/e6afae9ee592dc8ff3f4f777ab821073.pdf?productCode=C3015220
D6 | 1 | BZX585-C15 | DIODE Zener 15V ±5% 300mW, SOD-523 | Nexperia | BZX585-C15,135 | C550633 | Diode_SMD:D_SOD-523 |  | https://assets.nexperia.com/documents/data-sheet/BZX585_SER.pdf
D8 | 1 | CHARGING | LED yellow-green 570nm, 0805 | YONGYUTAI | YLED0805YG | C19171393 | LED_SMD:LED_0805_2012Metric |  | https://datasheet.lcsc.com/datasheet/pdf/5be1a0b566c0d2fd12802eb473099d1e.pdf?productCode=C19171393
Q2,Q4 | 2 | CSD15380F3 | MOSFET N-ch 20V, 1.17Ω @4.5V, FemtoFET 0.73x0.64mm | Texas Instruments | CSD15380F3 | C529568 | Package_DFN_QFN:Texas_PicoStar_DFN-3_0.69x0.60mm |  | https://www.ti.com/lit/ds/symlink/csd15380f3.pdf
Q1,Q3 | 2 | CSD23280F3 | MOSFET P-ch 12V, 97mΩ @4.5V, FemtoFET 0.73x0.64mm | Texas Instruments | CSD23280F3T | C139374 | Package_DFN_QFN:Texas_PicoStar_DFN-3_0.69x0.60mm |  | https://www.ti.com/lit/ds/symlink/csd23280f3.pdf
Q11 | 1 | CSD17577Q3A | MOSFET N-ch 30V, 4.0mΩ @10V, SON 3.3x3.3mm | Texas Instruments | CSD17577Q3A | C201632 | Package_SON:VSON-8_3.3x3.3mm_P0.65mm_NexFET |  | https://www.ti.com/lit/ds/symlink/csd17577q3a.pdf
Q7,Q8 | 2 | CSD18512Q5B | MOSFET N-ch 40V, 1.3mΩ @10V, SON 5x6mm | Texas Instruments | CSD18512Q5B | C2863663 | Package_SON:VSONP-8-1EP_5x6_P1.27mm |  | https://www.ti.com/lit/ds/symlink/csd18512q5b.pdf
J5 | 1 | e-Ink Display Connector | CONN HEADER 8-pos 1.25mm (PicoBlade-compatible), R/A SMD | XUNPU | WAFER-MX1.25-8PWB | C3029365 | Connector_Molex:Molex_PicoBlade_53261-0871_1x08-1MP_P1.25mm_Horizontal |  | https://datasheet.lcsc.com/datasheet/pdf/f6cb73e789ca6a2f7227478908a083e9.pdf?productCode=C3029365
U12 | 1 | E22P-915M30S | MODULE LoRa 915MHz, SX1262 + PA, 30dBm (1W), SMD 38.5x24mm | Ebyte | E22P-915M30S | C51912672 | footprints:COMM-SMD_22P-P2.54-L38.5-W24.0_E22-400M33S |  | https://www.cdebyte.com/pdf-down.aspx?id=4333
D14 | 1 | ESD351DPYR | TVS ESD 3.6V Vrwm, 1.8pF, unidirectional, ±30kV, X1SON-2 0.6x1 | Texas Instruments | ESD351DPYR | C1974929 | Package_SON:Texas_DPY0002A_0.6x1mm_P0.65mm |  | https://www.ti.com/lit/ds/symlink/esd351.pdf
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

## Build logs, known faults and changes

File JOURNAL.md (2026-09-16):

# Total Hours Spent: 60

## Starting the journal - 4 hours (2026-08-07)

I thought I should probably get into some more Hack Club stuff, and add more documentation for what I'm doing so I don't forget. I'm in the process of revamping the circuit protection. For the amount of money these modules and ICs cost (~$50 CAD), I think it's wise to throw at least $5 in circuit protection components at it. Of course the best circuit protection is just being careful and taking the proper precautions, but I'm a little silly.

I've already protected the RF frontends of the LoRa and GNSS modules, with ESD diodes and current limiting, so I'm moving on to the power inputs. I'm looking at implementing the `TI TPS25947` family of eFuses, specifically the [TPS259470LRPWR](https://www.ti.com/product/TPS25947/part-details/TPS259470LRPWR), which Claude suggested. This eFuse has both an overvoltage protection feature and an overcurrent protection feature. In my GNSS module's datasheet, the NEO-M9N has a maximum power supply voltage of 3.6 V. I can then set the eFuse's OVLO (overvoltage lockout) to cut off power when the input voltage exceeds 3.55 V, just below the NEO's maximum. However, there is one issue with this. In order for the eFuse to recover and continue operation after a fault state, the 3V3 input power rail must fall below 3.25 V, which would never happen in regular use. But that would just mean I have to power off the device and turn it on again, which isn't that bad considering it protected my expensive module from frying.

KiCad Schematic TPS259470

Considering maybe adding a cheap 50-cent TVS diode to the TPS259470LRPWR input, as the datasheet says it may be helpful. I'll have to see.

## Finalizing circuit protection - 2 hours (2026-08-08)

* Switched from the `TPS259470LRPWR` to the `TPS259474LRPWR` for slightly better OVLO tolerances (5.5% to 1.7%), allowing the trip voltage to be more precise.
* Added a rechargeable battery to V_BCKP on U2.
* Decided on using the `TPS259474ARPWR` for the future buck converter output.

KiCad Schematic GNSS

## Research BMS and charge controller choices - 2 hours (2026-08-09)

I think I've settled on using the `MAX17320Gxx`. I was thinking of initially going with the `BQ40Z50`, but with that one you are forced to use some of TI's software and buy their testing equipment in order to program it. The MAX17320 is only a little more and has a whole host of nice-to-have features like cycle count and intelligent algorithms to calculate percentage. It is however quite expensive at $8 CAD per IC, but I think it's worth the safety and ease of use aspects. I watched [this YouTuber](https://www.youtube.com/watch?v=UUr-CJudg38) on how he designed his BMS, it was quite insightful.

MAX17320 schematic image

### Charge Controller Selection

As for the charge controller, I went with the [BQ25798](https://www.ti.com/product/BQ25798). It's relatively cheap at $3 CAD each, it's modern and a recent design, and highly efficient. It supports a wide range of input voltages (USB-C PD fast-charging!) and can even communicate with the microcontroller to set custom charge limits to preserve battery health. However, it's a little noisy with its four switching MOSFETs, so it's going to take some consideration in layout so as not to interrupt any data lines and RF components/traces.

My goal was to get a slightly more premium BMS that had some of the nice features you'd see in mobile phones.

## Wiring up the BMS - 3 hours (2026-08-10)

| my design | reference design |
| :---: | :---: |
| Custom Schematic | Reference Schematic |

I'm sure there are still some issues or things to double check, but it's a good start. I studied the example block diagram schematic from the datasheet, and a few other schematics I could find when googling "MAX17320G22+ kicad schematic". Claude said the `AON7534` N-channel MOSFET would be best, so I trusted it. I'm trying to think about how I'll have the thermistor placed, because I'm using two 21700 battery holders next to each other. Perhaps I could expose some copper and use one of those SMD NTC thermistors? The batteries would then be sitting very close to the thermistor, and perhaps I could add some type of thermally conductive but not electrically conductive material or foam. I don't like the idea of taping the thermistor to the batteries...

## Confirming BMS wiring, adding testpoints and voltage/power ratings to components - 3 hours (2026-08-13)

Spent some time today double-checking the wiring on the BMS and learning more about it from the datasheet. I'm much more confident in my wiring now, and I added some DNP components in case I need to swap anything or make changes to it afterwards, plus testpoints as well. Most of the capacitors I was planning on using are well below the voltage rating they should be for the BMS, so I made sure to explicitly mention capacitor voltage ratings in the part field in KiCad.

Next steps would be to make the `MAX17320G22+` symbol a little prettier and organize my wiring, and to wire the charge controller. It's a little hard to read in its current state. So many components on such a small symbol. Maybe I'll ask in the KiCad Discord for suggestions on how to make the BMS schematic a little clearer.

BMS MAX17320 changes

## Wiring up the charge controller & selecting buck converter and PD IC - 4 hours (2026-08-14)

Following the reference application schematic for the [BQ25798](https://www.ti.com/product/BQ25798) and calculated the inductor current for my application. Reading over the data, it's actually a pretty impressive piece of silicon for how many features it has in such a small package. It uses narrow voltage DC (NVDC), so it'll take power directly from your USB-C circuitry, regulate it within a certain range similar to your battery, and then you can power your buck converter and downstream devices from its `SYS` output at up to 6 A. No external power muxing needed, and it's really efficient. Battery charge current can be set fixed, or dynamically through its I2C bus. The downside is the high frequency switching (750 kHz - 1.5 MHz), but I think if I physically keep it distanced far enough away from the RF components, and choose a good inductor, I should be okay.

One thing I tried to keep in mind for the charge controller and BMS circuitry: even though I'm only planning on having two series batteries, I should try to make most of the components compatible with the maximum 4S that both ICs support. This means having all the components rated for `>25V`, so choosing capacitors that are rated for 50 V. In turn this would mean having to add more capacitors than I normally would, in order to satisfy capacitor DC bias derating at higher voltages.

wired BQ25798 schematic
*I do need to clean this up and make it look less muddled...*

For the USB-PD, I wanted to choose something cheap, easy and small. I have no need for extra features or for it to support a wide range of USB chargers. I went with the [HUSB238](https://en.hynetek.com/2421.html), specifically the `HUSB238_002DD`. It's about $0.70 CAD each on LCSC, and supports a fixed 9 V USB trigger. The more common option would be to use the `CH224K`, but it had a large package and looked "old", although it's cheaper.

Lastly, I need a 5 V rail to run off the outputted `SYS` from the charge controller, so approximately a `5V - 8.8V` input. Claude helped me choose the `LM61460-Q1`, specifically the [LM61460AASQRJRRQ1](https://www.ti.com/product/LM61460-Q1/part-details/LM61460AASQRJRRQ1). It's a little steep at $2 CAD on [LCSC](https://www.lcsc.com/product-detail/C1855832.html), but using TI components is nice, and this IC is ideal for powering sensitive high-frequency components (it has "Low EMI" in the title). One of the ways it achieves this low EMI is by letting you customize its switching frequency, thereby sacrificing efficiency for switching at a frequency that doesn't interfere with frequencies elsewhere on the board.

> The switching frequency can be set or synchronized between 200 kHz and 2.2 MHz to avoid noise sensitive frequency bands.

## Reworking power rails, adding antenna detection, and organization - 6 hours (2026-08-18)

* Added the [LM61460-Q1](https://www.ti.com/product/LM61460-Q1/part-details/LM61460AASQRJRRQ1) as my 3V3 switching buck converter, which is the same as for the 5V rail.
 
* Added an eFuse to the output of my 5V buck for additonal protection

* Added LoRa antenna detection to prevent high power transmits from damaging the E22P RF frontend.

* Renamed schematic sheets for clarity and to be updated for the name change from `limeskey-node` to `parsnip-node`
  
* Double checked capacitor voltage ratings are correct for the net

For the antenna detection, I didn't think it was possible to implement without something like an expensive VNA. But apparently, since most LoRa antennas are DC-shorted, you can put a small amount of current on the antenna trace and check and see if it's still there with a FET. If the antenna is installed correctly, there should be no DC voltage on the antenna net, but if it wasn't, it would show 3V3 and the LoRA module would automatically stop transmitting.

5v rail

## USB Interface - USB-OTG at 60W! - 6 hours (2026-08-21)

### USB-OTG
I learnt what USB-OTG was and it turns out my charge controller already supports it, and for two dollars more, I could upgrade my current USB-PD IC to something that also supports USB-OTG. USB-OTG allows USB device to charge another device, acting like a power supply, with the same voltages and currents a regular wall-adapter USB-C brick would do. 

The `BQ25798` can do USB-OTG at 3.32A maximum, and at up to 22V; I'll likely set it to do 20V at 3A. My 2S 21700 batteries can do approximately 10A contiously at 8V, so something around 80W total, but it's best not to push them that far. And 60W, what the maximum is for the BQ25798, is plenty. 

### USB Power Delivery
As for USB-PD, I went from the $0.50 USD `HUSB238` to the $2.50 USD `TPS25751`, specifically for the USB-OTG feature. It also turns out this new PD IC has some nice circuit protection features, like reverse current protection, undervoltage and overvoltage protection, protection against some non-compliant USB devices for the CC pins, but most importantly for me, it has liquid detection. It can detect when water gets into the USB-C port and either slow down charging, or shut off completely. You do need four FETs in order to use this feature, but they aren't very expensive or large.

Additionally I added some optional protection components to the USB-C port, a surge protection device [TVS2200DRVR](https://www.ti.com/product/TVS2200/part-details/TVS2200DRVR), a TVS device [TPD4E05U06](https://www.ti.com/product/TPD4E05U06/part-details/TPD4E05U06DQAR), and an ESD protection device [TPD8S300A](https://www.ti.com/product/TPD8S300A). These were a little expensive (a few dollars), and a little large, but they're really nice to have. I want my board to withstand anthing basically lol.

USB Interface

Next steps would probably be to double check I wired everything right, then move onto wiring the ESP32-S3 which hopefully won't be very difficult.

## E-Ink Display & Schematic Cleanup - 4 hours (2026-08-24)

### Cleanup
Today I worked on making the schematic a bit easier to read and understand, as I'm having a few people review it. Additionally, I assigned communication labels to a few unused pins on my ESP32 and tidied up the connector section in the root schematic. I am thinking it would be helpful if I were to expand the size of some symbols so it's easier to see all the components in between the IC pins. I have plenty of schematic room so why not make everything a little larger and more spread out? It's what I commonly see in more professional schematics, such as my laptop's motherboard schematic.

### E-Ink
I am toying with the idea of adding a 2.9" E-Ink/E-Paper display ([AliExpress](https://www.aliexpress.com/item/1005004644515880.html)) on the back of the PCB, against where the two 21700 batteries go. I'm thinking it could be attached to long M.2 standoffs ([AliExpress](https://www.aliexpress.com/item/1005008713639234.html)), and screwed into my board's mounting holes. It would be nice then to show information about where the user is currently located and how many LoRa nodes the device currently sees. It seems like non-tech people that I show my prototype/v1 device to, they are offput by the idea of having to use a phone. Perhaps they feel like it defeats the purpose of my device. To me, it doesn't impact the device much at all, since I'm only simply using the display and touchscreen of the phone and that's all. The phone doesn't have to have any sort of GNSS/Wifi/Cellular Internet for it to work, but non-techy people don't really understand that.

However, if I were to add a display, it would be intuitive for the user to also interact with the display. I would almost have to add a button of some sorts. I was considering adding a [capacitive sensor](https://hackaday.io/project/202684-io-touch-every-io-pin-is-a-capacitive-sensor) to my PCB, it looks pretty simple, however it requires a lot of space, space which I don't really have. Need to think more...

Oh, also, I changed from a `GPL-3.0` license to the `CC BY-NC-SA 4.0` license, it better aligns with my views.

ESP32 Wiring, root schematic

## Reducing Buck Converter EMI - 6 hours (2026-08-26)

As it stands, I have two of the same low-EMI buck converter ICs for my 5V and 3.3V rail. Both of them switch at the same frequency, which should be fine, right? Wrong, both buck converters have drift and may not statup at the exact same time; and even if they were in sync/phase, you wouldn't want them to be anyways. Ideally, you'd want your buck converters to be switching at alternate times, one switches after another. Fortunately, there is a sync feature built right into the buck converters which can do exactly this. However you'd need an external clock.., well maybe two, one 0 degrees phase shifted, and another 180 degrees phase shifted.

Well, you could use a [4MHz oscillator](https://www.lcsc.com/product-detail/C2901612.html), and a [flip-flop](https://www.ti.com/product/SN74LVC1G74), sounds like a plan. Until you realize the oscillator draws 10 mA!!!! I don't have anything on the board except the main buck converter itself that could provide 3V3 @ 10mA. And of course, you can't power the oscillator from the output of the very buck converter it's trying to switch on, right? Actually apparently you can. The sync pin is very much optional, and when it's absent, the buck converter relies on it's own oscillator. So basically the only downside is poor EMI for 1 second at startup, which is nothing.

Buck oscillator circuit

Also in this journal:
* Adjustments to eFuse limits again
* Reduce 5V buck from 5.1v to 5.02v for added safety
* Add footprints & voltage ratngs to a lot of capacitors
* Fix flipped FET for liquid detection
* Add a magnometer

## Starting PCB Layout - 4 Hours (2026-08-29)

Worked today on the PCB, finally moving on from the schematic. Hopefully I can get it fully wired within the next few days. I am starting with grouping together ICs with their components as per the schematic, and thinking about where all the major components and items should go. Connectors on the bottom, battery on the backside top, the BMS & battery circuitry middle-left, and the buck converters middle-right.

PCB View

## Layout done - working on routing - 4 hours (2026-09-01)

Went to a local makerspace, Hacklab, to work on the PCB some more. Now that I'm on my laptop, I didn't have the 3D Models transfer over, since I was using easyeda2kicad and that put the models inside a local directory on my computer - not in the repo. I re-downloaded all the 3D Models and moved them into `lib/3d-models` and then changed the 3D model location for all missing components. Now when someone opens my PCB and checks the 3D View, all the components should show up nicely. A couple parts had incorrect footprints for the part, and I was able to fix this after seeing the 3D Model was obviously different from the footprint. That's one reason I like 3D Models so much.

## Routing done - 8 hours (2026-09-07)

Spent the last several days routing, it has been pretty awful. I don't know why I thought the routing would be easy to complete in a few days if the schematic took a month and a half to do. It would have been so much nicer if the board was larger. Difficult parts were ensuring my traces were wide enough, there's so many different nets all requiring 3A+,then routing the communication lines & USB data pairs. There's so many communication lines going all over the board, it's atrocious. I'm so glad to be mostly finished.

Credit to @spheresva for helping a bit with layout.

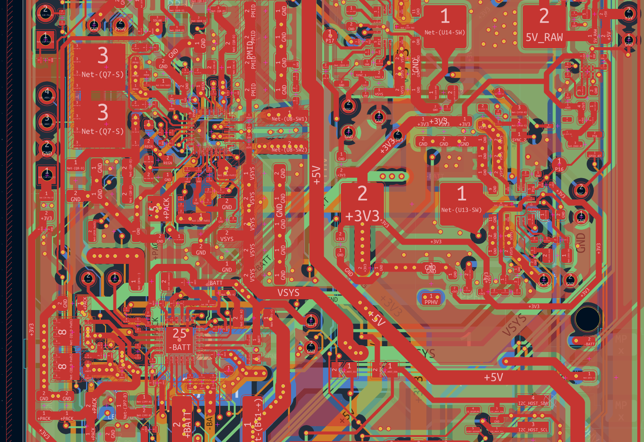
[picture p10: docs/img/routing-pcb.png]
PCB KiCad Routing


## Further routing optimization & Compability with the NEO-F10N - 4 hours (2026-09-14)

Yesterday and today I spent most of my time fixing routing issues, ensuring manufacturability with JLCPCB & PCBWay, and modifying the GNSS sheet to also work with the NEO-F10N.

The `NEO-F10N` is about two years newer, and supports both L1 and L5 GNSS bands, an upgrade to the NEO-M9N which only supports L1. The additional L5 makes location aquisition in urban areas more reliable and accurate. The good news with the `NEO-F10N` is that it only costs a couple dollars more than the previous `NEO-M9N`, however it's harder to find, not on LCSC or AliExpres. A little while ago, I messaged a person on Reddit about their similr LORA/GNSS board, and they told me how much nicer the NEO-F10N was, it's kind of convinced me to switch.

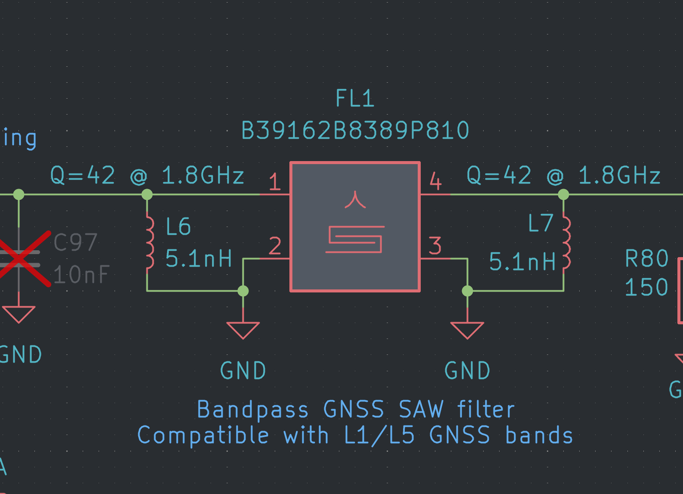
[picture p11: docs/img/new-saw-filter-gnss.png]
B39162B8389P810 GNSS SAW


As for the routing, I realized a lot of my VIAs and Traces were too small. I was using some `0.25/0.15mm` VIAs because that is what the minimum JLCPCB/PCBWay supports, but as it turns out, that minimum is only when you pay extra! It's about 70$ CAD more to use this smaller VIAs, which doesn't make much sense for me. I am changing back to using `0.5/0.2mm`, but it's tricky. As for the traces, I thought I could do `0.1mm`, but actually `0.127mm` is the limit if you're routing on the top and bottom layers. `0.1mm` is okay but only for the inner layers unfortunately.

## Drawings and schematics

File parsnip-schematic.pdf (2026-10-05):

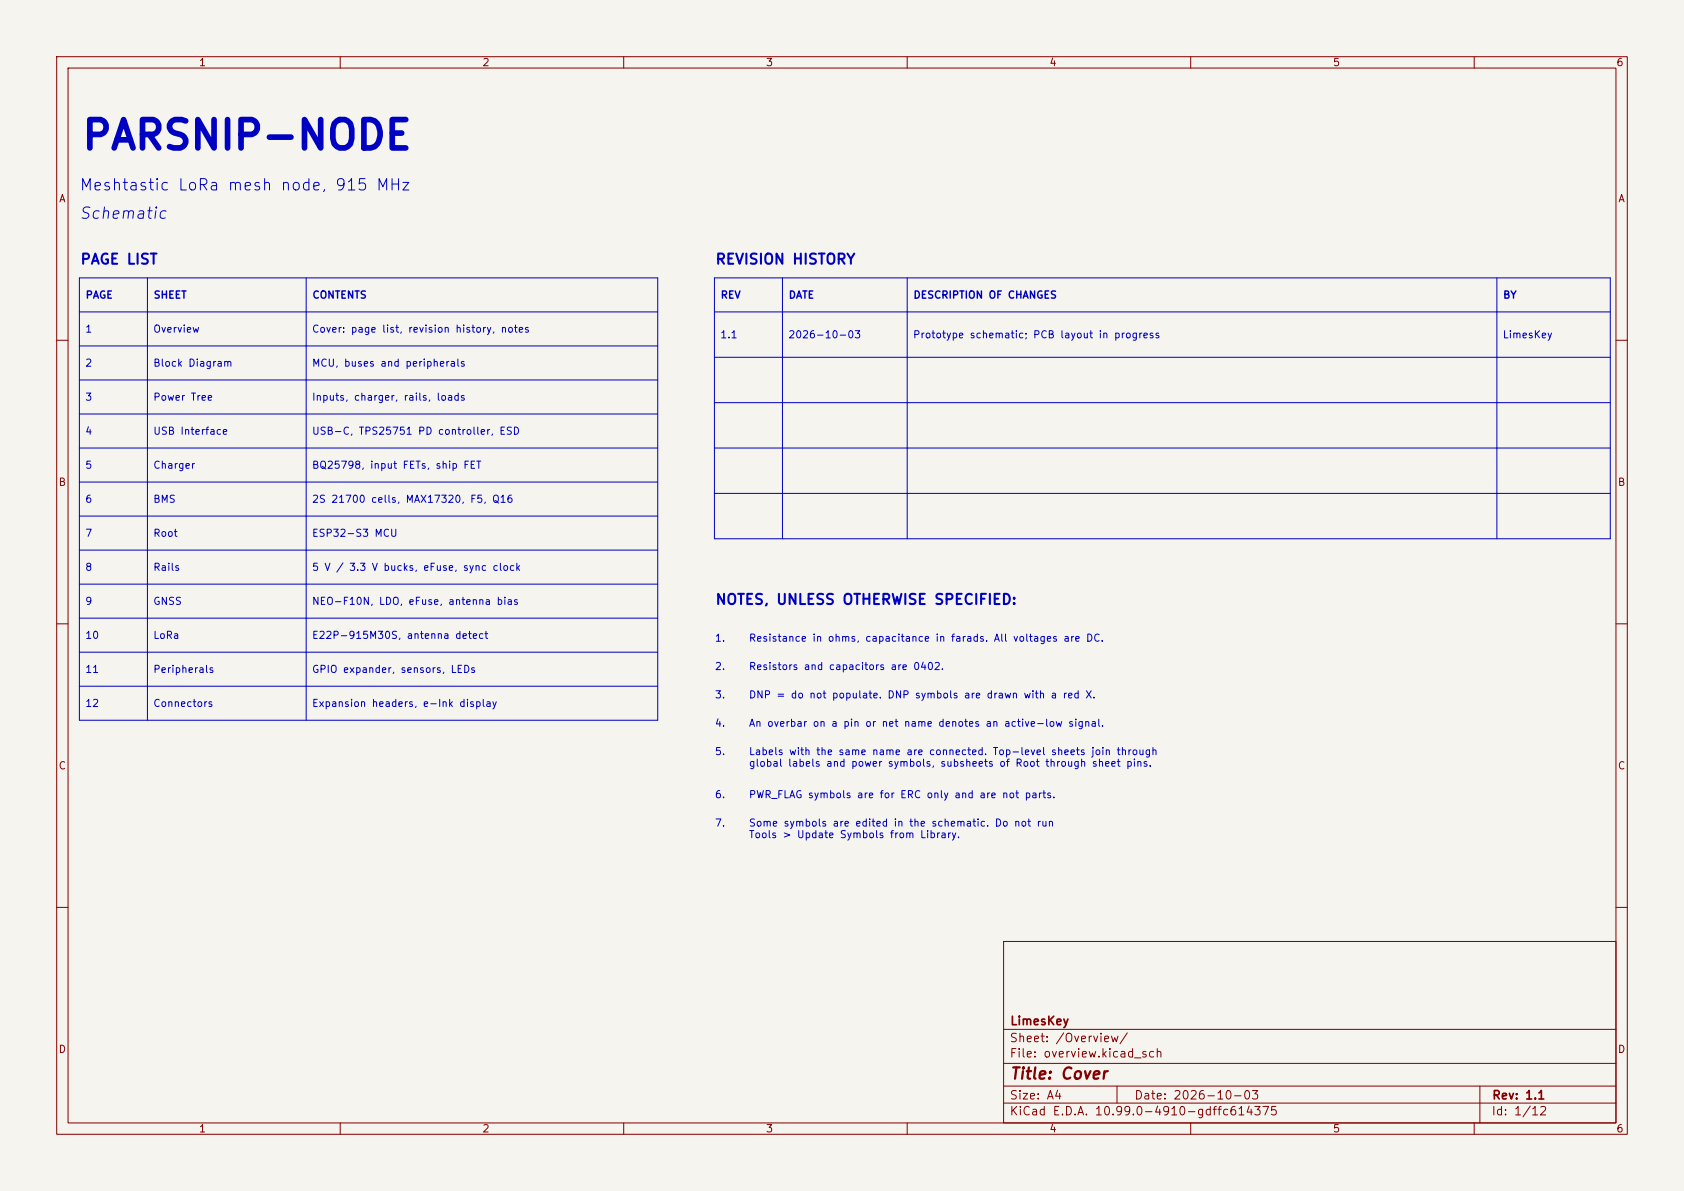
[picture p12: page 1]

Meshtastic LoRa mesh node, 915 MHz
Schematic

5 | Charger BMS | BQ25798, input FETs, ship FET 6 2S 21700 cells, MAX17320, F5, Q16

7 | Root | ESP32-S3 MCU

2. Resistance in ohms, capacitance in farads. All voltages are DC. PWR_FLAG symbols are for ERC only and are not parts. An overbar on a pin or net name denotes an active-low signal. 1. NOTES, UNLESS OTHERWISE SPECIFIED:

Size: A4 | Rev: 1.1
KiCad E.D.A. 10.99.0-4910-gdffc614375 | Id: 1/12

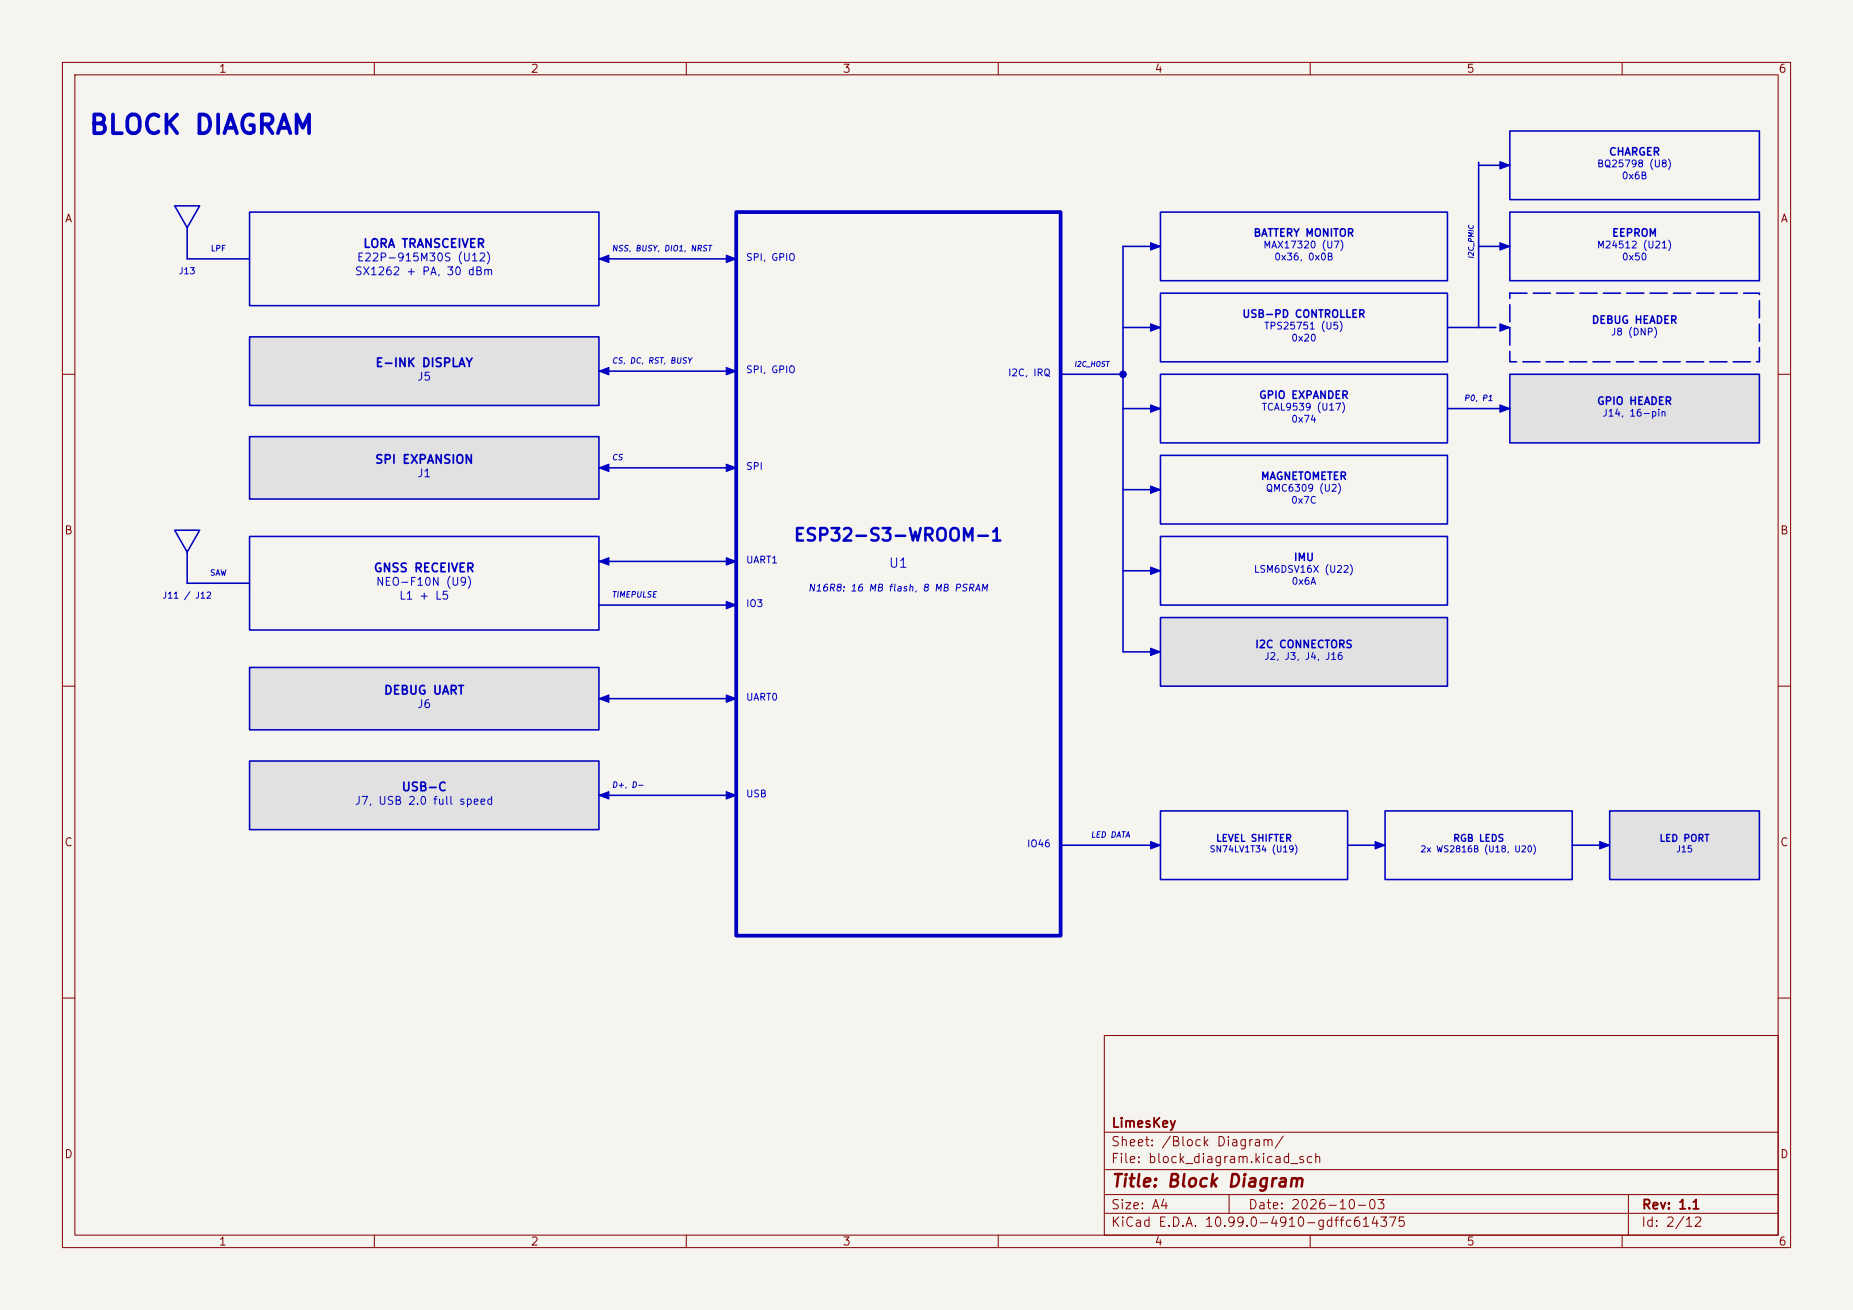
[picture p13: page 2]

GPIO HEADER SX1262 + PA, 30 dBm

LORA TRANSCEIVER
NSS, BUSY, DIO1, NRST CS, DC, RST, BUSY CS
SPI TIMEPULSE D+, D-

LSM6DSV16X (U22) LEVEL SHIFTER LED DATA N16R8: 16 MB flash, 8 MB PSRAM

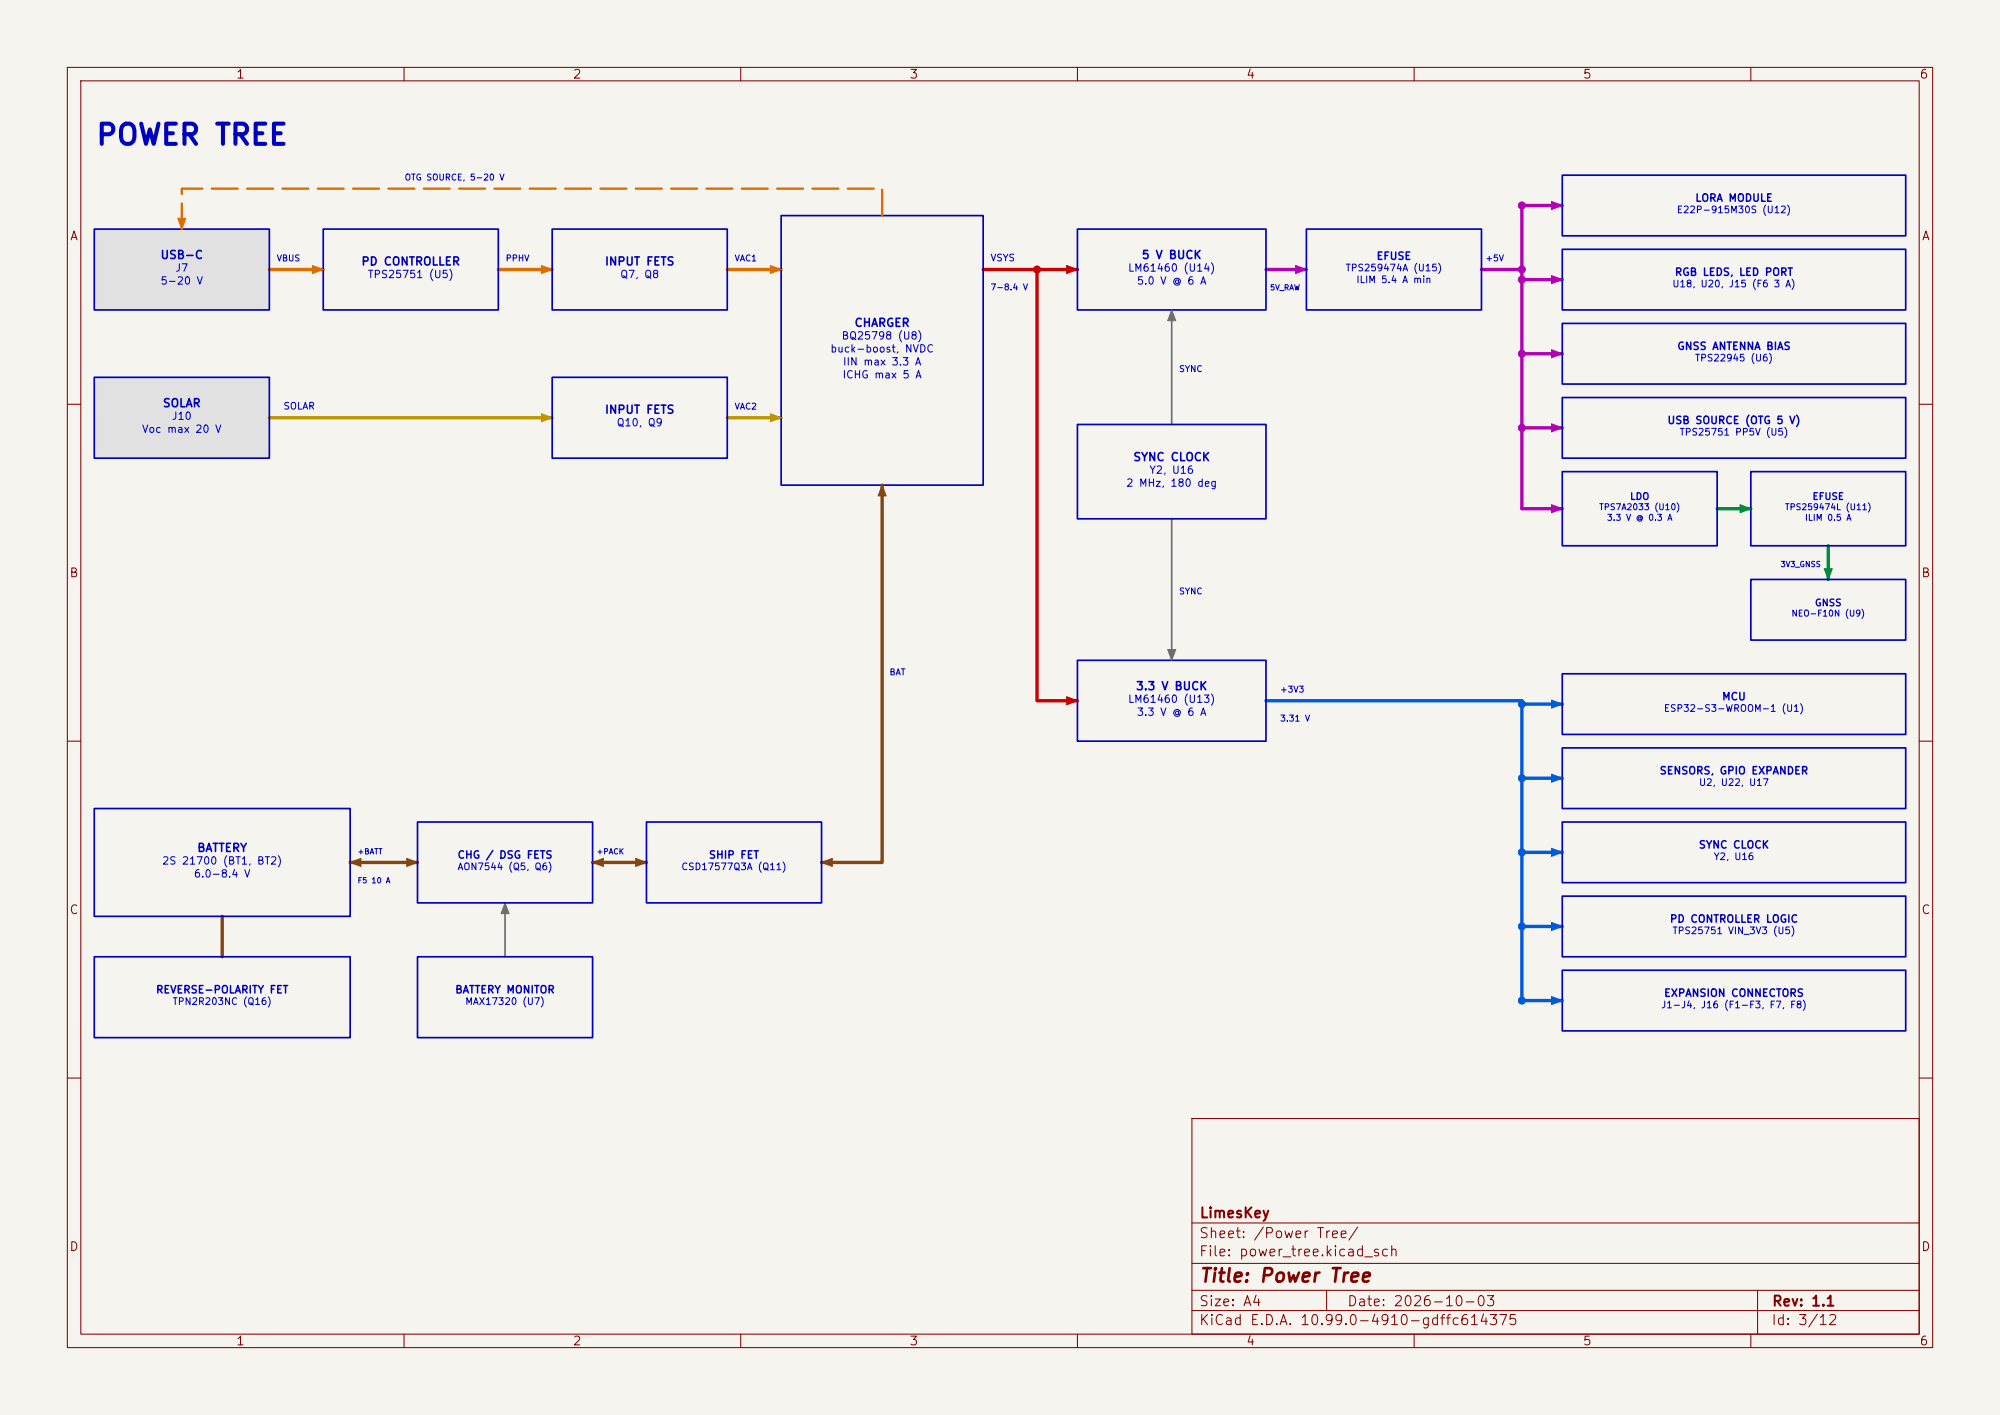
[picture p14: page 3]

Voc max 20 V POWER TREE

E22P-915M30S (U12)TPS259474L (U11) NEO-F10N (U9)
RGB LEDS, LED PORT MCU
ESP32-S3-WROOM-1 (U1) TPS22945 (U6)

GNSS ANTENNA BIAS U18, U20, J15 (F6 3 A) 3.3 V @ 6 A SYNC CLOCK

IIN max 3.3 A CHG / DSG FETS BATTERY MONITOR

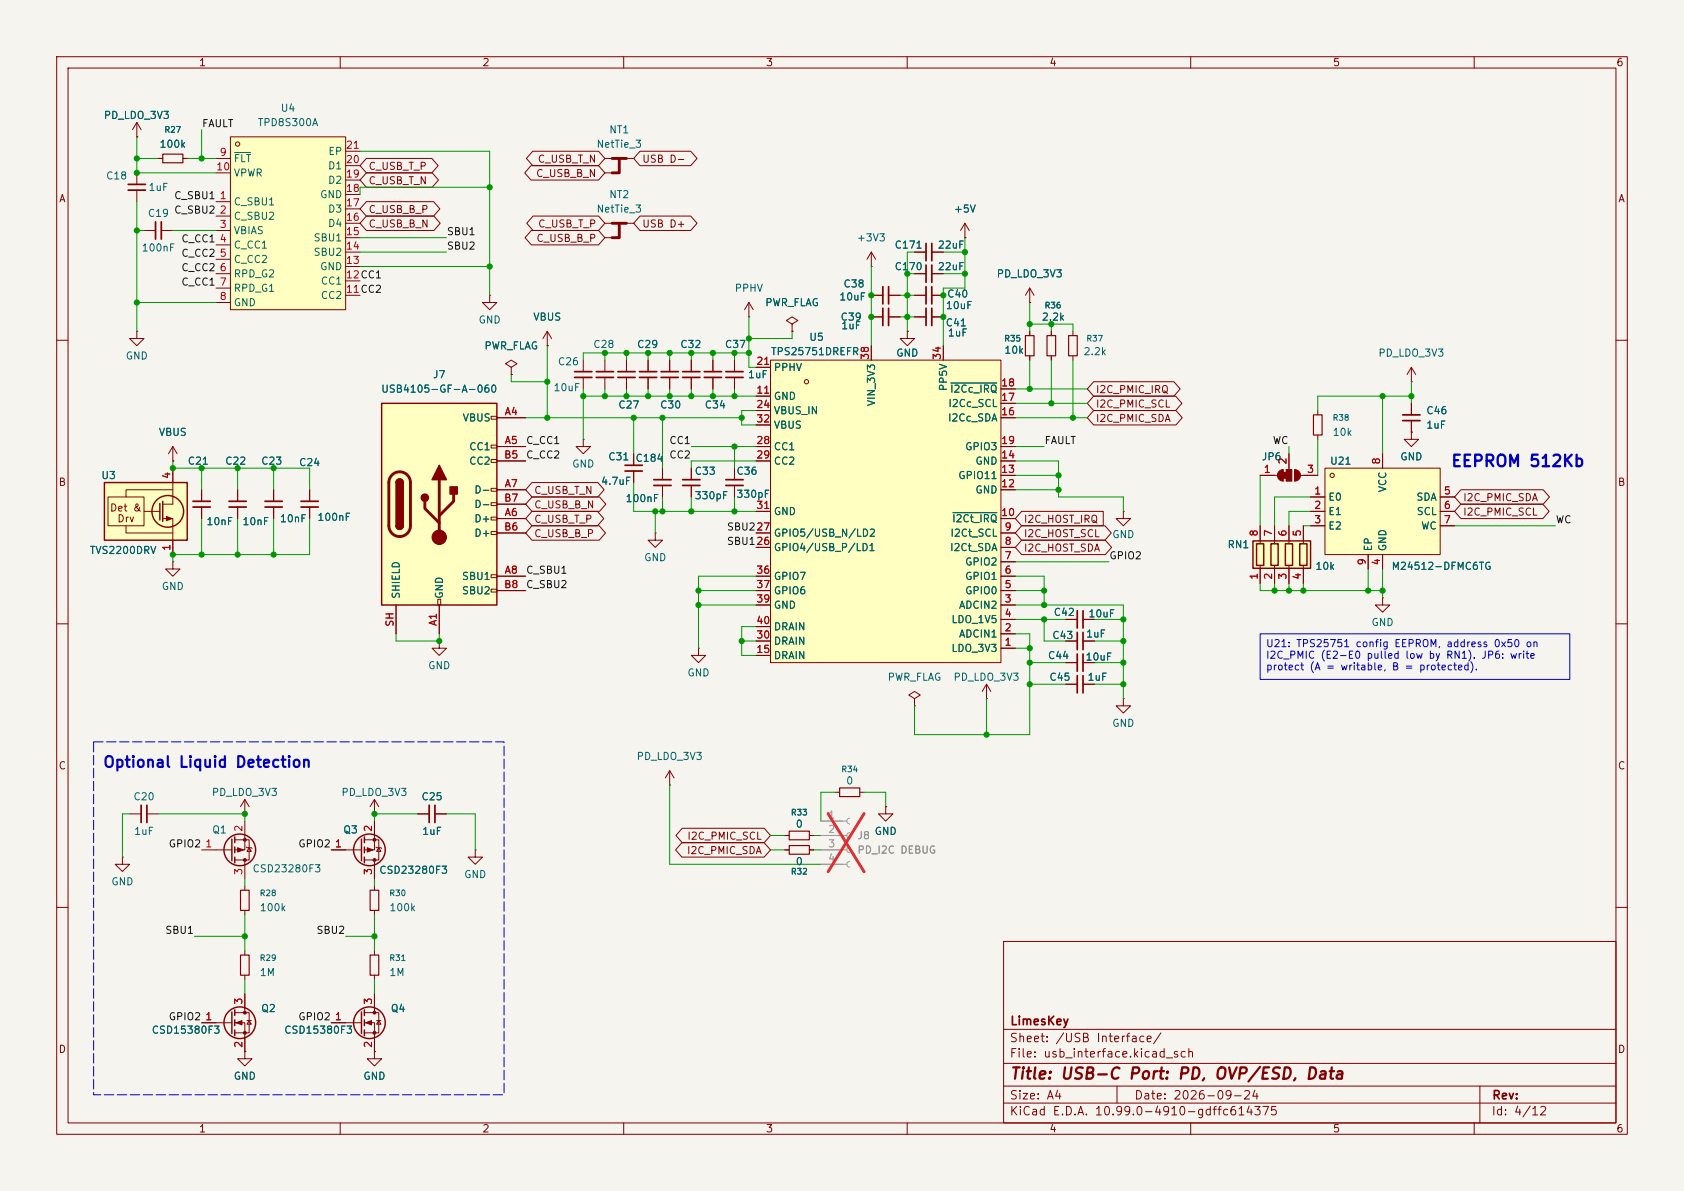
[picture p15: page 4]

I2C_PMIC (E2-E0 pulled low by RN1). JP6: write protect (A = writable, B = protected).

Sheet: /USB Interface/
File: usb_interface.kicad_sch
Title: USB-C Port: PD, OVP/ESD, Data

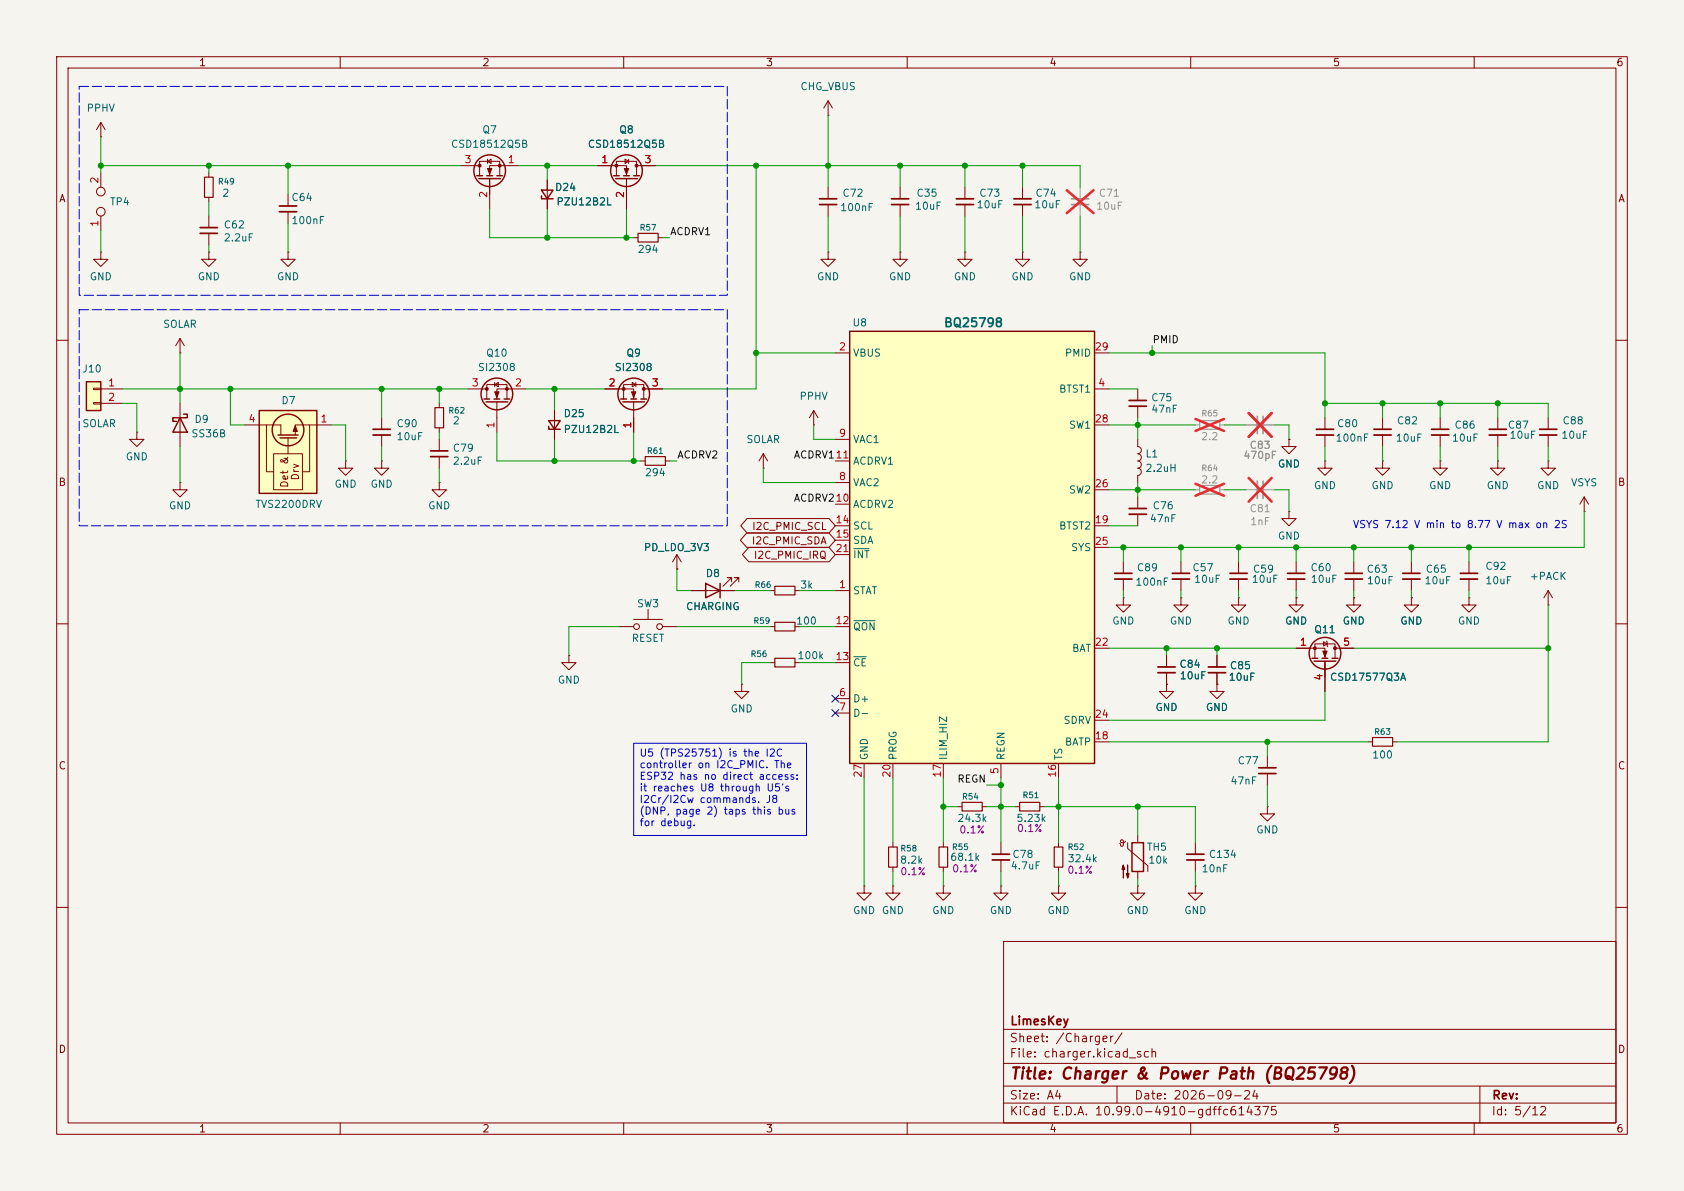
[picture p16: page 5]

SOLAR

2 GND

controller on I2C_PMIC. The ESP32 has no direct access:

it reaches U8 through U5's
I2Cr/I2Cw commands. J8
(DNP, page 2) taps this bus

Sheet: /Charger/
File: charger.kicad_sch
Title: Charger & Power Path (BQ25798)

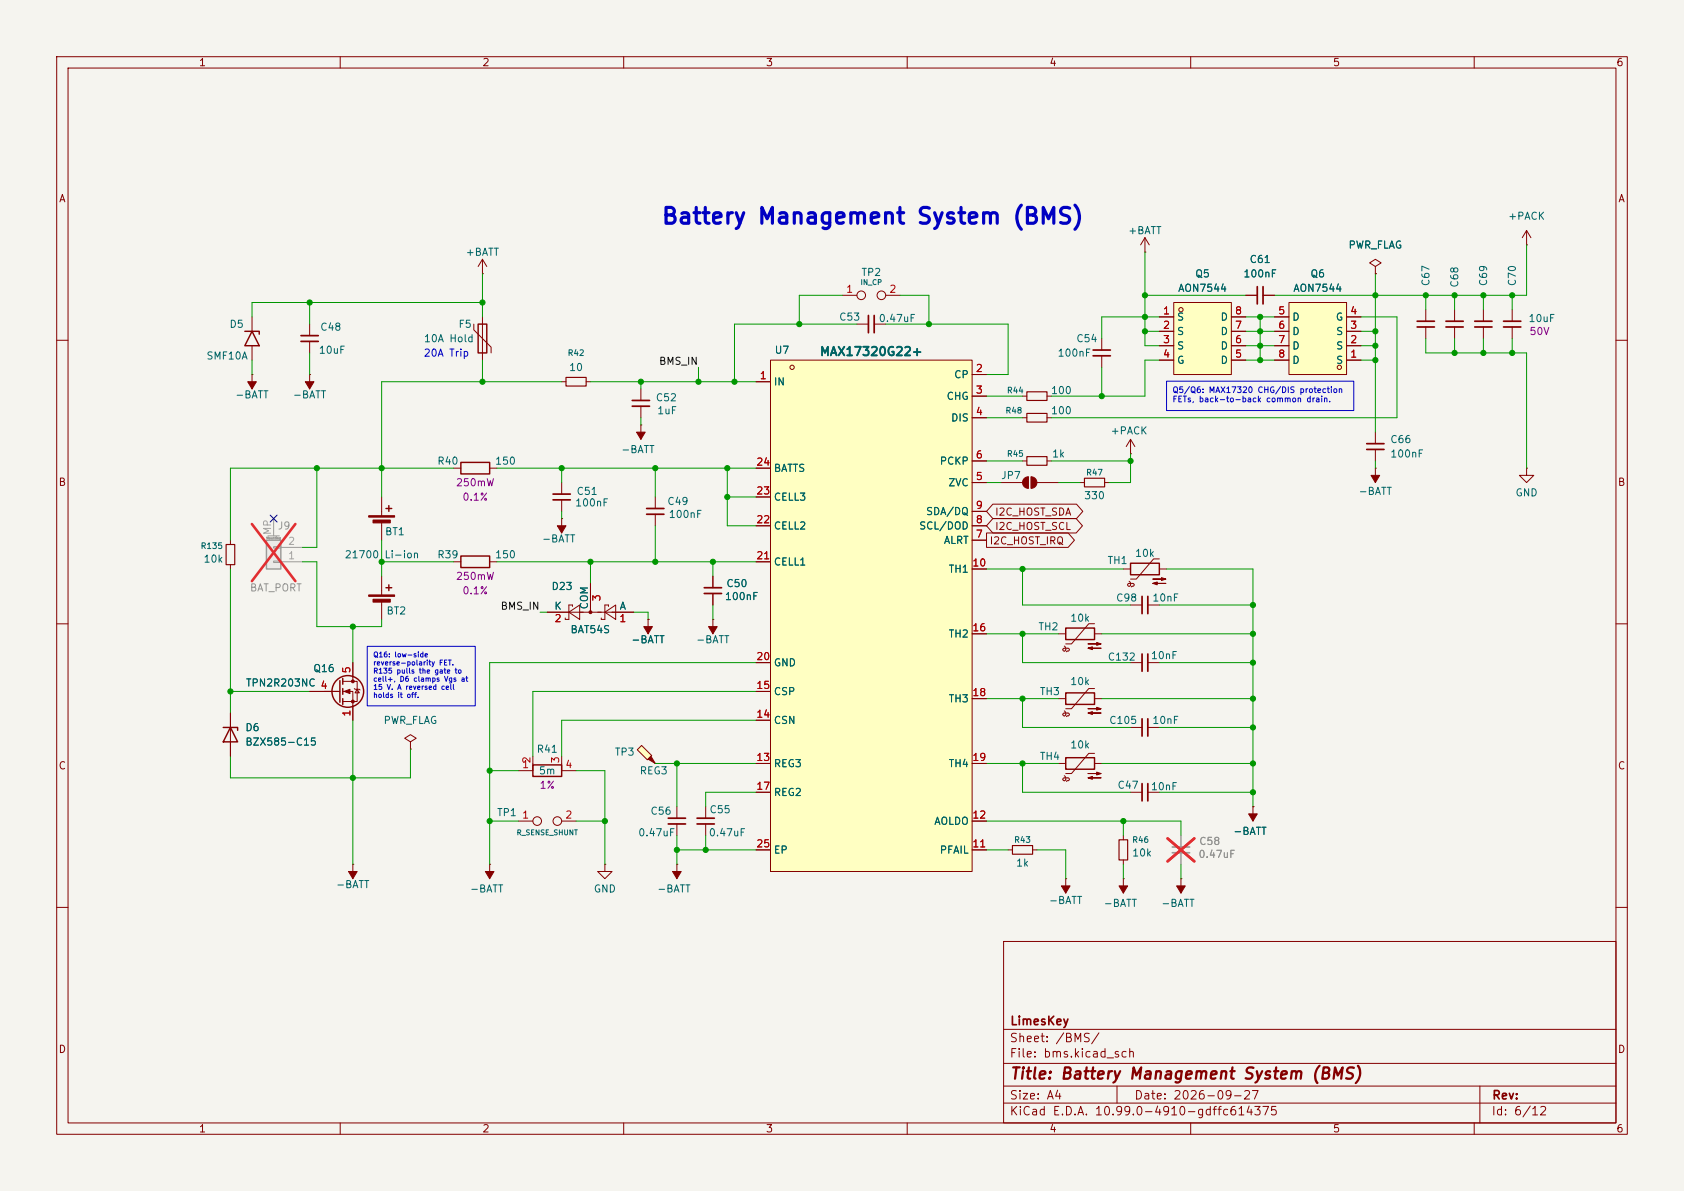
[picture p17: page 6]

Battery Management System (BMS)
cell+, D6 clamps Vgs at 15 V. A reversed cell holds it off. 20A Trip

FETs, back-to-back common drain. Q16: low-side

reverse-polarity FET. R135 pulls the gate to

LimesKey
Sheet: /BMS/
File: bms.kicad_sch
Title: Battery Management System (BMS)

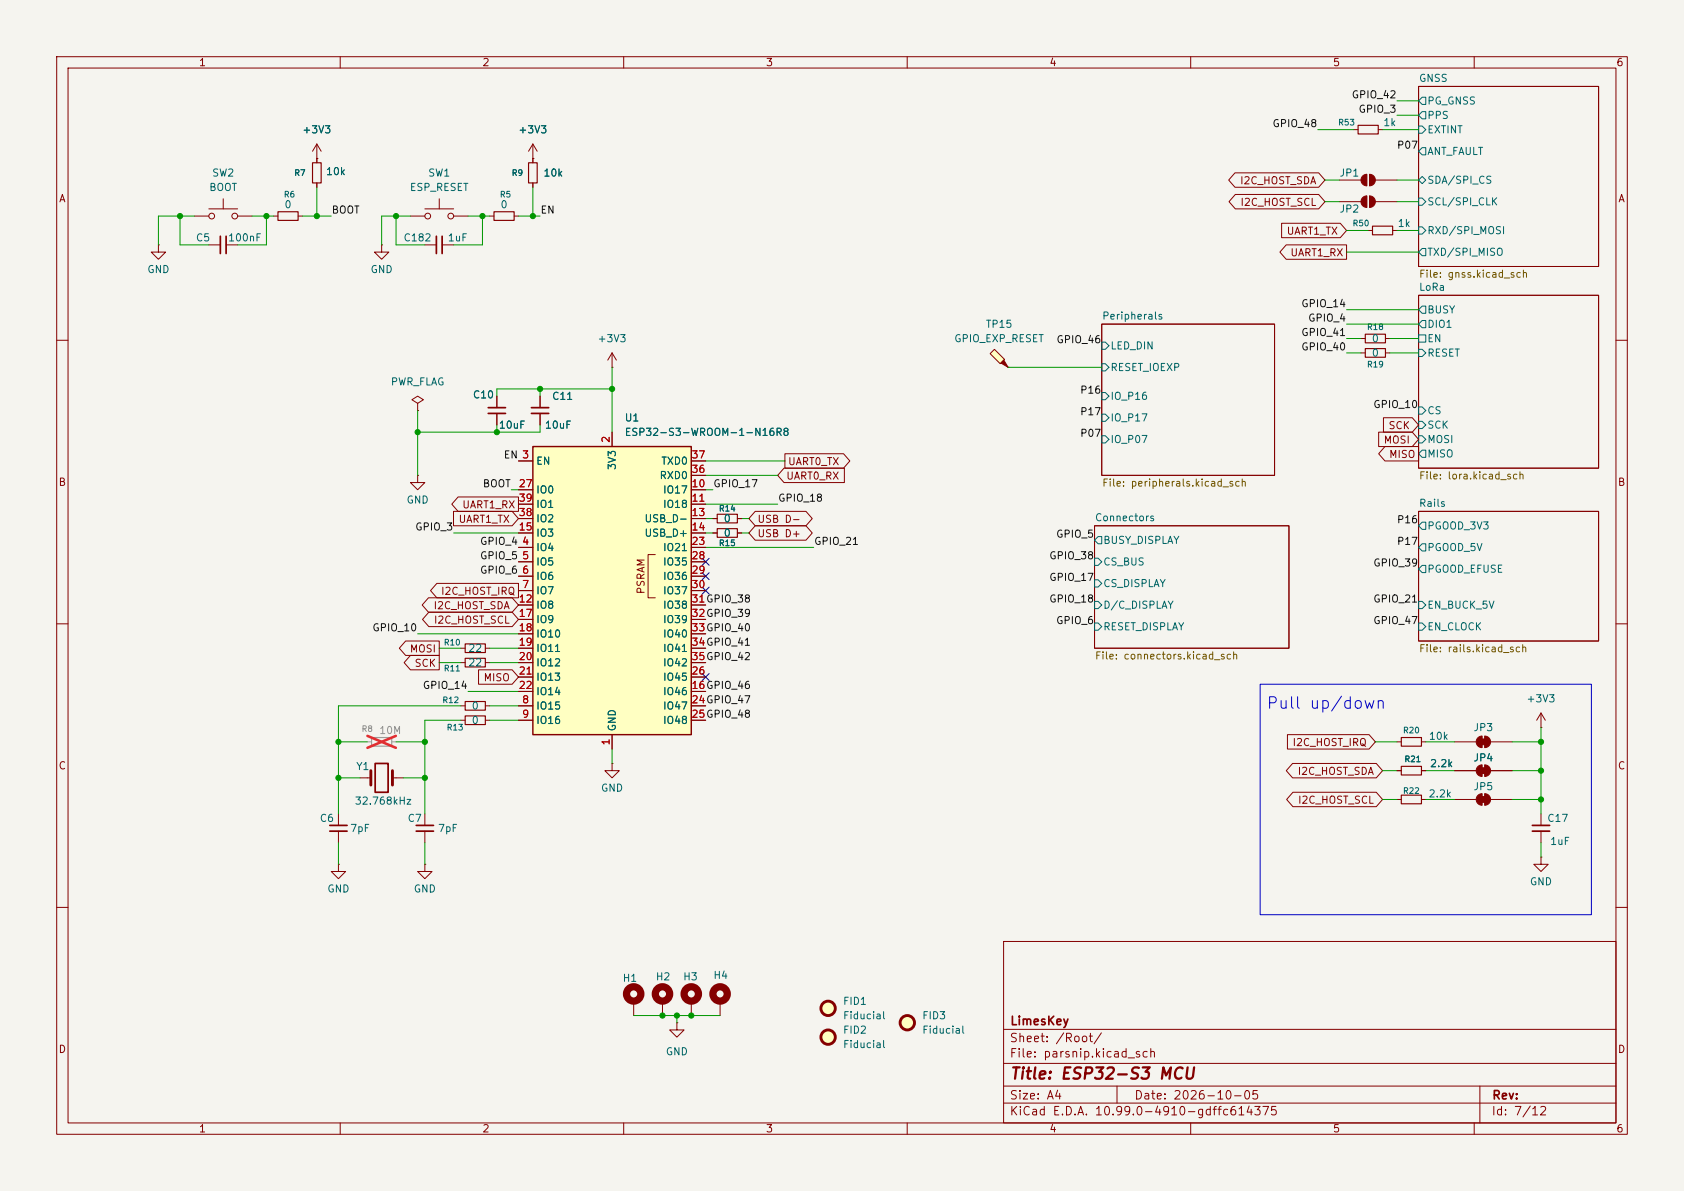
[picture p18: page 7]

File: gnss.kicad_sch
LoRa
ENMISO MOSI RESET SCK

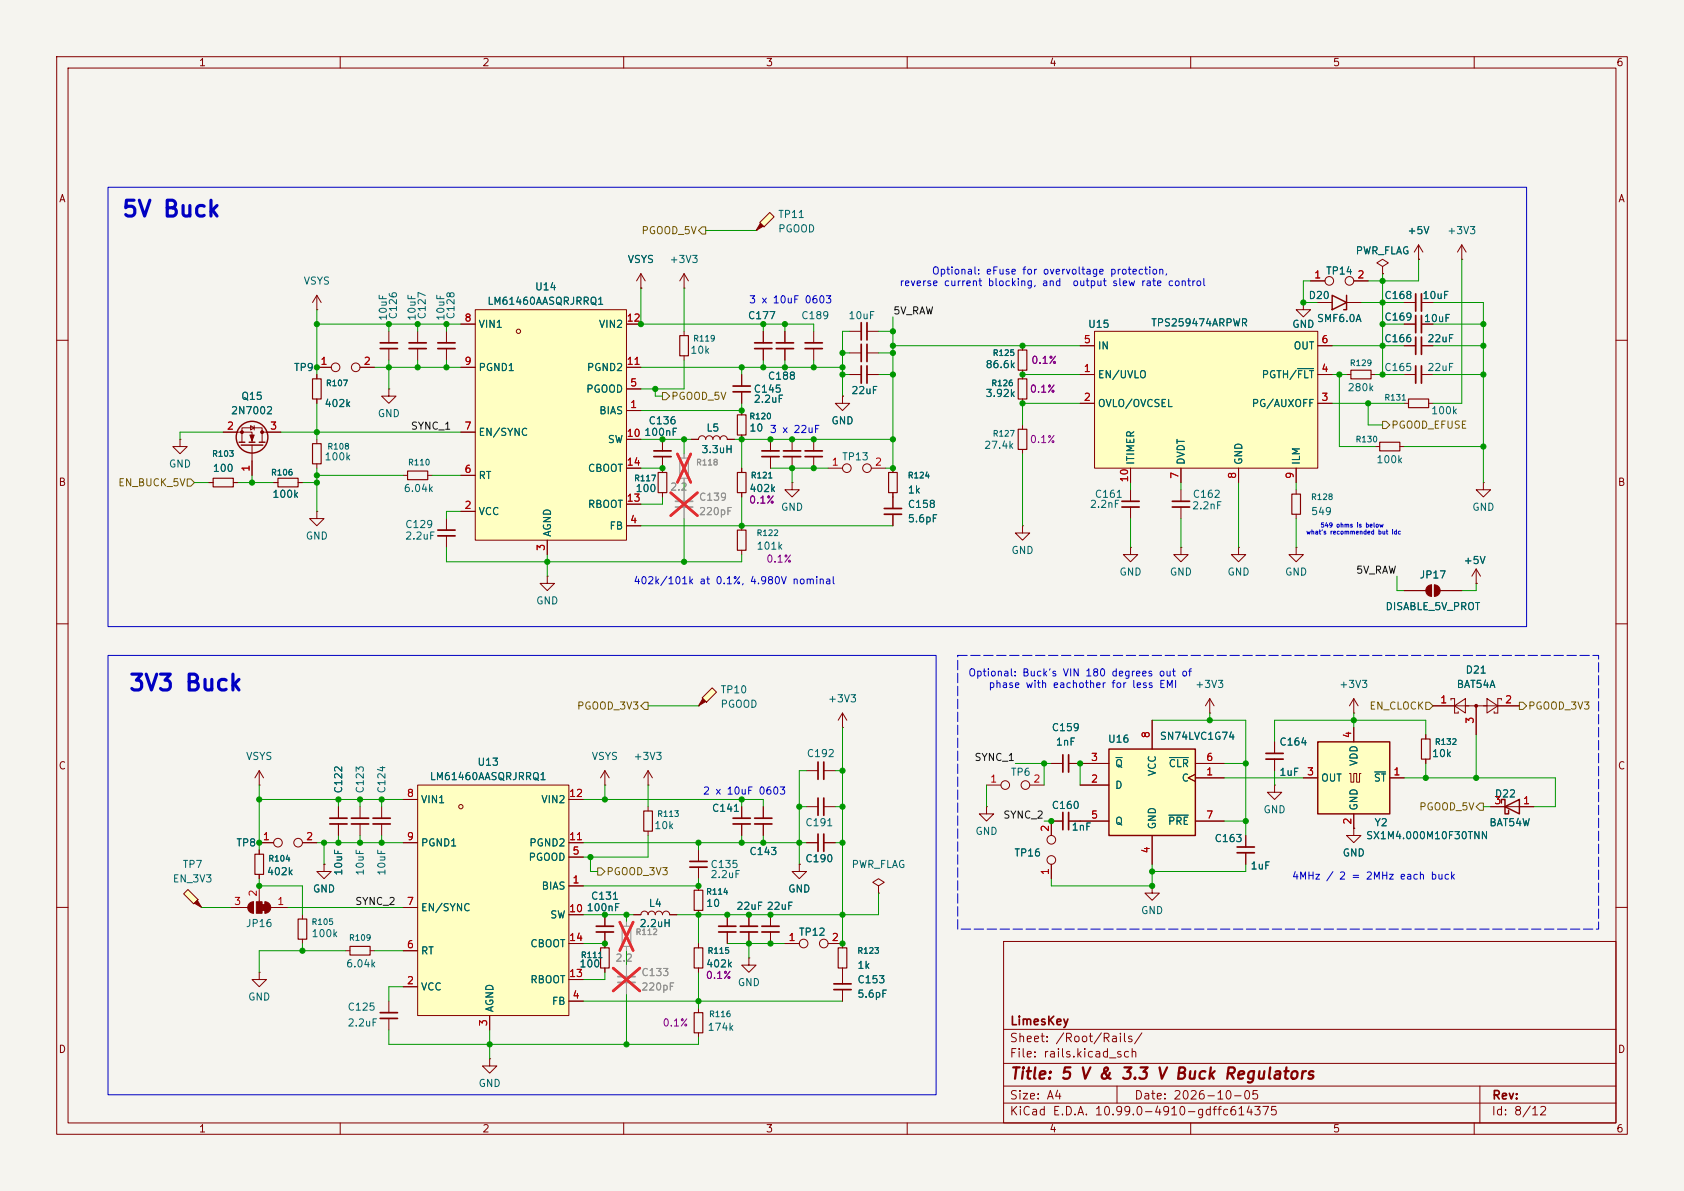
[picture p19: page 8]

549 ohms is below what's recommended but idc 3 x 10uF 0603

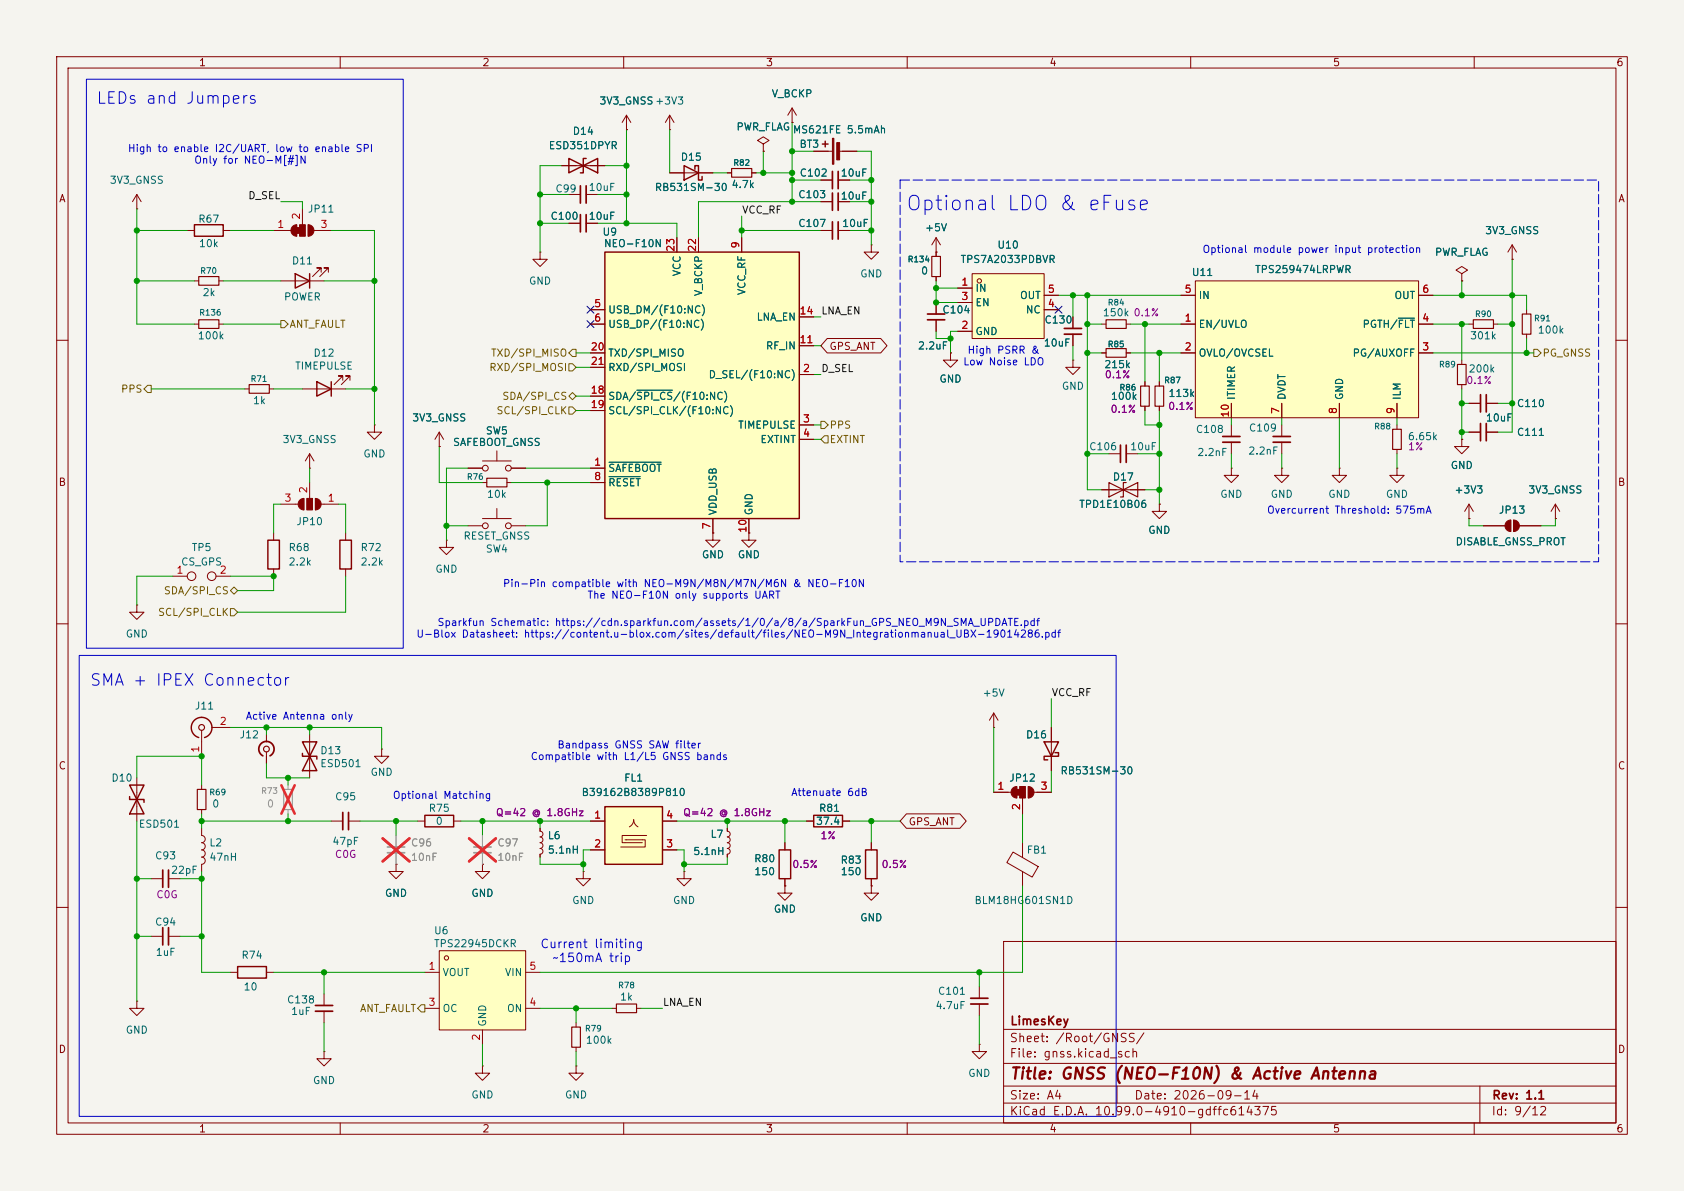
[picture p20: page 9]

High to enable I2C/UART, low to enable SPI Only for NEO-M[#]N
TP5 CS_GPS R67
JP10 D11 POWER

Overcurrent Threshold: 575mA High PSRR &
Low Noise LDO

Pin-Pin compatible with NEO-M9N/M8N/M7N/M6N & NEO-F10N

The NEO-F10N only supports UART Sparkfun Schematic: https://cdn.sparkfun.com/assets/1/0/a/8/a/SparkFun_GPS_NEO_M9N_SMA_UPDATE.pdf U-Blox Datasheet: https://content.u-blox.com/sites/default/files/NEO-M9N_Integrationmanual_UBX-19014286.pdf

Title: GNSS (NEO-F10N) & Active Antenna

Size: A4 | Rev: 1.1

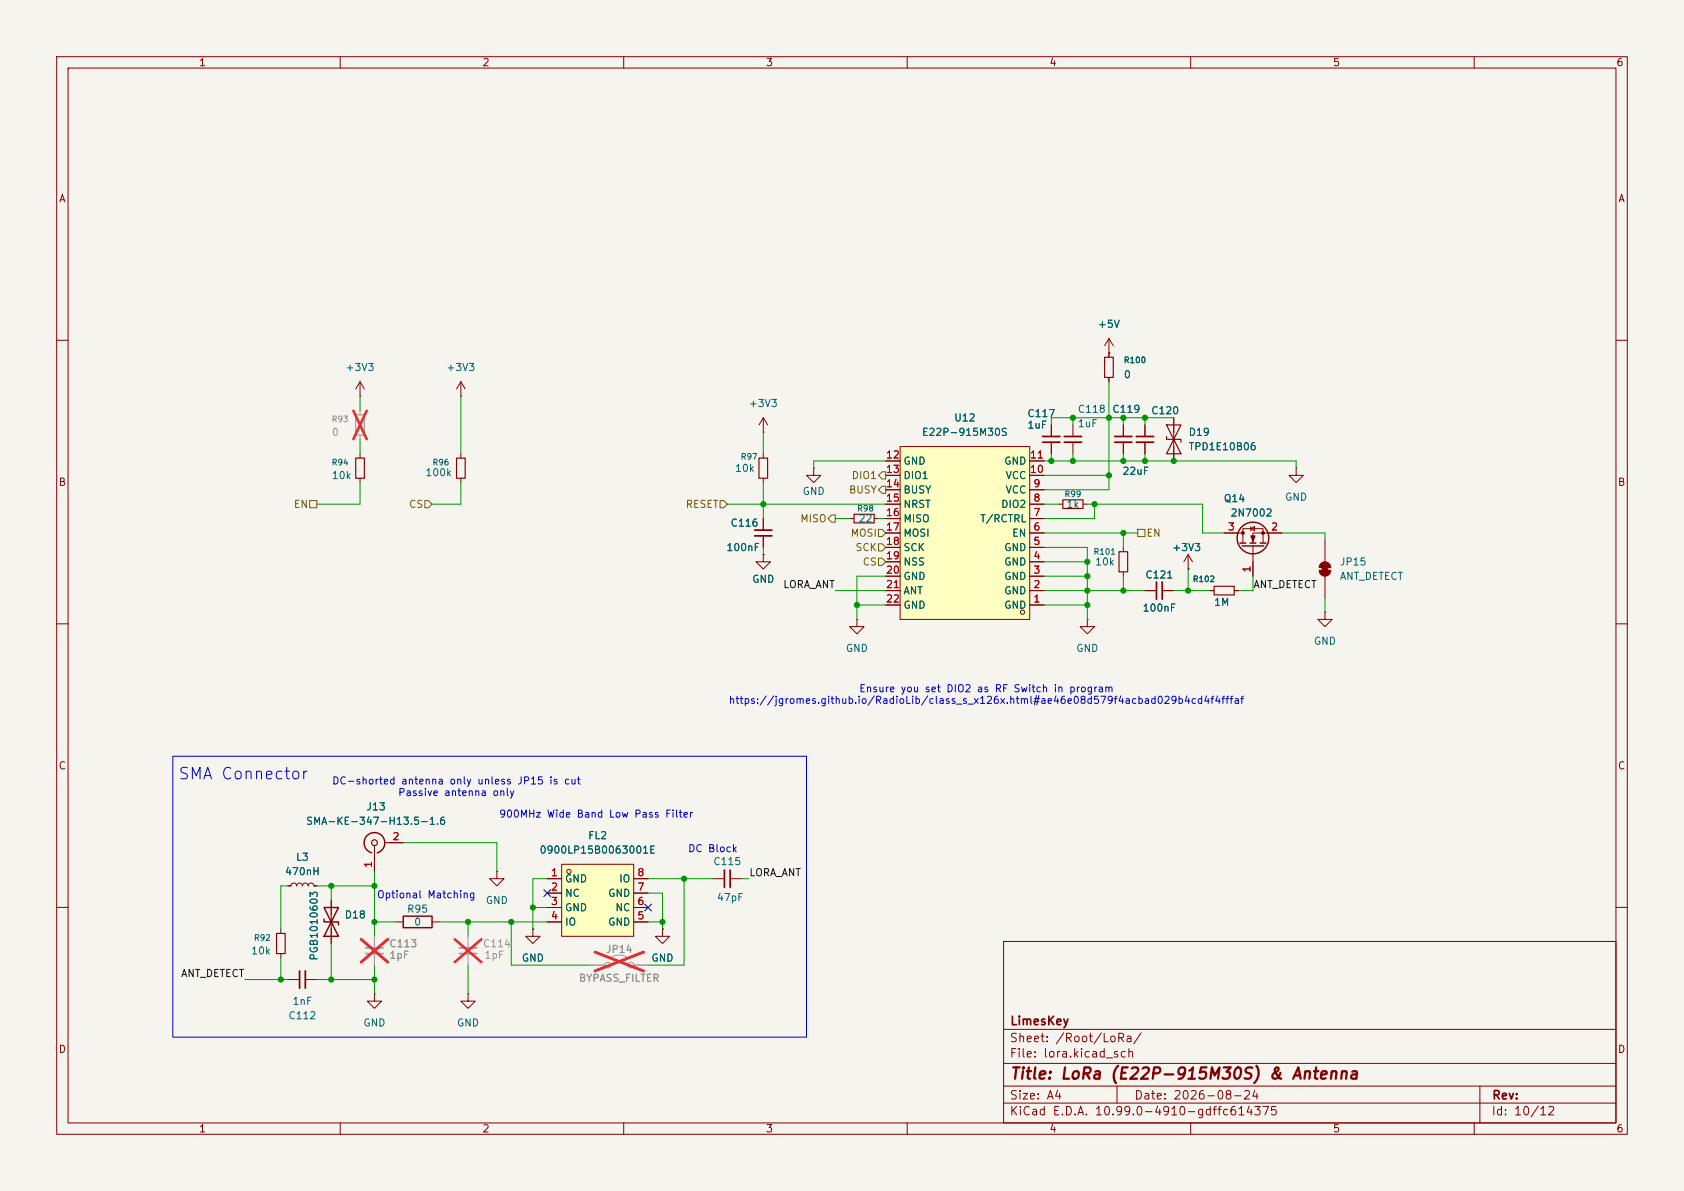
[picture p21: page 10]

VCC 10 GND 11 GND 12 DIO1 13 BUSY 14 NRST 15 MISO 16 MOSI 17

R98 22 GND
https://jgromes.github.io/RadioLib/class_s_x126x.html#ae46e08d579f4acbad029b4cd4f4fffaf C116

Ensure you set DIO2 as RF Switch in program

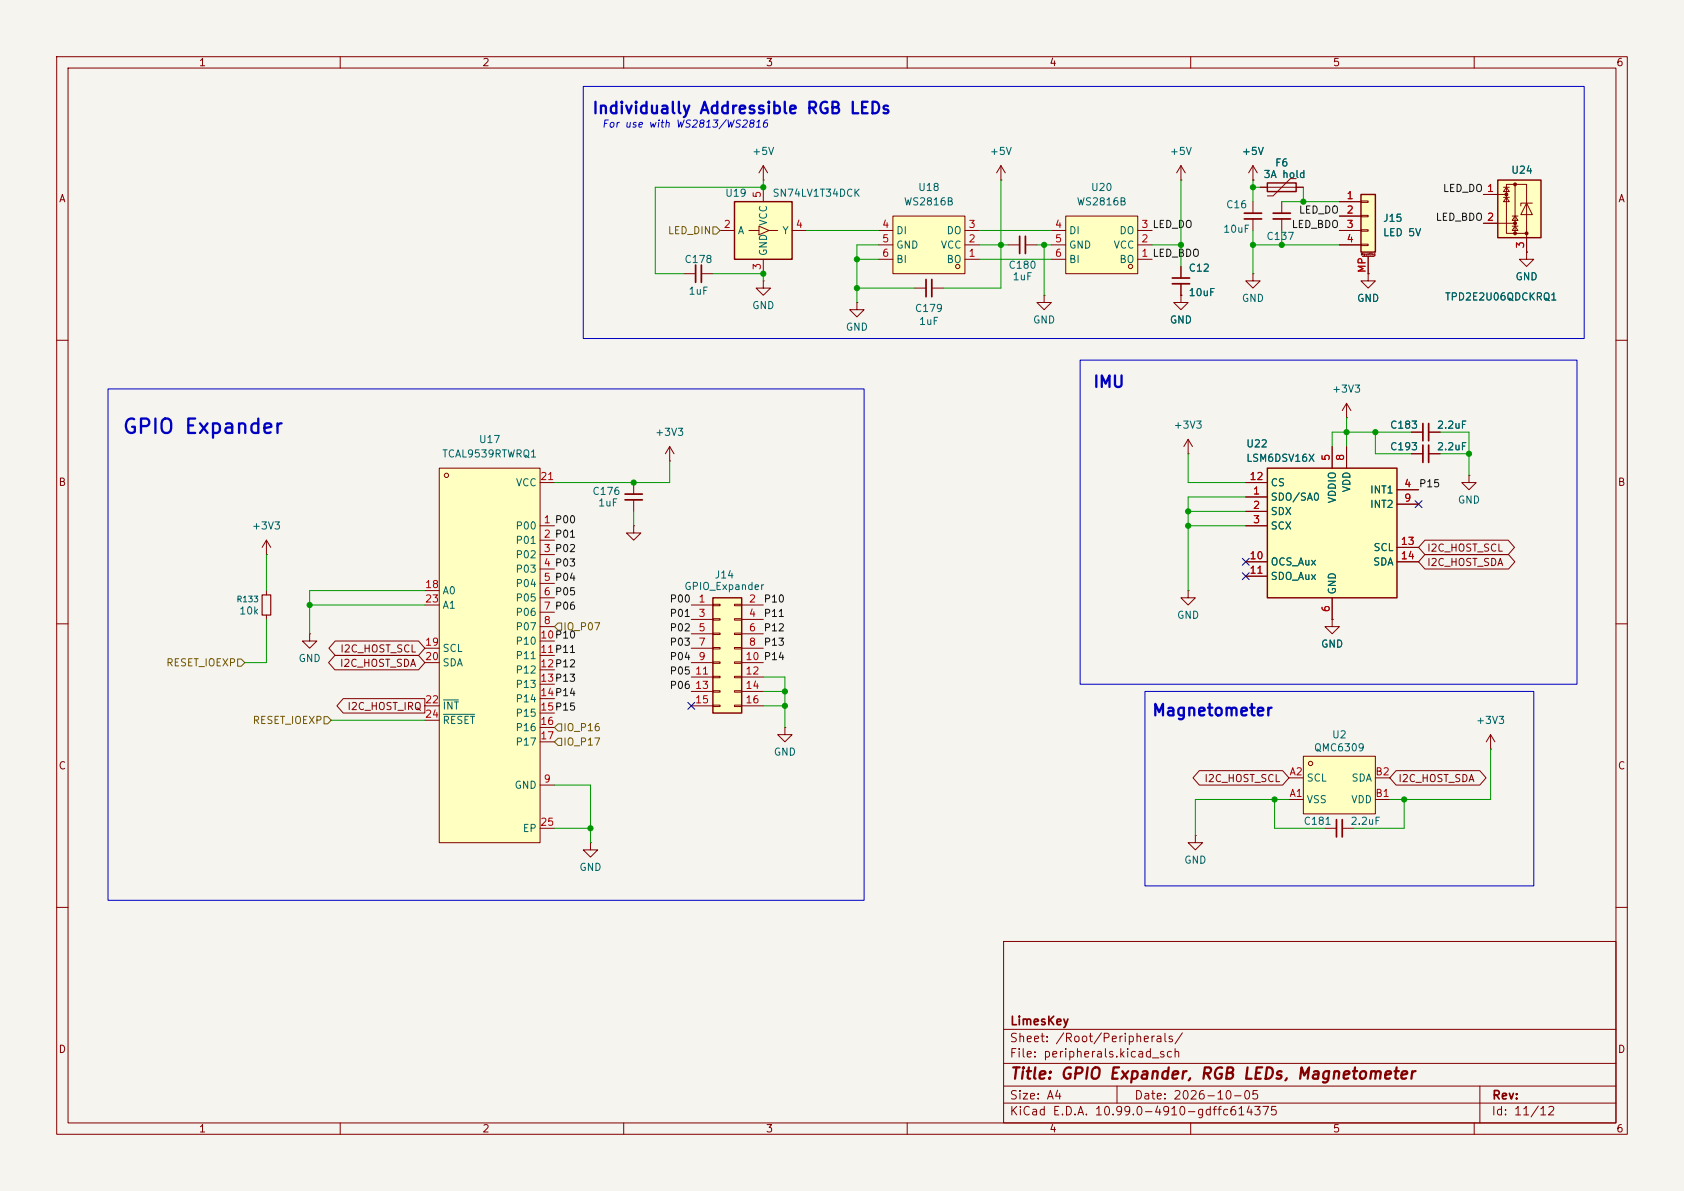
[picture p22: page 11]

Individually Addressible RGB LEDs

LimesKey
Sheet: /Root/Peripherals/
File: peripherals.kicad_sch
Title: GPIO Expander, RGB LEDs, Magnetometer

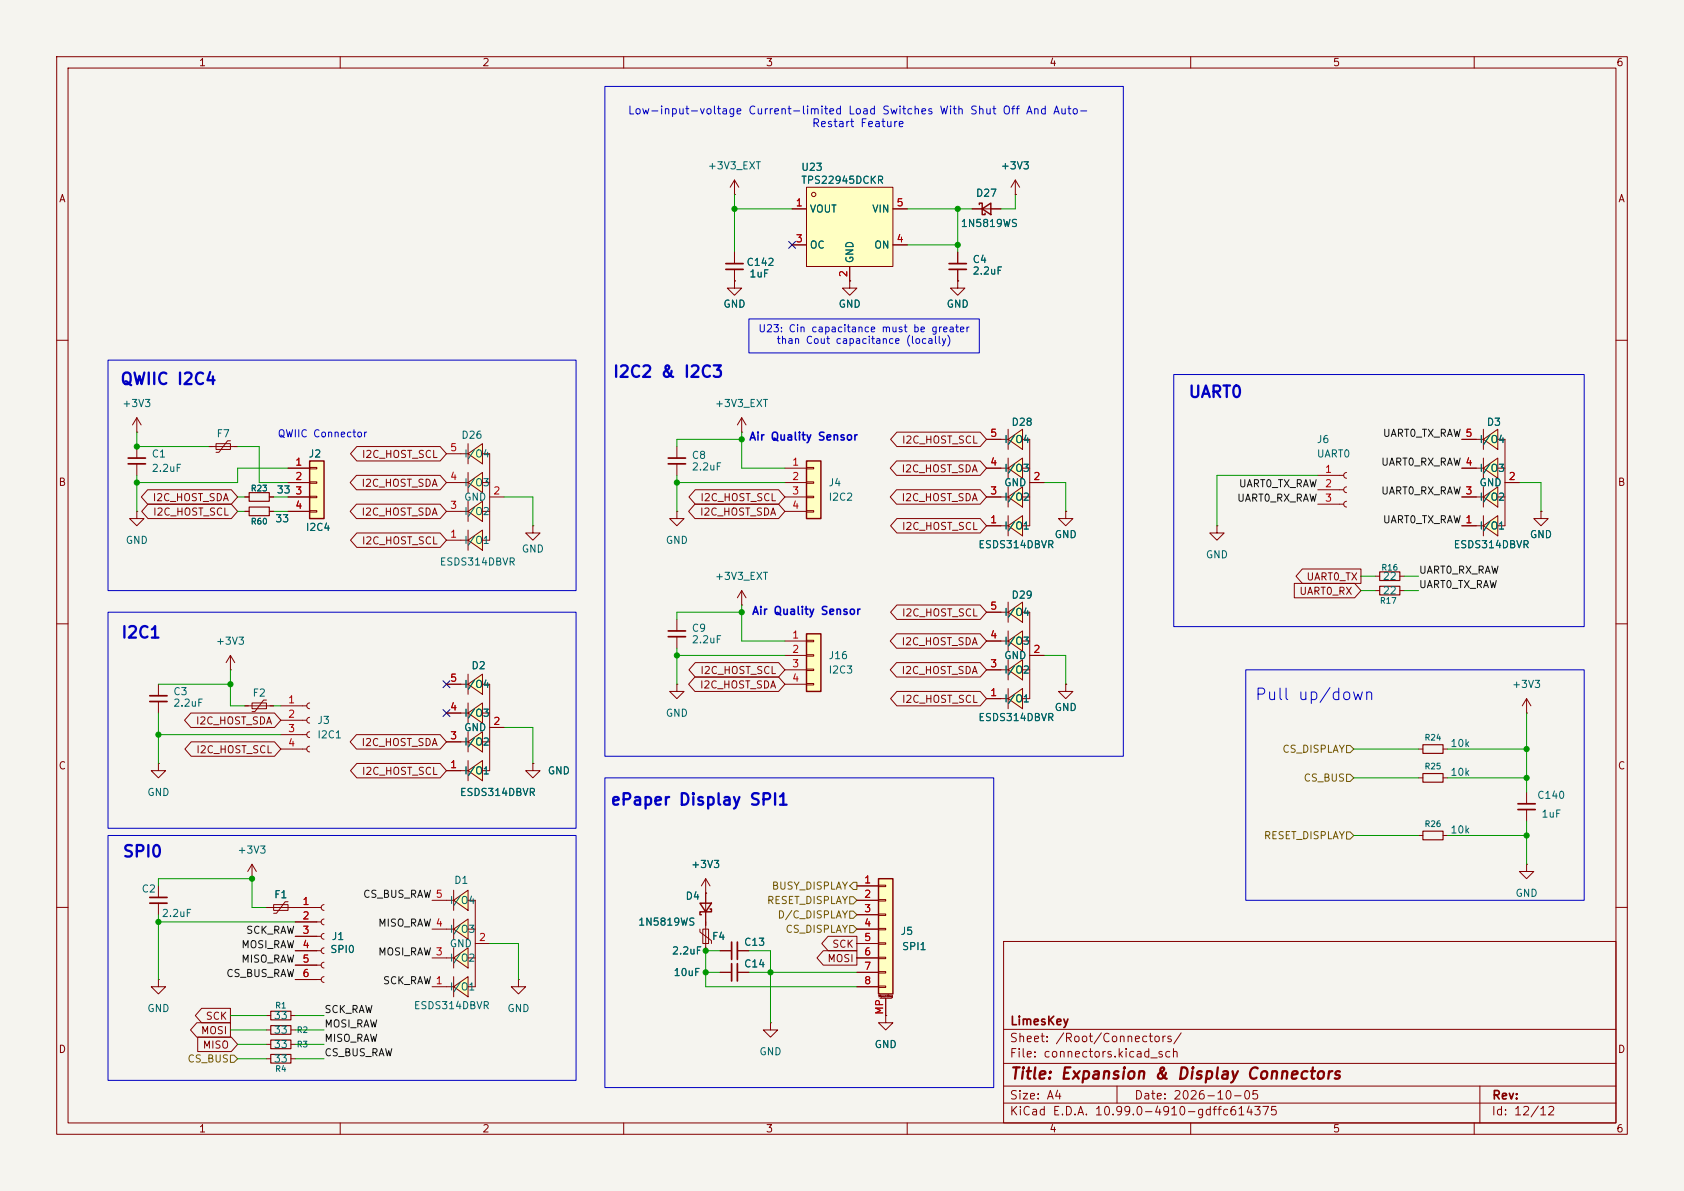
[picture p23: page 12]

Low-input-voltage Current-limited Load Switches With Shut Off And Auto-
I2C3 +3V3_EXT +3V3_EXT GND

U23: Cin capacitance must be greater
than Cout capacitance (locally)

Sheet: /Root/Connectors/
File: connectors.kicad_sch
Title: Expansion & Display Connectors

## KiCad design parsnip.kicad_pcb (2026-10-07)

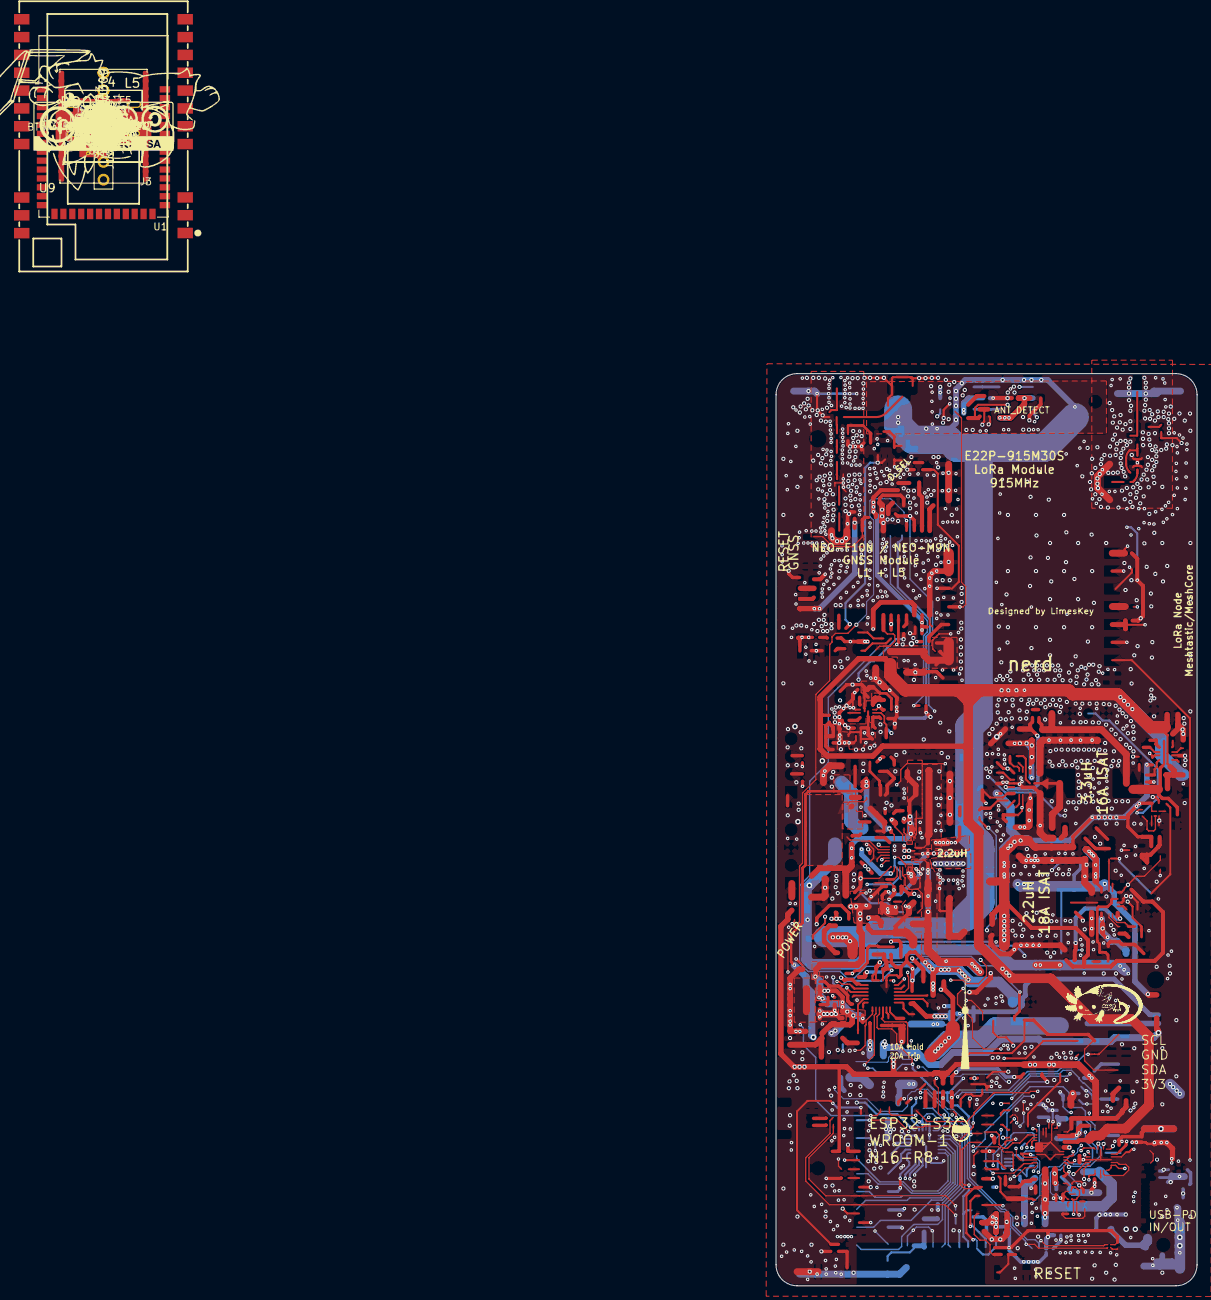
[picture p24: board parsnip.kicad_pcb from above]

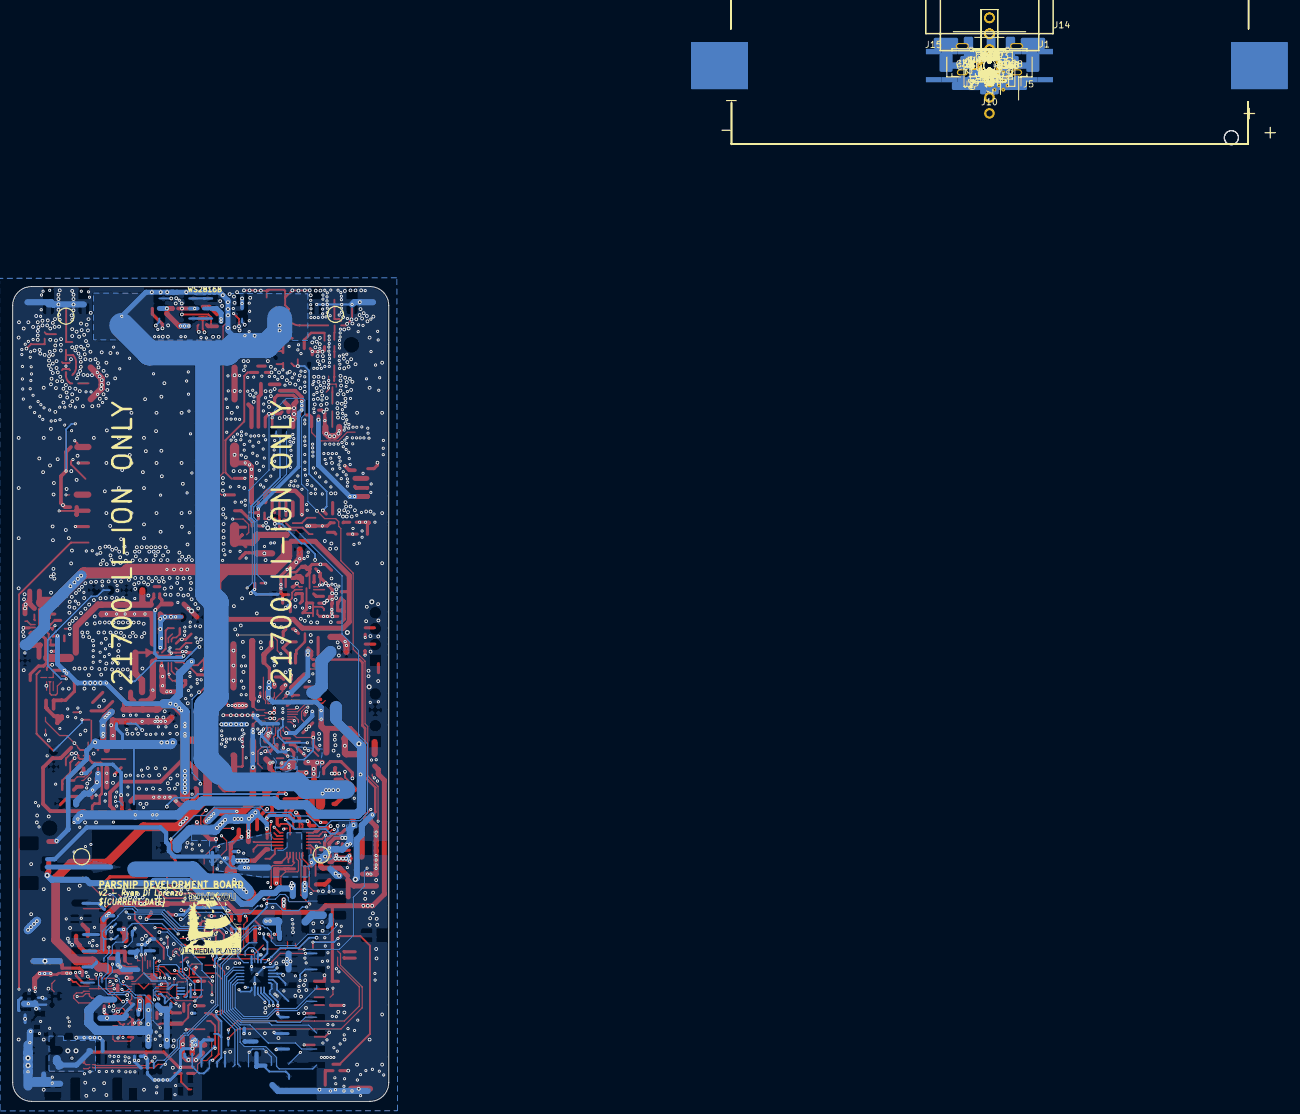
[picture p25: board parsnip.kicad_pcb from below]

Board: 4 copper layers, 60.0 x 130.0 mm, 470 parts (70 on the bottom side), 266 nets.

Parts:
BOYKISSER: LOGO
BT1, BT2: 21700 Li-ion; BAT-SMD_L82.5.5-W25-BH-21700-B1BJ001
BT3: MS621FE 5.5mAh; BatteryHolder_Seiko_MS621F
C1, C2, C3, C4, C8, C9, C13, C104, C181, C183, C193: 2.2uF; C_0402_1005Metric
C5, C19, C24, C49, C50, C51, C54, C61, C64, C66, C72, C80, C89, C116, C121, C131, C136, C184: 100nF; C_0402_1005Metric
C6, C7: 7pF; C_0402_1005Metric
C10, C11, C12, C16, C110, C122, C123, C124, C126, C127, C128, C137, C141, C143, C156, C168, C169, C177, C187, C188, C189, C190, C191, C192: 10uF; C_0603_1608Metric
C14, C38, C40, C42, C44, C48, C67, C68, C69, C70: 10uF; C_0805_2012Metric
C17, C18, C20, C25, C39, C41, C43, C45, C46, C52, C94, C117, C118, C138, C140, C142, C163, C164, C176, C178, C179, C180, C182: 1uF; C_0402_1005Metric
C21, C22, C23, C47, C98, C105, C132, C134: 10nF; C_0402_1005Metric
C26, C27, C28, C29, C30, C32, C34, C35, C57, C59, C60, C63, C65, C71, C73, C74, C82, C84, C85, C86, C87, C88, C90, C92: 10uF; C_1206_3216Metric
C31: 4.7uF; C_0805_2012Metric
C33, C36: 330pF; C_0402_1005Metric
C37: 1uF; C_0603_1608Metric
C53, C55, C56, C58: 0.47uF; C_0402_1005Metric
C62, C79: 2.2uF; C_0805_2012Metric
C75, C76, C77: 47nF; C_0402_1005Metric
C78: 4.7uF; C_0603_1608Metric
C81: 1nF; C_0402_1005Metric_Pad0.74x0.62mm_HandSolder
C83: 470pF; C_0402_1005Metric_Pad0.74x0.62mm_HandSolder
C93: 22pF; C_0402_1005Metric
C95, C115: 47pF; C_0402_1005Metric
C96, C97: 10nF; C_0402_1005Metric_Pad0.74x0.62mm_HandSolder
C99, C100, C102, C103, C106, C107, C111, C130: 10uF; C_0402_1005Metric
C101: 4.7uF; C_0402_1005Metric
C108, C109, C161, C162: 2.2nF; C_0402_1005Metric
C112, C159, C160: 1nF; C_0402_1005Metric
C113, C114: 1pF; C_0402_1005Metric_Pad0.74x0.62mm_HandSolder
C119, C120: 22uF; C_1206_3216Metric
C125, C129, C135, C145: 2.2uF; C_0603_1608Metric
C133, C139: 220pF; C_0402_1005Metric_Pad0.74x0.62mm_HandSolder
C144, C147, C185: 22uF; C_0805_2012Metric
C153, C158: 5.6pF; C_0402_1005Metric_Pad0.74x0.62mm_HandSolder
C155, C157, C165, C166, C167, C170, C171, C186: 22uF; C_0603_1608Metric
D1, D2, D3, D26, D28, D29: ESDS314DBVR; SOT-23-5
D4, D27: 1N5819WS; D_SOD-323
D5: SMF10A; D_SOD-123
D6: BZX585-C15; D_SOD-523
D7: TVS2200DRV; WSON-6-1EP_2x2mm_P0.65mm_EP1x1.6mm
D8: CHARGING; LED_0805_2012Metric
D9: SS36B; D_SMB
D10, D13: ESD501; Texas_DPY0002A_0.6x1mm_P0.65mm
D11: POWER; LED_0805_2012Metric
D12: TIMEPULSE; LED_0805_2012Metric
D14: ESD351DPYR; Texas_DPY0002A_0.6x1mm_P0.65mm
D15, D16: RB531SM-30; D_SOD-523
D17, D19: TPD1E10B06; Texas_DPY0002A_0.6x1mm_P0.65mm
D18: PGB1010603; D_0603_1608Metric_Pad1.05x0.95mm_HandSolder
D20: SMF6.0A; D_SOD-123F
D21: BAT54A; SOT-23
D22: BAT54W; SOT-323_SC-70
D23: BAT54S; SOT-23
D24, D25: PZU12B2L; D_SOD-882
F1, F7: 1A hold; Fuse_0805_2012Metric
F2: 2A hold; Fuse_0805_2012Metric
F4: 350mA hold; Fuse_0805_2012Metric
F5: 10A Hold; Fuse_2920_7451Metric
F6: 3A hold; Fuse_1812_4532Metric
FB1: BLM18HG601SN1D; L_0603_1608Metric
FID1, FID2, FID3: Fiducial; Fiducial_1mm_Mask2mm
FL1: B39162B8389P810; Filter_1411-5_1.4x1.1mm
FL2: 0900LP15B0063001E; FILTER-SMD_0805-8P-L2.0-W1.2-TL
H1, H2, H3, H4: MountingHole_Pad; MountingHole_2.2mm_M2_DIN965_Pad
J1: SPI0; HDR-SMD_6P-P2.54-H-F-W11.7
J2: I2C4; JST_SH_SM04B-SRSS-TB_1x04-1MP_P1.00mm_Horizontal
J3: I2C1; CONN-SMD_4P-P2.54_HX-PM2.54-1X4PWT
J4: I2C2; PinSocket_1x04_P2.54mm_Vertical
J5: SPI1; Molex_PicoBlade_53261-0871_1x08-1MP_P1.25mm_Horizontal
J6: UART0; JST_SH_SM03B-SRSS-TB_1x03-1MP_P1.00mm_Horizontal
J7: USB4105-GF-A-060; USB_C_Receptacle_GCT_USB4105-xx-A_16P_TopMnt_Horizontal
J8: PD_I2C DEBUG; PinSocket_1x04_P2.54mm_Vertical
J9: BAT_PORT; Molex_PicoBlade_53261-0271_1x02-1MP_P1.25mm_Horizontal
J10: SOLAR; JST_PH_S2B-PH-SM4-TB_1x02-1MP_P2.00mm_Horizontal
J11, J13: SMA-KE-347-H13.5-1.6; SMA_Samtec_SMA-J-P-H-ST-EM1_EdgeMount
J12: U.FL; U.FL_Hirose_U.FL-R-SMT-1_Vertical
J14: GPIO_Expander; HDR-SMD_16P-P2.54_HXPM2.54-2X8PWT
J15: LED 5V; JST_XH_S4B-XH-SM4-TB_1x04-1MP_P2.50mm_Horizontal
J16: I2C3; PinSocket_1x04_P2.54mm_Vertical
JP1, JP2: SolderJumper_2_Open; SolderJumper-2_P1.3mm_Open_TrianglePad1.0x1.5mm
JP3: I2C_IRQ_PULLUP; SolderJumper-2_P1.3mm_Bridged_RoundedPad1.0x1.5mm
JP4: I2C_SDA_PULLUP; SolderJumper-2_P1.3mm_Bridged_RoundedPad1.0x1.5mm
JP5: I2C_SCL_PULLUP; SolderJumper-2_P1.3mm_Bridged_RoundedPad1.0x1.5mm
JP6: WRITE_PROTECT; SolderJumper-3_P1.3mm_Bridged12_RoundedPad1.0x1.5mm_NumberL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
JP7: ZVC; SolderJumper-2_P1.3mm_Open_RoundedPad1.0x1.5mm
JP10: SolderJumper_3_Open; SolderJumper-3_P1.3mm_Open_RoundedPad1.0x1.5mm_NumberLabels
JP11: I2C/UART/SPI; SolderJumper-3_P1.3mm_Bridged12_RoundedPad1.0x1.5mm
JP12, JP16: SolderJumper_3_Bridged12; SolderJumper-3_P1.3mm_Bridged12_RoundedPad1.0x1.5mm_NumberL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
JP13: DISABLE_GNSS_PROT; SolderJumper-2_P1.3mm_Open_RoundedPad1.0x1.5mm
JP14: BYPASS_FILTER; R_0402_1005Metric
JP15: ANT_DETECT; SolderJumper-2_P1.3mm_Bridged_RoundedPad1.0x1.5mm
JP17: DISABLE_5V_PROT; SolderJumper-2_P1.3mm_Open_RoundedPad1.0x1.5mm
L1: 2.2uH; L_Sunlord_MWSA0603S
L2: 47nH; L_0603_1608Metric
L3: 470nH; L_0603_1608Metric
L4: 2.2uH; L_APV_APH1040
L5: 3.3uH; L_APV_APH1040
L6, L7: 5.1nH; L_0402_1005Metric
NT1, NT2: NetTie_3; NetTie-3_SMD_Pad0.5mm
Q1, Q3: CSD23280F3; Texas_PicoStar_DFN-3_0.69x0.60mm
Q2, Q4: CSD15380F3; Texas_PicoStar_DFN-3_0.69x0.60mm
Q5, Q6: AON7544; PQFN-8_L3.1-W3.1-P0.65-LS3.3-BL
Q7, Q8: CSD18512Q5B; VSONP-8-1EP_5x6_P1.27mm
Q9, Q10: SI2308; SOT-23
Q11: CSD17577Q3A; VSON-8_3.3x3.3mm_P0.65mm_NexFET
Q14, Q15: 2N7002; SOT-23
Q16: TPN2R203NC; TSON-8_L3.1-W3.1-P0.65-LS3.3-BL-EP
R1, R2, R3, R4, R23, R60: 33; R_0402_1005Metric_Pad0.72x0.64mm_HandSolder
R5, R6, R12, R13, R14, R15, R18, R19, R32, R33, R34, R69, R73, R93, R134: 0; R_0402_1005Metric
R7, R9, R35, R38, R46, R67, R76, R92, R94, R101, R113, R119, R132, R135: 10k; R_0402_1005Metric
R8: 10M; R_0805_2012Metric
R10, R11: 22; R_0402_1005Metric_Pad0.72x0.64mm_HandSolder
R16, R17, R98: 22; R_0402_1005Metric
R20, R24, R25, R26, R133: 10k; R_0402_1005Metric_Pad0.72x0.64mm_HandSolder
R21, R22, R68, R72: 2.2k; R_0402_1005Metric_Pad0.72x0.64mm_HandSolder
R27, R28, R30, R56, R79, R86, R91, R96, R105, R106, R108, R130, R131, R136: 100k; R_0402_1005Metric
R29, R31, R102: 1M; R_0402_1005Metric
R36, R37: 2.2k; R_0402_1005Metric
R39, R40: 150; R_1206_3216Metric
R41: 5m; R_Shunt_0805_2012Metric_Kelvin
R42, R120: 10; R_0402_1005Metric
R43, R45, R50, R53, R71, R78, R99: 1k; R_0402_1005Metric
R44, R48, R59, R63, R103: 100; R_0402_1005Metric
R47: 330; R_1210_3225Metric
R49, R62: 2; R_0402_1005Metric
R51: 5.23k; R_0603_1608Metric_Pad0.98x0.95mm_HandSolder
R52: 32.4k; R_0603_1608Metric_Pad0.98x0.95mm_HandSolder
R54: 24.3k; R_0603_1608Metric_Pad0.98x0.95mm_HandSolder
R55: 68.1k; R_0603_1608Metric_Pad0.98x0.95mm_HandSolder
R57, R61: 294; R_0402_1005Metric
R58: 8.2k; R_0402_1005Metric_Pad0.72x0.64mm_HandSolder
R64, R65: 2.2; R_0402_1005Metric_Pad0.72x0.64mm_HandSolder
R66: 3k; R_0402_1005Metric_Pad0.72x0.64mm_HandSolder
R70: 2k; R_0402_1005Metric
R74: 10; R_0603_1608Metric_Pad0.98x0.95mm_HandSolder
R75, R95: 0; R_0402_1005Metric_Pad0.72x0.64mm_HandSolder
R80, R83: 150; R_0402_1005Metric_Pad0.72x0.64mm_HandSolder
R81: 37.4; R_0402_1005Metric_Pad0.72x0.64mm_HandSolder
R82: 4.7k; R_0402_1005Metric
R84: 150k; R_0402_1005Metric
R85: 215k; R_0603_1608Metric_Pad0.98x0.95mm_HandSolder
R87: 113k; R_0402_1005Metric_Pad0.72x0.64mm_HandSolder
R88: 6.65k; R_0402_1005Metric_Pad0.72x0.64mm_HandSolder
R89: 200k; R_0603_1608Metric_Pad0.98x0.95mm_HandSolder
R90: 301k; R_0402_1005Metric
R100: 0; R_0805_2012Metric
R104, R107, R115, R121: 402k; R_0603_1608Metric
R109, R110: 6.04k; R_0402_1005Metric_Pad0.72x0.64mm_HandSolder
R111, R117: 100; R_0402_1005Metric_Pad0.72x0.64mm_HandSolder
R112, R118: 2.2; R_0805_2012Metric
R114: 10; R_0402_1005Metric_Pad0.72x0.64mm_HandSolder
R116: 174k; R_0402_1005Metric_Pad0.72x0.64mm_HandSolder
R122: 101k; R_0805_2012Metric_Pad1.20x1.40mm_HandSolder
R123, R124: 1k; R_0402_1005Metric_Pad0.72x0.64mm_HandSolder
R125: 86.6k; R_0402_1005Metric
R126: 3.92k; R_0402_1005Metric
R127: 27.4k; R_0402_1005Metric
R128: 549; R_0402_1005Metric_Pad0.72x0.64mm_HandSolder
R129: 280k; R_0603_1608Metric
RN1: 10k; R_Array_Concave_4x0402
SW1: ESP_RESET; SW_Push_SPST_NO_Alps_SKRK
SW2: BOOT; SW_Push_SPST_NO_Alps_SKRK
SW3: RESET; SW_Push_SPST_NO_Alps_SKRK
SW4: RESET_GNSS; SW_Push_SPST_NO_Alps_SKRK
SW5: SAFEBOOT_GNSS; SW_Push_SPST_NO_Alps_SKRK
TH1, TH2, TH3, TH4, TH5: 10k; R_0603_1608Metric
TP1: R_SENSE_SHUNT; TestPoint_2Pads_Pitch2.54mm_Drill0.8mm
TP2: IN_CP; TestPoint_2Pads_Pitch2.54mm_Drill0.8mm
TP3: REG3; TestPoint_Pad_D1.0mm
TP4: PPHV; TestPoint_2Pads_Pitch2.54mm_Drill0.8mm
TP5: CS_GPS; TestPoint_2Pads_Pitch2.54mm_Drill0.8mm
TP6: SYNC_1; TestPoint_2Pads_Pitch2.54mm_Drill0.8mm
TP7: EN_3V3; TestPoint_Pad_D1.0mm
TP8, TP9: VSYS; TestPoint_2Pads_Pitch2.54mm_Drill0.8mm
TP10, TP11: PGOOD; TestPoint_Pad_D1.5mm
TP12: 3V3; TestPoint_2Pads_Pitch2.54mm_Drill0.8mm
TP13: 5V_RAW; TestPoint_2Pads_Pitch2.54mm_Drill0.8mm
TP14: 5V; TestPoint_2Pads_Pitch2.54mm_Drill0.8mm
TP15: GPIO_EXP_RESET; TestPoint_Pad_D1.5mm
TP16: SYNC_2; TestPoint_2Pads_Pitch2.54mm_Drill0.8mm
U1: ESP32-S3-WROOM-1-N16R8; ESP32-S3-WROOM-1
U2: QMC6309; X1-WLB0808-4_L0.8-W0.8-P0.40-TL
U3: TVS2200DRV; WSON-6-1EP_2x2mm_P0.65mm_EP1x1.6mm
U4: TPD8S300A; WQFN-20_L3.0-W3.0-P0.40-TL-EP1.7
U5: TPS25751DREFR; Texas_REF0038A_WQFN-38-2EP_6x4mm_P0.4
U6, U23: TPS22945DCKR; SOT-353_SC-70-5
U7: MAX17320G22+; QFN-24_L4.0-W4.0-P0.50-BL-EP2.6
U8: BQ25798; Texas_RQM0029A_VQFN-29_4x4mm_P0.4mm
U9: NEO-F10N; ublox_NEO
U10: TPS7A2033PDBVR; SOT-23-5_L2.9-W1.6-P0.95-LS2.8-BR
U11: TPS259474LRPWR; VQFN-10_L2.0-W2.0-P0.45-TL
U12: E22P-915M30S; COMM-SMD_22P-P2.54-L38.5-W24.0_E22-400M33S
U13, U14: LM61460AASQRJRRQ1; VQFN-14-HR_L4.0-W3.5-TL_LM61460AASQRJRRQ1
U15: TPS259474ARPWR; VQFN-10_L2.0-W2.0-P0.45-TL
U16: SN74LVC1G74; X2SON-8_1.4x1mm_P0.35mm
U17: TCAL9539RTWRQ1; TQFN-24_L4.0-W4.0-P0.50-BL-EP2.3
U18, U20: WS2816B; LED-SMD_6P-L5.0-W5.0-TL
U19: SN74LV1T34DCK; SOT-353_SC-70-5
U21: M24512-DFMC6TG; DFN-8-1EP_3x2mm_P0.5mm_EP1.36x1.46mm
U22: LSM6DSV16X; LGA-14_3x2.5mm_P0.5mm_LayoutBorder3x4y
U24: TPD2E2U06QDCKRQ1; SOT-323_SC-70
Y1: 32.768kHz; Crystal_SMD_3215-2Pin_3.2x1.5mm
Y2: SX1M4.000M10F30TNN; Oscillator_SMD_SiT_PQFN-4Pin_2.0x1.6mm

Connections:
3V3_GNSS: C99.1, C100.1, C110.2, C111.1, D14.1 (A1), JP10.2 (C), JP13.2 (B), R67.1, R70.1, R76.1, R90.2, R91.1, R136.2, U9.23 (VCC), U11.6 (OUT)
+3V3: C1.1, C2.1, C3.1, C10.1, C11.1, C17.1, C38.1, C39.1, C121.2, C140.1, C144.1, C147.1, C163.1, C164.1, C176.1, C181.2, C183.1, C185.1, C190.2, C191.2, C192.2, C193.1, D4.2 (A), D15.2 (A), D27.2 (A), F1.2, F2.2, F7.2, JP3.2 (B), JP4.2 (B), JP5.2 (B), JP13.1 (A), L4.2, R7.1, R9.1, R24.2, R25.2, R93.1, R96.1, R102.1, R113.1, R114.2, R115.2, R119.1, R123.1, R131.2, R132.1, R133.2, TP12.2, U1.2 (3V3), U2.B1 (VDD), U5.38 (VIN_3V3), U16.6 (~CLR), U16.7 (~PRE), U16.8 (VCC), U17.21 (VCC), U22.5 (VDDIO), U22.8 (VDD), U22.12 (CS), Y2.4 (VDD)
+3V3_EXT: C8.1, C9.1, C142.1, J4.1, J16.1, U23.1 (VOUT)
+5V: C12.1, C16.1, C40.1, C41.1, C165.1, C166.1, C168.1, C169.1, C170.2, C171.2, C178.1, C179.2, C180.1, D20.1 (A1), F6.1, JP12.1 (A), JP17.2 (B), R100.1, R129.2, R134.2, TP14.2, U5.34 (PP5V), U15.6 (OUT), U18.2 (VCC), U19.5 (VCC), U20.2 (VCC)
+BATT: C48.1, C54.1, C61.1, D5.1 (A1), F5.2, Q5.1 (S), Q5.2 (S), Q5.3 (S)
+PACK: C61.2, C66.1, C67.1, C68.1, C69.1, C70.1, Q6.1 (S), Q6.2 (S), Q6.3 (S), Q11.5 (D), R45.2, R47.2, R63.2
-BATT: C47.2, C48.2, C50.2, C51.2, C52.2, C55.1, C56.1, C58.1, C66.2, C98.2, C105.2, C132.2, D5.2 (A2), D6.2 (A), D23.1 (A), Q16.1 (S), Q16.2 (S), Q16.3 (S), R41.1, R43.2, R46.1, TH1.2, TH2.2, TH3.2, TH4.2, TP1.1, U7.20 (GND), U7.25 (EP)
/BMS/BMS_IN: C52.1, C53.1, D23.2 (K), R42.2, TP2.1, U7.1 (IN)
/Charger/ACDRV1: R57.2, U8.11 (ACDRV1)
/Charger/ACDRV2: R61.2, U8.10 (ACDRV2)
/Charger/PMID: C80.1, C82.2, C86.2, C87.2, C88.2, U8.29 (PMID)
/Charger/REGN: C78.2, R51.2, R54.1, U8.5 (REGN)
/Root/BOOT: R6.2, R7.2, U1.27 (IO0)
/Root/Connectors/CS_BUS_RAW: D1.5 (I/O4), J1.6, R4.2
/Root/Connectors/I2C_HOST_SCL_RAW: D26.1 (I/O1), D26.5 (I/O4), J2.4, R60.2
/Root/Connectors/I2C_HOST_SDA_RAW: D26.3 (I/O2), D26.4 (I/O3), J2.3, R23.2
/Root/Connectors/MISO_RAW: D1.4 (I/O3), J1.5, R3.2
/Root/Connectors/MOSI_RAW: D1.3 (I/O2), J1.4, R2.2
/Root/Connectors/SCK_RAW: D1.1 (I/O1), J1.3, R1.2
/Root/Connectors/UART0_RX_RAW: D3.3 (I/O2), D3.4 (I/O3), J6.3, R17.2
/Root/Connectors/UART0_TX_RAW: D3.1 (I/O1), D3.5 (I/O4), J6.2, R16.2
/Root/EN: R5.2, R9.2, U1.3 (EN)
/Root/GNSS/D_SEL: JP11.2 (C), U9.2 (D_SEL/(F10:NC))
/Root/GNSS/EXTINT: R53.2, U9.4 (EXTINT)
/Root/GNSS/LNA_EN: R78.1, U9.14 (LNA_EN)
/Root/GNSS/RXD/SPI_MOSI: R50.2, U9.21 (RXD/SPI_MOSI)
/Root/GNSS/SCL/SPI_CLK: JP2.2 (B), R72.2, U9.19 (SCL/SPI_CLK/(F10:NC))
/Root/GNSS/SDA/SPI_CS: JP1.2 (B), R68.2, TP5.2, U9.18 (SDA/~SPI_CS/(F10:NC))
/Root/GNSS/VCC_RF: C107.2, D16.2 (A), U9.9 (VCC_RF)
/Root/GPIO_3: R71.1, U1.15 (IO3), U9.3 (TIMEPULSE)
/Root/GPIO_4: U1.4 (IO4), U12.13 (DIO1)
/Root/GPIO_5: J5.1, U1.5 (IO5)
/Root/GPIO_6: J5.2, R26.1, U1.6 (IO6)
/Root/GPIO_10: R96.2, U1.18 (IO10), U12.19 (NSS)
/Root/GPIO_14: U1.22 (IO14), U12.14 (BUSY)
/Root/GPIO_17: J5.4, R24.1, U1.10 (IO17)
/Root/GPIO_18: J5.3, U1.11 (IO18)
/Root/GPIO_21: R103.1, U1.23 (IO21)
/Root/GPIO_38: R4.1, R25.1, U1.31 (IO38)
/Root/GPIO_39: R131.1, U1.32 (IO39), U15.3 (PG/AUXOFF)
/Root/GPIO_40: R19.1, U1.33 (IO40)
/Root/GPIO_41: R18.2, U1.34 (IO41)
/Root/GPIO_42: R91.2, U1.35 (IO42), U11.3 (PG/AUXOFF)
/Root/GPIO_46: U1.16 (IO46), U19.2 (A)
/Root/GPIO_47: D21.1, U1.24 (IO47)
/Root/GPIO_48: R53.1, U1.25 (IO48)
/Root/LoRa/ANT_DETECT: C112.2, Q14.1 (G), R92.1, R102.2
/Root/LoRa/EN: R18.1, R94.2, R101.1, U12.6 (EN)
/Root/LoRa/LORA_ANT: C115.1, U12.21 (ANT)
/Root/LoRa/RESET: C116.1, R19.2, U12.15 (NRST)
/Root/P07: R136.1, U6.3 (OC), U17.8 (P07)
/Root/P16: D21.2, R113.2, TP10.1 (1_1), U13.5 (PGOOD), U17.16
/Root/P17: D22.3 (K), R119.2, TP11.1 (1_1), U14.5 (PGOOD), U17.17
/Root/Peripherals/LED_BDO: J15.3, U20.1 (BO), U24.2
/Root/Peripherals/LED_DO: J15.2, U20.3 (DO), U24.1
/Root/Peripherals/P00: J14.1, U17.1 (P00)
/Root/Peripherals/P01: J14.3, U17.2 (P01)
/Root/Peripherals/P02: J14.5, U17.3 (P02)
/Root/Peripherals/P03: J14.7, U17.4 (P03)
/Root/Peripherals/P04: J14.9, U17.5 (P04)
/Root/Peripherals/P05: J14.11, U17.6 (P05)
/Root/Peripherals/P06: J14.13, U17.7 (P06)
/Root/Peripherals/P10: J14.2, U17.10
/Root/Peripherals/P11: J14.4, U17.11
/Root/Peripherals/P12: J14.6, U17.12
/Root/Peripherals/P13: J14.8, U17.13
/Root/Peripherals/P14: J14.10, U17.14
/Root/Peripherals/P15: U17.15, U22.4 (INT1)
/Root/Peripherals/RESET_IOEXP: R133.1, TP15.1 (1_1), U17.24 (~RESET)
/Root/Rails/5V_RAW: C155.1, C156.2, C157.1, C167.2, C186.1, C187.2, JP17.1 (A), L5.2, R120.2, R121.2, R124.1, R125.1, TP13.2, U15.5 (IN)
/Root/Rails/SYNC_1: C159.1, Q15.3 (D), R107.2, R108.1, TP6.2, U14.7 (EN/SYNC)
/Root/Rails/SYNC_2: C160.1, JP16.1 (A), TP16.2, U13.7 (EN/SYNC)
/USB Interface/CC1: C36.1, U4.12 (CC1), U5.28 (CC1)
/USB Interface/CC2: C33.1, U4.11 (CC2), U5.29 (CC2)
/USB Interface/C_CC1: J7.A5 (CC1), U4.4 (C_CC1), U4.7 (RPD_G1)
/USB Interface/C_CC2: J7.B5 (CC2), U4.5 (C_CC2), U4.6 (RPD_G2)
/USB Interface/C_SBU1: J7.A8 (SBU1), U4.1 (C_SBU1)
/USB Interface/C_SBU2: J7.B8 (SBU2), U4.2 (C_SBU2)
/USB Interface/FAULT: R27.2, U4.9 (~FLT), U5.19 (GPIO3)
/USB Interface/GPIO2: Q1.1 (G), Q2.1 (G), Q3.1 (G), Q4.1 (G), U5.7 (GPIO2)
/USB Interface/SBU1: R28.2, R29.1, U4.15 (SBU1), U5.26 (GPIO4/USB_P/LD1)
/USB Interface/SBU2: R30.2, R31.1, U4.14 (SBU2), U5.27 (GPIO5/USB_N/LD2)
/USB Interface/WC: JP6.2 (C), U21.7 (WC)
CHG_VBUS: C35.1, C71.2, C72.2, C73.2, C74.2, Q8.3 (D), Q9.3 (D), U8.2 (VBUS), U8.3 (VBUS)
C_USB_B_N: J7.B7 (D-), NT1.3, U4.16 (D4)
C_USB_B_P: J7.B6 (D+), NT2.3, U4.17 (D3)
C_USB_T_N: J7.A7 (D-), NT1.1, U4.19 (D2)
C_USB_T_P: J7.A6 (D+), NT2.1, U4.20 (D1)
GND: BT3.2 (-), C1.2, C2.2, C3.2, C4.2, C5.1, C6.2, C7.1, C8.2, C9.2, C10.2, C11.2, C12.2, C13.2, C14.2, C16.2, C17.2, C18.1, C19.2, C20.2, C21.2, C22.2, C23.2, C24.2, C25.1, C26.2, C27.2, C28.1, C29.2, C30.2, C31.1, C32.2, C33.2, C34.2, C35.2, C36.2, C37.2, C38.2, C39.2, C40.2, C41.2, C42.2, C43.2, C44.2, C45.2, C46.1, C57.1, C59.1, C60.1, C62.2, C63.1, C64.2, C65.1, C67.2, C68.2, C69.2, C70.2, C71.1, C72.1, C73.1, C74.1, C77.2, C78.1, C79.2, C80.2, C81.2, C82.1, C83.2, C84.1, C85.1, C86.1, C87.1, C88.1, C89.2, C90.2, C92.2, C93.2, C94.2, C96.2, C97.2, C99.2, C100.2, C101.2, C102.1, C103.1, C104.2, C106.1, C107.1, C108.2, C109.1, C110.1, C111.2, C112.1, C113.2, C114.2, C116.2, C117.2, C118.2, C119.2, C120.2, C121.1, C122.1, C123.1, C124.1, C125.2, C126.1, C127.1, C128.1, C129.2, C130.2, C133.2, C134.2, C135.1, C137.2, C138.2, C139.2, C140.2, C141.2, C142.2, C143.1, C144.2, C145.1, C147.2, C155.2, C156.1, C157.2, C161.1, C162.1, C163.2, C164.2, C165.2, C166.2, C167.1, C168.2, C169.2, C170.1, C171.1, C176.2, C177.2, C178.2, C179.1, C180.2, C181.1, C182.1, C183.2, C184.2, C185.2, C186.2, C187.1, C188.2, C189.2, C190.1, C191.1, C192.1, C193.2, D1.2 (GND), D2.2 (GND), D3.2 (GND), D7.1 (GND), D7.2 (GND), D7.3 (GND), D7.7 (GND), D9.2 (A), D10.1 (A1), D11.1 (K), D12.1 (K), D13.2 (A2), D14.2 (A2), D17.2 (A2), D18.1 (A1), D19.1 (A1), D20.2 (A2), D26.2 (GND), D28.2 (GND), D29.2 (GND), FL1.2, FL1.3, FL1.5, FL2.1 (GND), FL2.3 (GND), FL2.5 (GND), FL2.7 (GND), H1.1 (1_1), H2.1 (1_1), H3.1 (1_1), H4.1 (1_1), J1.2, J2.1, J3.3, J4.2, J5.7, J5.MP (MountPin), J6.1, J7.A1 (GND), J7.A12 (GND), J7.B1 (GND), J7.B12 (GND), J7.SH (SHIELD), J10.2, J11.2 (Ext), J12.2 (Ext), J13.2 (Ext), J14.12, J14.14, J14.16, J15.4, J15.MP (MountPin), J16.2, JP11.3 (B), JP15.1 (A), L6.2, L7.2, Q2.2 (S), Q4.2 (S), Q15.2 (S), R26.2, R34.2, R41.4, R52.1, R55.2, R56.1, R58.1, R79.1, R80.1, R83.1, R86.2, R87.2, R88.1, R89.1, R101.2, R105.2, R106.2, R108.2, R109.1, R110.1, R116.1, R122.1, R127.2, R128.2, R130.2, RN1.1 (R1.1), RN1.2 (R2.1), RN1.3 (R3.1), RN1.4 (R4.1), SW1.1, SW2.1, SW3.1, SW4.1, SW5.1, TH5.2, TP1.2, TP4.1, TP5.1, TP6.1, TP8.2, TP9.2, TP12.1, TP13.1, TP14.1, TP16.1, U1.1 (GND), U1.40 (GND), U1.41 (GND), U2.A1 (VSS), U3.1 (GND), U3.2 (GND), U3.3 (GND), U3.7 (GND), U4.8 (GND), U4.13 (GND), U4.18 (GND), U4.21 (EP), U5.3 (ADCIN2), U5.5 (GPIO0), U5.6 (GPIO1), U5.11 (GND), U5.12 (GND), U5.13 (GPIO11), U5.14 (GND), U5.31 (GND), U5.36 (GPIO7), U5.37 (GPIO6), U5.39 (GND), U6.2 (GND), U8.27 (GND), U9.7 (VDD_USB), U9.10 (GND), U9.12 (GND), U9.13 (GND), U9.24 (GND), U10.2 (GND), U11.8 (GND), U12.1 (GND), U12.2 (GND), U12.3 (GND), U12.4 (GND), U12.5 (GND), U12.11 (GND), U12.12 (GND), U12.20 (GND), U12.22 (GND), U13.3 (AGND), U13.9 (PGND1), U13.11 (PGND2), U14.3 (AGND), U14.9 (PGND1), U14.11 (PGND2), U15.8 (GND), U16.4 (GND), U17.9 (GND), U17.18 (A0), U17.23 (A1), U17.25 (EP), U18.5 (GND), U18.6 (BI), U19.3 (GND), U20.5 (GND), U21.4 (GND), U21.9 (EP), U22.1 (SDO/SA0), U22.2 (SDX), U22.3 (SCX), U22.6 (GND), U22.7 (GND), U23.2 (GND), U24.3, Y2.2 (GND)
GPS_ANT: R81.2, R83.2, U9.11 (RF_IN)
I2C_HOST_IRQ: R20.1, U1.7 (IO7), U5.10 (~I2Ct_IRQ), U7.7 (ALRT), U17.22 (~INT)
I2C_HOST_SCL: D2.1 (I/O1), D28.1 (I/O1), D28.5 (I/O4), D29.1 (I/O1), D29.5 (I/O4), J3.4, J4.3, J16.3, JP2.1 (A), R22.1, R60.1, U1.17 (IO9), U2.A2 (SCL), U5.9 (I2Ct_SCL), U7.8 (SCL/DOD), U17.19 (SCL), U22.13 (SCL)
I2C_HOST_SDA: D2.3 (I/O2), D28.3 (I/O2), D28.4 (I/O3), D29.3 (I/O2), D29.4 (I/O3), J3.2, J4.4, J16.4, JP1.1 (A), R21.1, R23.1, U1.12 (IO8), U2.B2 (SDA), U5.8 (I2Ct_SDA), U7.9 (SDA/DQ), U17.20 (SDA), U22.14 (SDA)
I2C_PMIC_IRQ: R35.2, U5.18 (~I2Cc_IRQ), U8.21 (~INT)
I2C_PMIC_SCL: R32.1, R36.2, U5.17 (I2Cc_SCL), U8.14 (SCL), U21.6 (SCL)
I2C_PMIC_SDA: R33.1, R37.2, U5.16 (I2Cc_SDA), U8.15 (SDA), U21.5 (SDA)
MISO: R3.1, R98.1, U1.21 (IO13)
MOSI: J5.6, R2.1, R10.1, U12.17 (MOSI)
unnamed: BT1.1 (+), F5.1, J9.2, R40.1, R42.1, R135.2
unnamed: BT1.2 (-), BT2.1 (+), R39.1
unnamed: BT2.2 (-), J9.1, Q16.5 (D), Q16.6 (D), Q16.7 (D), Q16.8 (D), Q16.9 (D)
unnamed: C5.2, R6.1, SW2.2
unnamed: C6.1, R8.2, R12.1, Y1.1
unnamed: C7.2, R8.1, R13.1, Y1.2
unnamed: C62.1, R49.2
unnamed: C79.1, R62.2
unnamed: C81.1, R64.2
unnamed: C83.1, R65.2
unnamed: C84.2, C85.2, Q11.1 (S), Q11.2 (S), Q11.3 (S), U8.22 (BAT), U8.23 (BAT)
unnamed: C93.1, C94.1, L2.2, R74.1
unnamed: C95.1, C96.1, R75.1
unnamed: C95.2, L2.1, R69.2, R73.2
unnamed: C97.1, FL1.1, L6.1, R75.2
unnamed: C133.1, R112.2
unnamed: C139.1, R118.2
unnamed: C153.1, R123.2
unnamed: C158.1, R124.2
unnamed: C182.2, R5.1, SW1.2
unnamed: D4.1 (K), F4.2
unnamed: D6.1 (K), Q16.4 (G), R135.1
unnamed: D8.1 (K), R66.1
unnamed: D10.2 (A2), J11.1 (In), R69.1
unnamed: D11.2 (A), R70.2
unnamed: D12.2 (A), R71.2
unnamed: D13.1 (A1), J12.1 (In), R73.1
unnamed: D15.1 (K), R82.1
unnamed: D16.1 (K), JP12.3 (B)
unnamed: C106.2, C130.1, D17.1 (A1), R84.1, R85.1, U10.5 (OUT), U11.5 (IN)
unnamed: C113.1, D18.2 (A2), J13.1 (In), L3.2, R95.1
unnamed: C117.1, C118.1, C119.1, C120.1, D19.2 (A2), R100.2, U12.9 (VCC), U12.10 (VCC)
unnamed: D21.3, D22.1 (A), R132.2, Y2.1 (~ST)
unnamed: C49.2, C50.1, D23.3 (COM), R39.2, U7.21 (CELL1)
unnamed: D24.2 (A), Q7.1 (S), Q8.1 (S)
unnamed: D24.1 (K), Q7.2 (G), Q8.2 (G), R57.1
unnamed: D25.2 (A), Q9.2 (S), Q10.2 (S)
unnamed: D25.1 (K), Q9.1 (G), Q10.1 (G), R61.1
unnamed: C4.1, D27.1 (K), U23.4 (ON), U23.5 (VIN)
unnamed: FL1.4, L7.1, R80.2, R81.1
unnamed: F1.1, J1.1
unnamed: F7.1, J2.2
unnamed: F2.1, J3.1
unnamed: C13.1, C14.1, F4.1, J5.8
unnamed: J8.1, R34.1
unnamed: J8.2, R32.2
unnamed: J8.3, R33.2
unnamed: C137.1, F6.2, J15.1
unnamed: JP3.1 (A), R20.2
unnamed: JP4.1 (A), R21.2
unnamed: JP5.1 (A), R22.2
unnamed: JP6.1 (A), RN1.8 (R1.2)
unnamed: JP6.3 (B), R38.1
unnamed: JP7.1 (A), U7.5 (ZVC)
unnamed: JP7.2 (B), R47.1
unnamed: JP10.1 (A), R72.1
unnamed: JP10.3 (B), R68.1
unnamed: JP11.1 (A), R67.2
unnamed: FB1.2, JP12.2 (C)
unnamed: C114.1, FL2.4 (IO), JP14.1 (A), R95.2
unnamed: C115.2, FL2.8 (IO), JP14.2 (B)
unnamed: JP15.2 (B), Q14.2 (S)
unnamed: JP16.3 (B), TP7.1 (1_1)
unnamed: JP16.2 (C), R104.2, R105.1
unnamed: L3.1, R92.2
unnamed: Q1.3 (D), R28.1
unnamed: Q2.3 (D), R29.2
unnamed: Q3.3 (D), R30.1
unnamed: Q4.3 (D), R31.2
unnamed: Q5.5 (D), Q5.6 (D), Q5.7 (D), Q5.8 (D), Q6.5 (D), Q6.6 (D), Q6.7 (D), Q6.8 (D)
unnamed: C54.2, Q5.4 (G), R44.2
unnamed: Q6.4 (G), R48.2
unnamed: Q11.4 (G), U8.24 (SDRV)
unnamed: Q14.3 (D), R99.2, U12.7 (T/RCTRL)
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

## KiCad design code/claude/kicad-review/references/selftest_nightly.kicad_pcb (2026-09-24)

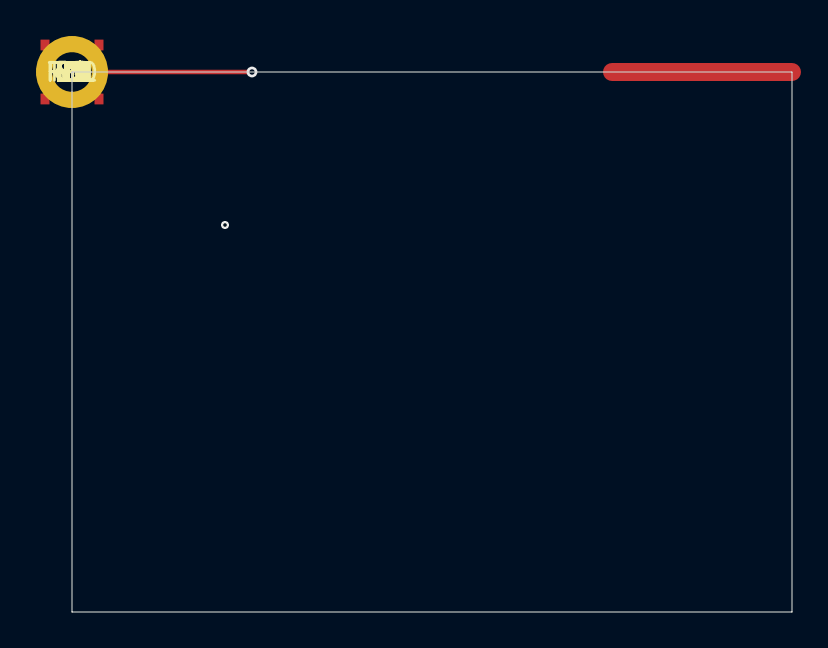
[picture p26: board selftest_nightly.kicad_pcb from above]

Board: 2 copper layers, 40.0 x 30.0 mm, 20 parts (1 on the bottom side), 3 nets.

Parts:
C1: 100nF; FP
C2: 1uF; FP
C9: 10k; FP
D1: LED; FP
H1: MountingHole; MountingHole_2.2mm_M2_DIN965_Pad
J1, J3: HDR; PinHeader_1x02_P2.54mm_Vertical
J2: Conn_Coaxial; U.FL_Hirose_U.FL-R-SMT-1_Vertical
L1: 2.2uH; L_4x4mm
R1, R2, R9, R10, R11: 10k; FP
R3: 1k; FP
R4, R5: 0R; FP
TP1: TP; TestPoint_Pad_D1.5mm
U1: MCU_OK; FP
Y1: 32.768kHz; Crystal_SMD_3215-2Pin_3.2x1.5mm

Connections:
+3V3: C1.1, U1.1 (VDD)
GND: C1.2, C2.2, D1.2, J2.2, TP1.1, U1.2 (GND)
NB: R1.2, R2.1

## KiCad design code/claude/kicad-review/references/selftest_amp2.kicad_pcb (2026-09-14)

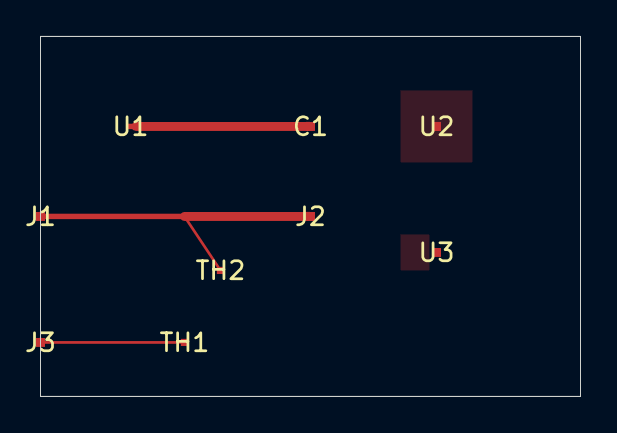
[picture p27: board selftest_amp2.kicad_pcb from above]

Board: 2 copper layers, 30.0 x 20.0 mm, 9 parts (0 on the bottom side), 3 nets.

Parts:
C1: 10uF; FP
J1, J2, J3: HDR; FP
TH1, TH2: NTC10K; FP
U1: FINEPITCH; FP
U2: COVERED; FP
U3: GAPPED; FP

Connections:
ALLTAP: J3.1, TH1.1
NECK: C1.1, U1.1
TAP: J1.1, J2.1, TH2.1

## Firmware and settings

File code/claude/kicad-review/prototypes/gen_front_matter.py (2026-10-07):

#!/usr/bin/env python3
"""PROTOTYPE (2026-10-03, parsnip-specific, see SKILL-BACKLOG "front matter").
Front matter for parsnip-node: cover (p1), block diagram (p2), power tree (p3).
Conventions follow the NXP i.MX8M EVK and BeaglePlay schematic sets: cover with
page list + revision history + notes, MCU-centred block diagram, colour-per-rail
power tree. Every refdes/value was checked with knet on 2026-10-03.
Usage: gen_front_matter.py PROJECT_DIR   (writes overview/block_diagram/power_tree.kicad_sch)"""
import os, sys, uuid

D = sys.argv[1]
GRAY = (225, 225, 225)
RAIL = {'vbus': (220, 110, 0), 'solar': (190, 150, 0), 'vsys': (200, 0, 0),
        'bat': (130, 70, 20), '5v': (180, 0, 180), '3v3': (0, 90, 220),
        'gnss': (0, 140, 60), 'clk': (110, 110, 110)}


class Sheet:
    def __init__(self):
        self.out = []
        self.oy = 0  # y offset applied to everything drawn after it is set

    def add(self, s):
        self.out.append(s)

    # -- primitives
    def text(self, x, y, s, size=1.27, bold=False, italic=False, justify=None, page=None, angle=0):
        f = f'(font (size {size} {size})' + (' (bold yes)' if bold else '') + (' (italic yes)' if italic else '') + ')'
        j = f' (justify {justify})' if justify else ''
        h = f' (href "#{page}")' if page else ''
        self.add(f'(text {q(s)} (exclude_from_sim no) (at {x} {round(y + self.oy, 3)} {angle}) (effects {f}{j}{h}) {u()})')

    def rect(self, x, y, w, h, width=0.25, dash=False, fill=None):
        f = f'(fill (type color) (color {fill[0]} {fill[1]} {fill[2]} 1))' if fill else '(fill (type none))'
        self.add(f'(rectangle (start {x} {round(y + self.oy, 3)}) (end {x + w} {round(y + h + self.oy, 3)}) {stroke(width, "dash" if dash else "solid")} {f} {u()})')

    def line(self, pts, col=None, w=0.25, dash=False, end=False, start=False):
        pts = [(x, round(y + self.oy, 3)) for x, y in pts]
        xy = ' '.join(f'(xy {x} {y})' for x, y in pts)
        self.add(f'(polyline (pts {xy}) {stroke(w, "dash" if dash else "solid", col)} (fill (type none)) {u()})')
        if end:
            self.head(pts[-2], pts[-1], col)
        if start:
            self.head(pts[1], pts[0], col)

    def head(self, a, b, col, L=1.6, W=0.6):
        (ax, ay), (bx, by) = a, b
        n = ((bx - ax) ** 2 + (by - ay) ** 2) ** 0.5
        dx, dy = (bx - ax) / n, (by - ay) / n
        p1 = (round(bx - L * dx - W * dy, 3), round(by - L * dy + W * dx, 3))
        p2 = (round(bx - L * dx + W * dy, 3), round(by - L * dy - W * dx, 3))
        fill = f'(fill (type color) (color {col[0]} {col[1]} {col[2]} 1))' if col else '(fill (type outline))'
        self.add(f'(polyline (pts (xy {bx} {by}) (xy {p1[0]} {p1[1]}) (xy {p2[0]} {p2[1]}) (xy {bx} {by})) '
                 f'{stroke(0.1, "solid", col)} {fill} {u()})')

    def dot(self, x, y, col=None, r=0.5):
        fill = f'(fill (type color) (color {col[0]} {col[1]} {col[2]} 1))' if col else '(fill (type outline))'
        self.add(f'(circle (center {x} {round(y + self.oy, 3)}) (radius {r}) {stroke(0.1, "solid", col)} {fill} {u()})')

    def block(self, x, y, w, h, lines, page=None, fill=None, width=0.25, dash=False, size=1.27):
        """Box with centred lines: first bold (function), the rest plain."""
        self.rect(x, y, w, h, width, dash, fill)
        pitch = size * 1.75
        y0 = y + h / 2 - pitch * (len(lines) - 1) / 2
        for i, s in enumerate(lines):
            self.text(round(x + w / 2, 3), round(y0 + i * pitch, 3), s, size if i else size + 0.1,
                      bold=(i == 0), page=page if i == 0 else None)

    def antenna(self, x, y, label):
        """Antenna glyph; (x, y) is the feed point."""
        self.line([(x, y), (x, y - 5)])
        self.line([(x, y - 5), (x - 2, y - 8.5), (x + 2, y - 8.5), (x, y - 5)])
        self.text(x, y + 2.2, label, 1.0)

    def table(self, x, y, widths, heights, rows, header_size=1.27, size=1.27, hrefs=None):
        cells = []
        cy = y + self.oy
        for r, (row, h) in enumerate(zip(rows, heights)):
            cx = x
            for c, (s, w) in enumerate(zip(row, widths)):
                f = f'(font (size {header_size if r == 0 else size} {header_size if r == 0 else size})' + \
                    (' (bold yes)' if r == 0 else '') + ')'
                href = f' (href "#{hrefs[r]}")' if hrefs and hrefs[r] else ''
                cells.append(f'(table_cell {q(s)} (exclude_from_sim no) (at {cx} {cy} 0) (size {w} {h}) '
                             f'(margins 0.95 0.95 0.95 0.95) (span 1 1) (fill (type none)) '
                             f'(effects {f} (justify left){href}) {u()})')
                cx += w
            cy += h
        self.add(f'(table (column_count {len(widths)}) '
                 f'(border (external yes) (header yes) {stroke(0.3)}) '
                 f'(separators (rows yes) (cols yes) {stroke(0.15)}) '
                 f'(column_widths {" ".join(map(str, widths))}) (row_heights {" ".join(map(str, heights))}) '
                 f'{u()} (cells {" ".join(cells)}))')

    def write(self, name, title, page):
        path = os.path.join(D, name)
        tail = ''
        if os.path.exists(path):
            src = open(path).read()
            head = src[:src.index('(title_block')]
            head = head.replace('(paper "A3")', '(paper "A4")')
            if '(embedded_fonts no)' in src:   # project-wide flag, kept by the first top-level sheet
                tail = '\t(embedded_fonts no)\n'
        else:
            head = (f'(kicad_sch\n\t(version 20260830)\n\t(generator "eeschema")\n\t(generator_version "10.99")\n'
                    f'\t(uuid "{uuid.uuid4()}")\n\t(paper "A4")\n\t')
        tb = (f'(title_block\n\t\t(title {q(title)})\n\t\t(date "${{DATE}}")\n\t\t(rev "${{REV}}")\n'
              f'\t\t(company "LimesKey")\n\t)\n\t(lib_symbols)\n\t')
        body = '\n\t'.join(self.out)
        open(path, 'w').write(head + tb + body + f'\n\t(sheet_instances\n\t\t(path "/"\n\t\t\t(page "{page}")\n\t\t)\n\t)\n{tail})\n')
        print(f'{len(self.out):4d} items -> {name}')


def q(s):
    return '"' + s.replace('\\', '\\\\').replace('"', '\\"').replace('\n', '\\n') + '"'


def u():
    return f'(uuid "{uuid.uuid4()}")'


def stroke(w, typ='solid', col=None):
    c = f' (color {col[0]} {col[1]} {col[2]} 1)' if col else ''
    return f'(stroke (width {w}) (type {typ}){c})'
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

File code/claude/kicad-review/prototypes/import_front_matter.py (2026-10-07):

#!/usr/bin/env python3
"""PROTOTYPE (2026-10-03, parsnip-specific, see SKILL-BACKLOG "front matter").
Import the front matter into a parsnip project dir: register Block Diagram and
Power Tree as top-level sheets 2-3, shift pages 2-10 to 4-12, set REV/DATE text
variables, then generate the three sheets with gen_front_matter.py. Run with KiCad closed."""
import json, os, subprocess, sys, uuid

D = sys.argv[1]
pro = os.path.join(D, 'parsnip.kicad_pro')
p = json.load(open(pro))
tl = p['schematic']['top_level_sheets']
assert [s['name'] for s in tl] == ['Overview', 'USB Interface', 'Charger', 'BMS', 'Root'], tl
assert p['sheets'][0][1] == 'Overview', p['sheets'][:2]
assert not p.get('text_variables'), p.get('text_variables')
assert not os.path.exists(os.path.join(D, 'block_diagram.kicad_sch'))
assert not os.path.exists(os.path.join(D, 'power_tree.kicad_sch'))

new = [{'filename': 'block_diagram.kicad_sch', 'name': 'Block Diagram', 'uuid': str(uuid.uuid4())},
       {'filename': 'power_tree.kicad_sch', 'name': 'Power Tree', 'uuid': str(uuid.uuid4())}]
p['schematic']['top_level_sheets'] = tl[:1] + new + tl[1:]
p['sheets'] = p['sheets'][:1] + [[n['uuid'], n['name']] for n in new] + p['sheets'][1:]
p['text_variables'] = {'REV': '1.1', 'DATE': '2026-10-03'}
open(pro, 'w').write(json.dumps(p, indent=2, ensure_ascii=False) + '\n')


def renum(f, pairs):
    f = os.path.join(D, f)
    t = open(f).read()
    for a, b in pairs:   # descending, so a new number never collides with an old one
        k = f'(page "{a}")'
        assert t.count(k) == 1, (f, k, t.count(k))
        t = t.replace(k, f'(page "{b}")')
    open(f, 'w').write(t)


renum('usb_interface.kicad_sch', [(2, 4)])
renum('charger.kicad_sch', [(3, 5)])
renum('bms.kicad_sch', [(4, 6)])
renum('parsnip.kicad_sch', [(10, 12), (9, 11), (8, 10), (7, 9), (6, 8), (5, 7)])
subprocess.run([sys.executable, os.path.join(os.path.dirname(os.path.abspath(__file__)), 'gen_front_matter.py'), D],
               check=True)
print('imported')

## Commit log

2026-09-07 change capacitor sizing & update footprints
    [battery.kicad_sch, gnss.kicad_sch, parsnip.kicad_pcb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]
2026-09-07 oops add this
    [usb_interface.kicad_sch]
2026-09-08 Track production fab bundle (gerbers, drill, BOM, P&P) for grant submission
    Un-ignore production/*.csv and production/*.zip via scoped negations so the
    fab outputs are committed to the repo.
    [bom.csv, designators.csv, positions.csv]
2026-09-08 small part renames in schematic + add step model
    [gnss.kicad_sch, parsnip.step]
2026-09-09 README: add ESP32-S3 GPIO pin map; update board, schematic, render
    [gnss.kicad_sch, parsnip.kicad_pcb]
2026-09-09 better track routing
    [parsnip.kicad_pcb]
2026-09-14 claude updates
    [selftest.kicad_pcb]
2026-09-14 update production files
    [bom.csv, positions.csv]
2026-09-14 assign lcsc part numbers
    [battery.kicad_sch, gnss.kicad_sch, lora.kicad_sch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]
2026-09-14 routing fixes
    [parsnip.kicad_pcb]
2026-09-14 fix ampacity false positives, add zones point-sampling, harden kdrc suppression
    kpcb.py ampacity: --net=NAME sidesteps argparse eating a dash-prefixed net
    name; TRACE-THIN now suggests the outer-layer width when the bottleneck is an
    impractical inner trace; a bridge that only isolates a thermistor/test-point/
    pull-R tap is excluded from bottleneck-picking (PAD-NECK/MIXED-NET replace
    false TRACE-THIN hits), verified against the real -BATT net and three new
    selftest fixtures.
    kpcb.py zones REF...: point-samples whether a net's fill actually covers a
    footprint's courtyard, instead of inferring it from the whole-board bbox
    table. Filters out nets whose bbox merely grazes the area without any re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
    [selftest_amp2.kicad_pcb]
2026-09-14 Update GNSS schematic to work with NEO-F10N by changing symbol & replacing SAW filter
    [gnss.kicad_sch, parsnip.kicad_pcb, parsnip.kicad_sch]
2026-09-14 update journal + plot schematic
    [gnss.kicad_sch]
2026-09-14 add photos to journal
    [gnss.kicad_sch, parsnip.kicad_pcb]
2026-09-15 docs: refresh PCB fix checklist for the GNSS NEO-F10N rework state
    Re-verified against the live board on 2026-09-15. The NEO-M9N -> NEO-F10N
    rework (5b76dbf) is mid-flight, so the doc's "fully placed, shorts gone"
    premise is stale:
    - board is 432/439 placed (7 GNSS parts unplaced, 2 duplicate footprints)
    - 15 SHORTING_ITEMS are back (C100 dup, U10, plane-via crossings)
    - DRC+ERC 425 err / 437 warn (was 381/425)
    Reworked P0 into three blockers (finish GNSS rework, clear shorts, regen the
    stale production bundle). Updated P1 counts: vias 11->4, annular 56->49,
    mask-bridge 7->22 (15 are rework artifacts), track-width 49 signal / 150
    power. Added the new RF_50OHM GNSS-path clearance, COPPER_ED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
2026-09-17 actually better routing this time
    [bom.csv, designators.csv, gnss.kicad_sch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]
2026-09-18 new part numbers for out of stock components
    [battery.kicad_sch, bom.csv, gnss.kicad_sch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]
2026-09-18 work on laptop
    [parsnip.kicad_pcb, selftest.kicad_pcb]
2026-09-18 use teardrops!
    [parsnip.kicad_pcb]
2026-09-22 backup before switching to kicad-nightly
    [battery.kicad_sch, bom.csv, designators.csv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]
2026-09-24 lots of fixes!
    [bms.kicad_sch, gnss.kicad_sch, lora.kicad_sch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]
2026-09-24 fix bug with using GDS instead of GSD FET
    [usb_interface.kicad_sch]
2026-09-24 source slightly larger inductor for higher iSAT
    [battery.kicad_sch]
2026-09-24 swap i2c labels to follow QWIIC standard
    [parsnip.kicad_sch]
2026-09-24 change magnetometer capacitance
    [parsnip.kicad_pcb, peripherals.kicad_sch, rails.kicad_sch]
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2026-09-24 clean up files
    [battery.kicad_sch, parsnip.kicad_sch, peripherals.kicad_sch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]
2026-09-24 organize part fields
    [battery.kicad_sch, bms.kicad_sch, gnss.kicad_sch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]
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2026-09-24 routing and silkscreen improvements
    [parsnip.kicad_pcb, peripherals.kicad_sch, rails.kicad_sch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]
2026-09-25 checkpoint: board/schematic state before scripted PCB fixes
    Ryan's work in progress as of 2026-09-24 23:12: Q5/Q6 SMD type, fiducials,
    U8 power-pin pours (P1-1), TH1/TH5 moved (P1-2, routing unfinished).
    Also drops docs/pcb-fix-checklist.md (merged into the gitignored docs/TODO.md).
    [parsnip.kicad_pcb, parsnip.kicad_sch]
2026-09-25 pcb: Q16 source pour, unfused pack+ spacing, hole-to-hole and small DRC fixes
    Scripted edits, each asserted as an exact match and verified with a KiCad
    refill + DRC against the pre-edit baseline (kpcb sync still IN SYNC).
    P1-3, pack return neck at Q16:
    - add B.Cu -BATT zone "Q16_SRC" (prio 30, 0.2 mm, solid) over the three source
    pads into the 1.5 mm trunk; drop the 0.60 x 3.4 mm strap it replaces
    Unfused pack positive, Net-(BT1-+) (upstream of F5):
    - remove J9's routing (DNP, blocked by BT1): its BT2- trace ran 0.12-0.13 mm
    from the BT1+ trunk and around the BT1.1 pad. J9's two pads are now unrouted.
    - In2 sense run to R42/R135: 0.9 -> 0.3 mm (sense/supply current only); every
    gap t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
    [parsnip.kicad_pcb]
2026-09-25 checkpoint: board state before scripted zone edits (00:13 save: teardrop regen + refill)
    [parsnip.kicad_pcb]
2026-09-25 pcb: zone clearance/connection tuning, drop floating BT2- copper, 2 GND stitching vias
    - Power pours CHG_VBUS, PPHV, +BATT: clearance 0.5/0.5/0.3 -> 0.2 mm and SMD pads
    solid (were thermal). CHG_VBUS fill 2 -> 14 mm2, PPHV 2 -> 6, +BATT 5 -> 8.
    - VBUS_TYPEC, LORA_5V: 0.5 -> 0.2 mm; Q7-S, 5V_ISH, GNSS_EFUSE_IN/OUT,
    BAT_CHARGER: 0.3 -> 0.2 mm. GNSS_EFUSE_OUT island removal never -> always.
    - Net-(BT2--) zone: B.Cu only. Its F.Cu/In2 fill was 13 islands with no via to
    anything (all DRC ISOLATED_COPPER).
    - GND: thermal gap 0.5 -> 0.3 mm, min width 0.25 -> 0.2 mm (STARVED_THERMAL
    18 -> 10 with the pad overrides, no new CONNECTION_WIDTH).
    - D2.2 (ESD return) and C3.2 (+3V3 decoupling) soli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
    [parsnip.kicad_pcb]
2026-09-25 pcb: layout edits after zone pass
    [parsnip.kicad_pcb]
2026-09-28 nearly set to order!
    [battery.kicad_sch, bms.kicad_sch, bom.csv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]
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2026-10-01 skills: height skips padless art
    A padless footprint with no 3D model (logo, pasted silk) is not a part:
    kpcb height listed it as NO 3D MODEL and the unnamed clipboard graphic
    over BT1 printed a blank "+ UNKNOWN from " in the Z stack.
    Golden diff (kpcb height), intended:
    - NO 3D MODEL (6) BOYKISSER J14 REF** REF**~dup U21 -> (2) J14 U21
    - "at BT1 ... + UNKNOWN from " loses the blank UNKNOWN tail
    Selftest: dup_board fixture, c_height with heights() stubbed.
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2026-10-01 skills: copper graph independent of hash seed
    kpcb_copper's tee_into joined each track as it went, and its "already
    joined at an end" test read those joins, so the order a set() yielded
    tracks (string hash seed) changed which tracks were split. On parsnip
    -BATT the graph had 255/257/258 edges by seed and `ampacity --from Q16.1
    --to R41.1` flickered by 0.1 C between identical runs; on the new fixture
    R swung 10.48 / 8.27 mohm. Splits are now decided against the union state
    from before the call, then joined.
    Golden diff (ampacity --from Q16.1 --to R41.1 --amps 6), intended - the
    formerly seed-dependent figures settle:
    - In2.Cu 0.60 x 1.08 mm 2.02 A dT ~98.1 C -> 2.01 A ~97.9 C
    - In2.Cu 0.60 x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
2026-10-01 skills: sync padless graphics as INFO
    A footprint on the board only with no pads and no sheet path (logo,
    pasted art, REF**) is INFO SYNCART, not ERROR SYNCPART, and no longer
    triggers "the board has not been re-synced". sync stays IN SYNC when
    only INFO remains; review's non-blocking count leaves INFO out.
    Golden diffs, intended:
    - sync: "1 error, 1 warn" + SYNCPART (8 refs) + re-sync banner, exit 2
    -> "0 error, 1 warn, 1 info" + SYNCART (8 incl. the blank ref), exit 0
    - review: "### STOP ... 1 error(s)" block -> "### in sync with
    parsnip-merged.net (1 non-blocking difference(s) ...)"
    Selftest: kpcb sync on the dup fixture board (3 REF** + R1).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
2026-10-01 skills: ksch ic top/bottom pin names inside the body
    s_ic drew T/B pin names with the rotate(-90) anchors inverted: names ran
    outward over their own leads (U9's VCC_RF over the U9 ref and the label
    at the lead end) and numbers went inside. Names now sit inside, numbers
    beside the lead. ic_margins() starts the L/R rows below the longest T
    name and grows the body for the longest B name (or, with no L/R pins,
    until both fit); knet draw offsets its branch rows by the same margin.
    The ic ref rises above two-digit top pin numbers.
    No golden diff (draw U7 has no T/B pins).
    Selftest: s_ic top/bottom name geometry.
    [knet.py]
2026-10-01 skills: knet draw BAT54S and R_Shunt symbols
    - Dual diodes (Diode:BAT54S/BAV99 -> d2s, BAT54A/BAW56 -> d2a,
    BAT54C/BAV70 -> d2c) and Device:R_Shunt (-> rsense) draw as the real
    ksch symbol instead of a conn box, every pin ended by its net. They take
    as many rows as their side pins and a downward label need
    (_multi_rows), counted once, at the first drawing.
    - Orientation of every drawn part now comes from where ksch puts its pins
    (_fit): near pin on the trunk, the rest away from the focal part, below
    the row and not facing up where it can. This also fixes K-first diodes
    (Device:D, Device:LED are 1=K; ksch renumbers by name and draws the
    anode first): `near == '1'` reversed the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
    [knet.py]
2026-10-01 skills: kpcb_copper mid-span crossing
    Two same-net tracks whose centrelines cross mid-span (no shared end, via
    or pad) were separate copper; KiCad merges them. Copper now splits both
    at the crossing and joins them there. An end on a body was already a tee,
    and any non-crossing overlap puts an end inside the other track, so true
    crossings were the only missing case.
    On parsnip: one crossing (/Root/RESET_DISPLAY, 31 -> 33 track pieces),
    already joined by other copper; no net's piece count changes. No golden
    diff.
    Selftest: references/selftest_cross.kicad_pcb, two tracks crossing at
    5,5: `net N` one piece, `ampacity --from J1.1 --to J2.1` R 23.17 mohm
    (hand: 2 x 7.071 mm of 0.3 x 0.035 mm).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
    [selftest_cross.kicad_pcb]
2026-10-01 skills: ksheet repeated sheet
    A hierarchical sheet file used by two sheet symbols got one sheet path
    (the first) and one ref per symbol (its Reference property), so the
    second instance's parts were unknown to ksheet/knet and its labels were
    named with the first path. SchInfo now records every (path, sheet
    symbol uuid) instance of a file and, for a file used more than once,
    takes each symbol's ref from its (instances (project (path .../UUID
    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
    [root.kicad_sch, sub.kicad_sch]
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2026-10-02 skills: kpcb check EDGEREF
    New check rule. An edge-launch footprint's Dwgs.User line + "PCB Edge"
    text (SMA, USB-C) more than 0.05 mm off the outline is a WARN with the
    move that puts it on the edge and where the nearest pad then lands vs the
    copper-to-edge clearance (Board.edge_clearance: max of .kicad_pro
    min_copper_edge_clearance and .kicad_dru edge_clearance; 0.3 here). A
    side-entry connector (Horizontal + MP pads, which sit on the mating side;
    checked on J2/J5/J6/J9/J10/J15) within --conn of an edge is an INFO with
    its Fab housing front's setback and the forward room before a pad is
    inside that clearance, WARN when a pad already is.
    Live board: J7/J11/J13 marks are now on the outline (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
2026-10-02 skills: kpcb movecheck
    New read-only command:
    - `movecheck REF X Y [ROT]`: REF's pads re-placed (rotation about the
    footprint origin) as boxes vs every foreign pad/track/via sharing a
    copper layer (through pads on all), at the net-pair clearance
    (_clearance_fn: netclasses + .kicad_dru NetName pairs), plus copper to
    edge (Board.edge_clearance) and same-side courtyard overlap. Run at
    the current spot too; only NEW hits print. REF's own tracks drag and
    are skipped; NPTH holes are not copper. Exit 2 on a new hit.
    - `movecheck REF --scan x=X y=A..B [--step 0.05]`: clear/blocked
    stretches along the line with what blocks each.
    - `movecheck via X,Y NX,NY`: the via's new hits, and wheth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
2026-10-02 skills: kpcb freebox
    New command `kpcb.py FILE freebox SIDE W H`: a 0.25 mm raster of the
    side (outside the outline / within 1 mm of it, same-side courtyards,
    every through-hole pad, that side's silk: logo art, board gr_* silk and
    visible footprint text) with a summed-area table; every centre whose
    W x H box is empty is a candidate, 4-connected candidates form regions,
    and each region reports its best-margin centre. ~0.5 s.
    Board: text_box() estimates a KiCad text's box from font size and
    (justify) (checked against the render: R30's ref 136.1-138.8 x
    155.7-156.9, the left-bottom "RESET" 132.4-139.15 x 162.6-164.4);
    Board.silk uses it for gr_text, and FP.texts holds each footprint's
    visible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
2026-10-02 skills: recipes tidy placement pass
    recipes.md gains the "tidy the placement" pass now that every command it
    names exists: sync -> check (HOLECLR/EDGECLR already catch hole hardware
    and edge issues) -> tidy -> check --only EDGEREF -> silk (freebox for a
    new spot) -> movecheck each nudge -> the user drags (D) and refills. Also
    "room for a silk box" points at freebox, and the self-test notes are
    current (68 checks, the generated boards and the two new static
    fixtures). SKILL.md's tidy line links the recipe.
    No golden diff.
2026-10-02 skills: knet PINOUT power-FET footprints
    A generic Q_[NP]MOS_xyz symbol on a footprint that numbers its pads by
    function (KiCad's VSONP/TDSON/VSON NexFET family: pad 1 = three copper
    pieces S, pad 2 = G, pad 3 = >= 4 pieces with the EP, D) must read SGD;
    otherwise PINOUT is an ERROR naming the right symbol. FPPAD could not
    see it because the pad numbers match. kcommon.fp_pads(count=True) gives
    the copper pieces per pad number.
    Repro: the session-start netlist (Q7/Q8 CSD18512Q5B on
    Transistor_FET:Q_NMOS_DGS) now reports both, D and S swapped, use
    Q_NMOS_SGD; the live netlist, where that fix is already made, is clean.
    Golden diff (knet check, frozen inputs), intended: 0 -> 2 error, the two
    Q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
    [knet.py]
2026-10-02 schematic: add D24/D25 PZU12B2L zeners, Q_NMOS_SGD symbol, misc sheet edits
    [battery.kicad_sch, gnss.kicad_sch, lora.kicad_sch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]
2026-10-03 checkpoint: schematic WIP before battery -> charger rename
    Connectors and Overview sheets, LSM6DSV16X/TPS22945/charger datasheets,
    and in-progress edits across all sheets, committed as-is so the rename
    diff stands alone.
    [battery.kicad_sch, bms.kicad_sch, connectors.kicad_sch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]
2026-10-03 schematic: rename battery.kicad_sch -> charger.kicad_sch, Overview first
    - git mv battery.kicad_sch charger.kicad_sch; the Charger sheet name and
    its UUID are unchanged, so symbol paths and footprint links are too.
    - parsnip.kicad_pro: top_level_sheets filename, and the list reordered to
    Overview, USB Interface, Charger, BMS, Root. KiCad lists top-level
    sheets in this order in the hierarchy navigator (it sorts only
    subsheets by page number).
    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
    [charger.kicad_sch, parsnip.kicad_pcb]
2026-10-03 schematic: BMS sheet shifted 2.54 mm left, U8 value label resized
    - bms.kicad_sch: whole drawing moved -2.54 mm in x (933 coordinates,
    nothing else changed).
    - charger.kicad_sch: U8 reference/value fields moved; value now 1.524 mm bold.
    - KiCad moved the project-wide (embedded_fonts no) flag from
    parsnip.kicad_sch to overview.kicad_sch, now the first top-level sheet.
    Merged netlist unchanged (462 comps / 295 nets, 0 rewires).
    [bms.kicad_sch, charger.kicad_sch, overview.kicad_sch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]
2026-10-03 schematic: front matter - cover, block diagram, power tree (pages 1-3)
    Structure follows the NXP i.MX8M EVK and BeaglePlay schematic sets.
    - overview.kicad_sch (p1): cover with page list and revision history as
    KiCad tables (rows link to their pages) and general notes.
    - block_diagram.kicad_sch (p2): ESP32-S3-centred block diagram with buses,
    control lines and I2C addresses.
    - power_tree.kicad_sch (p3): inputs, charger, bucks, eFuses and loads,
    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
    [block_diagram.kicad_sch, bms.kicad_sch, charger.kicad_sch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]
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2026-10-07 minor bug
    [charger.kicad_sch, connectors.kicad_sch, gnss.kicad_sch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]
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2026-10-07 Netclasses: label the classed nets, add missing members
    Netclass patterns keyed to KiCad's refdes-derived names (Net-(D18-A2) etc.)
    drop out of their class silently on re-annotation. Local labels now name 14
    of those nets (sheets + board renamed together; connectivity unchanged).
    - RF_50OHM: LoRa LPF in/out + SMA, GNSS SMA + bias node now by label.
    - RF_50OHM_MS: GNSS_UFL by label; width 0.30 -> 0.34 mm (50 ohm at 0.8 mm
    side clearance; 0.30 solves to 53 ohm).
    - PWR_HIGH: + CHG_VBUS, /Charger/SW1, SW2, CHG_BAT, VAC1_MID, /BMS/CELL_BOT,
    BMS FET mid (full pack / charge current, previously Default).
    - PWR_RAIL: + buck switch nodes, LORA_5V (E22P supply), SOLAR, VAC2_MID,
    LED 5V connector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
2026-10-19 kicad-review: board writers (place/route/ripup/renet/fixlines) and their checks
    kpcb gains writers that only ever write a copy (-o OUT): place (ranked spots,
    both sides, copper-checked), route (grid A* with vias and own-route rip-up,
    --pour bands), ripup --drc, renet --drop, fixlines (the 10.99 fp_line frame
    bug), plus airwires, map and pairs. kdrc gains --report/--baseline and
    --refill-save for the scratch-copy loop. Selftest 111/111, pyflakes clean.
2026-10-19 checkpoint: board as saved 2026-10-08 (kicad-nightly 4975)
    Preserves the working-tree board before it is replaced by the routed copy.
    Known damage in this save, repaired in the next board commit, so do not
    restore from it without `kpcb.py fixlines`: every footprint fp_line is stored
    in the wrong frame (a 10.99 nightly save bug), 128 netless stale tracks and
    16 vias, and ~88 tracks under parts placed after routing.
2026-10-19 board: replace with the routed copy; placement fixes and power-path pass
    Base is the ~/Downloads/temp board from the 2026-10-18 routing sessions:
    fp_line frames repaired, 128 netless stale tracks dropped, shorts ripped,
    the 16 parked parts plus F7 placed, ~1150 segments routed.
    Placement and cleanup:
    - C60/C63/C65 respaced to 2.3 mm pitch (C65 sat on C60 at 0.8 mm).
    - C90 moved to F.Cu over J10.1 (its pad was drilled by J7's NPTH peg).
    - Net-(D24-K) vs VAC1_MID 0.07 mm clearance fixed at Q8.
    - D28's GND pad was an isolated B.Cu island: P07 bent, GND via added.
    - VBUS at J7 was never connected (J7 VBUS pins, U3, C21-C23): 0.4 mm
    escapes past the peg holes, F.Cu spine under J7, C21/C22 rota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
2026-10-19 board: route 6 of the last 7 links; move D3, U22 cluster, FID2; swap P05/P15
    - D3 (UART0 ESD) moves to F.Cu under J6 (was 26.7 mm away on B.Cu); UART0
    RAW stubs now ~5 mm each (TX was 45 mm), UART0_TX/RX re-laid at ~16 mm.
    FID2 moves to 99.6,157.7 to make room.
    - U22 (LSM6DSV16X) + C183/C193 move from the boxed-in B.Cu hole under U1's
    corner to F.Cu west of U1 (100.9,152.8 r180); all their nets routed.
    - Schematic: U22 INT1 now on TCAL9539 P05, J14.11 on P15 (U17.15's west face
    has no via access). Two label renames; knet diff = 4 pins, ERC unchanged.
    - C_SBU2 (J7.B8 -> U4.2) and the J4/D28 I2C_HOST_SDA group routed.
    - KiCad DRC vs the pre-change baseline: 0 new, 1 gone; unconnected 7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
2026-10-19 board: silkscreen pass 1 (checkpoint before silk pass 2)
    refdes re-placement at 1/0.15 mm, 32 unplaceable designators hidden, POWER/GNSS
    RESET/UART0/BOOT labels fixed. Silk only: copper identical, 0 new DRC.
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
